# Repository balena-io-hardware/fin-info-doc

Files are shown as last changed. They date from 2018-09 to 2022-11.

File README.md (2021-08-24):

# balenaFin repository
Official documentation repository for the [balenaFin board](https://balenafin.io).  
Get it now from the official balenaFin [store](https://store.balena.io/).

## Directory structure

    .
    ├── documentation
    │   ├── CAD                          # 2d & 3D files for balenaFin and accessories
    │   ├── PDF                          # PDF files generated from markdown source using the builder
    │   └── markdown                     # balenaFin and accessories documentation source files
    ├── software                         # Linux config files for accessing balenaFin HW
    │   ├── dt-blob
    │   ├── overlay                      # Device tree overlay for Linux kernel
    │   └── drivers                      # Device drivers for radio, etc.
    ├── examples                         # Example code for the balenaFin
    ├── config.json                      # PDF generator files
    ├── index.js                         # PDF generator files
    └── package.json                     # PDF generator files

## Generated documentation

All files inside `documentation/CAD` and `documentation/PDF` are official balenaFin documentation. 
They are automatically generated from markdown files in `documentation/markdown`. 

## Building PDF releases

All PDF documentation is generated automatically from markdown files. To install the PDF generator, clone the repository and run `npm install`

`config.json` allows to define the document sources and their destination folder, along with custom overall styling

Once `config.json` is configured, run `npm start` to generate the PDF

### Project specific syntax

#### Page breaks

Creating a page-break on the destination PDF. 
It's important to leave a blank line above and below. 

```html

```

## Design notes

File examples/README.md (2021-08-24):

# balena-fin-examples
A collection of examples for balenaFin wrapped as a multi-container balenaCloud application. 
This collection will be improved with more examples over time, make sure to check it out from time to time!

deploy button (https://dashboard.balena-cloud.com/deploy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)

Service | What it does
------------ | ------------
wifi-connect | if the balenaFin is not connected, exposes a WiFi access point with Captive Portal ( SSID: `balenaFin`, PSK: `balenaFin`) that allows the configuration of WiFi credentials. 
For more info, please refer to the [wifi-connect repository](https://github.com/balena-io/wifi-connect)
rgb-led | blinks the balenaFin RGB LED with a random color every 3 seconds
artik020 | Loads OTA bluetooth bootloader to the Artik020 module and a sample application with BLE characteristics and the possibility to use OTA updates

## How to deploy this example to balenaCloud via git

```bash
git clone git@github.com:balena-io/balena-fin-examples.git
git remote add balena <YOUR_BALENA_USERNAME>@git.balena-cloud.com:<YOUR_BALENA_USERNAME>/<YOUR_BALENA_APP_NAME>.git
git push balena master
```
## How to deploy this example to balenaCloud via the balena CLI

1. Install [balena-cli](https://github.com/balena-io/balena-cli#standalone-install)
2. Deploy this application via [balena push](https://github.com/balena-io/balena-cli/blob/master/doc/cli.markdown#push-applicationordevice)

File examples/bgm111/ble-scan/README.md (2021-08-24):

# BLE Scan Example

Sample code to scan for advertising BLE devices and output the names of the advertisements over serial UART.

Note: this code only works with the balenaFin version v1.0.

## Contents

The firmware directory contains two files that are loaded in the Coprocessor's flash memory during set up.

`bootloader.s37` is the coprocessor bootloader. If this has not been flashed to the device beforehand, this will need to be flashed.

`ble-scan.hex` is an example that scans for advertising devices and shares them over serial UART.

To get started with this application, open the serial interface with `screen /dev/ttyUSB0 115200` and you should see the coprocessor printing out scanned BLE advertisements.

## Further Development

To develop custom applications for the coprocessor module it is recommended to download Simplicity Studio from Silicon labs website.
You can then uncompress the [ble-scan](/src/ble-scan.sls) file and import this into Simplicity Studio as a template project.

Notes:

- Make Sure you use EFR32BG1B232F256GM48 as the part number for the Artik020 module
- Make sure you use version 2.8 or newer of the `Gecko SDK Suite: Bluetooth`

### Documentation

To help aid further development here are some links to Silicon Labs documentation on the BLE SDK

- [BLE API Reference Manual](https://www.silabs.com/documents/public/reference-manuals/bluetooth-api-reference.pdf)

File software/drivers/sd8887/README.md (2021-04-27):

# SD8887 Driver and Firmware

### Information

This directory contains the source and instructions for building the wireless drivers/firmware for the sd8887 radio on the balenaFin (v1.x). The latest release of this driver is version `15.68.19.p48-15.26.19.p48` which targets the 5.4 Linux kernel.

This driver comes pre-installed under balenaOS and our custom Raspbian image for the balenaFin. The instructions below explain how to install both the driver and firmware against a standard Raspbian Lite (Stretch) image.

## Installation for Raspbian

We provide a pre-prepared [Raspbian Lite (Stretch)]() image with overlay and drivers installed, however we also provide instructions for how to install these drivers on a vanilla version of Raspbian OS. 

> :warning: Currently this driver only supports up to the 5.4 kernel. This means the driver does not support the latest version of Raspberry Pi OS (previously known as Raspbian) but we are working on it!

### Setup

1. Install latest [Raspbian Lite (Stretch)](https://downloads.raspberrypi.org/raspbian/images/raspbian-2019-04-09/2019-04-08-raspbian-stretch.zip) onto your balenaFin (v1.x). We recommend using [Etcher](https://www.balena.io/etcher/).

2. Enable `ssh` (create an `ssh` file in the `/boot` partition). 

3. Ensure that the `balena-fin` DT overlay has been set in `/boot/config.txt`. This should be included by default in the vanilla Raspbian image.

```bash
dtoverlay=balena-fin
```

4. Update, upgrade and install dependencies:
```bash 
sudo apt-get update && sudo apt-get upgrade
sudo apt-get install raspberrypi-kernel-headers build-essential bc git
```

5. Clone this repo and copy source
```bash
git clone https://github.com/balena-io-hardware/balena-fin.git
sudo cp balena-fin/software/drivers/sd8887/firmware/* /lib/firmware/nxp/
```

6. Create `/etc/modprobe.d/blacklist.conf` using the following snippet:

```bash
for mod in mwifiex mwifiex_sdio btmrvl btmrvl_sdio; do
    echo "blacklist ${mod}" >> /etc/modprobe.d/blacklist.conf
done
```

7. Reboot
 
```bash
sudo reboot now
```

### Configure NetworkManager and WiFi Connect

The WiFi Connect installation script will enable NetworkManager and install wifi-connect:

```bash
bash <(curl -L https://github.com/balena-os/wifi-connect/raw/master/scripts/raspbian-install.sh)
```

### Build WLAN driver

```bash
cd ~/balena-fin/software/drivers/sd8887/src/wlan
make -j 4 KERNELDIR=/usr/src/linux-headers-$(uname -r) build
cd ../bin_sd8887/
sudo modprobe cfg80211
sudo insmod mlan.ko
sudo insmod sd8887.ko cal_data_cfg=none drv_mode=1 sta_name=wlan ps_mode=2
```

### Verify WLAN driver is working

```bash
dmesg
sudo nmcli d wifi rescan ifname wlan0
nmcli d wifi
iw phy
iw dev
ip a
sudo wifi-connect -i wlan0
```

### Unload WLAN driver

```bash
sudo ip link set wlan0 down
sudo rmmod sd8xxx mlan
```

### Build Bluetooth driver

```bash
cd ~/balena-fin/software/drivers/sd8887/src/bluetooth
make -j 4 KERNELDIR=/usr/src/linux-headers-$(uname -r) build
cd ../bin_sd8887_bt/
sudo modprobe bluetooth
sudo insmod bt8887.ko
```

### Verify Bluetooth driver is working

```bash
sudo bluetoothctl
```

### Unload Bluetooth driver

```bash
sudo hciconfig hciX down
sudo rmmod bt8xxx
```

### Complete installation

```bash
sudo cp ~/balena-fin/software/drivers/sd8887/src/bin_sd8887/mlan.ko /lib/modules/$(uname -r)/kernel/drivers/net/wireless/nxp/mlan.ko
sudo cp ~/balena-fin/software/drivers/sd8887/src/bin_sd8887/sd8887.ko /lib/modules/$(uname -r)/kernel/drivers/net/wireless/nxp/sd8887.ko
sudo cp ~/balena-fin/software/drivers/sd8887/src/bin_sd8887_bt/bt8887.ko /lib/modules/$(uname -r)/kernel/drivers/bluetooth
sudo depmod
sudo touch /etc/modules-load.d/sd8887-nxp.conf
```

Edit `/etc/modules-load.d/sd8887-nxp.conf` like this:

```bash
mlan
sd8xxx
bt8xxx
```

Create and edit `/etc/modprobe.d/sd8887-nxp.conf` like this:

```bash
options sd8xxx cal_data_cfg=none drv_mode=1 sta_name=wlan ps_mode=2
```

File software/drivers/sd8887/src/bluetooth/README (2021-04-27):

===============================================================================
			U S E R  M A N U A L

 Copyright 2014-2020 NXP

 This software file (the File) is distributed by NXP
 under the terms of the GNU General Public License Version 2, June 1991
 (the License).  You may use, redistribute and/or modify the File in
 accordance with the terms and conditions of the License, a copy of which
 is available by writing to the Free Software Foundation, Inc.,
 51 Franklin Street, Fifth Floor, Boston, MA 02110-1301 USA or on the
 worldwide web at http://www.gnu.org/licenses/old-licenses/gpl-2.0.txt.

 THE FILE IS DISTRIBUTED AS-IS, WITHOUT WARRANTY OF ANY KIND, AND THE
 IMPLIED WARRANTIES OF MERCHANTABILITY OR FITNESS FOR A PARTICULAR PURPOSE
 ARE EXPRESSLY DISCLAIMED.  The License provides additional details about
 this warranty disclaimer.

===============================================================================

1) FOR DRIVER BUILD

	Goto source code directory mbt_src/.
		make [clean] build
	The driver binary can be found in ../bin_xxxx_bt directory.
	The driver code supports Linux kernel from 2.6.32 to 5.5.2.

2) FOR DRIVER INSTALL

	a) Copy sd8787.bin | ... to /lib/firmware/nxp/ directory,
	   create the directory if it doesn't exist.
	b) Install bluetooth driver,
		insmod bt8787.ko | mbt8787.ko | ... [fw_name=nxp/sd8xxx.bin]
	c) Uninstall bluetooth driver,
		hciconfig hciX down
		rmmod bt8xxx | mbt8xxx

	There are some other parameters for debugging purpose etc. Use modinfo to check details.
	  The bit settings of drv_mode are,
		Bit 0: BT/AMP/BLE
	  mbt_drvdbg=<bit mask of driver debug message control>
	  psmode=1|0 <enable PS mode (default) | disable PS mode>
	  dts_enable=1|0 <Disable DTS | Enable DTS (default)>
	  bt_name=<BT interface name>
	  mbt_pm_keep_power=1|0 <PM keep power in suspend (default) | PM no power in suspend>
	  fw=0|other <Skip firmware download | Download firmware (default)>
	  bt_req_fw_nowait=0|1 <use request_firmware API (default) | use request_firmware_nowait API>
	  init_cfg=<init config (MAC addresses, registers etc.) file name>
		e.g. copy bt_init_cfg.conf to firmware directory, init_cfg=nxp/bt_init_cfg.conf
      bt_mac=xx:xx:xx:xx:xx:xx <override the MAC address (in hex)>
      cal_cfg=<BT CAL data config file name>
		e.g. copy bt_cal_data.conf to firmware directory, cal_cfg=nxp/bt_cal_data.conf
      cal_cfg_ext=<CAL data config file name>
		e.g. copy cal_data.conf to firmware directory, cal_cfg_ext=nxp/cal_data.conf
      init_cmds=<init commands config file name>
		e.g. copy bt_init_cmds.conf to firmware directory, init_cmds=nxp/bt_init_cmds.conf

	  bt_fw_serial=0|1 <Support parallel download FW | Support serial download FW (default)>

	Note: On some platforms (e.g. PXA910/920) double quotation marks ("") need to used
	for module parameters.
		insmod bt8xxx.ko "<para1> <para2> ..."

3) cat /proc/mbt/hcix/status
	This command is used to get driver status.

4) cat /proc/mbt/hcix/config
	This command is used to get the current driver settings.

5) proc commands to config bluetooth parameters

mbt_drvdbg=[n]
	This command is used to set the bit mask of driver debug message control.

	bit 0:  MSG  		PRINTM(MSG,...)
	bit 1:  FATAL		PRINTM(FATAL,...)
	bit 2:  ERROR		PRINTM(ERROR,...)
	bit 3:  DATA 		PRINTM(DATA,...)
	bit 4:  CMD  		PRINTM(CMD,...)
	bit 5:  EVENT		PRINTM(EVENT,...)
	bit 6:  INTR		PRINTM(INTR,...)
	...
	bit 16: DAT_D		PRINTM(DAT_D,...), DBG_HEXDUMP(DAT_D,...)
	bit 17: CMD_D		PRINTM(CMD_D,...), DBG_HEXDUMP(CMD_D,...)
	...
	bit 28: ENTRY		PRINTM(ENTRY,...), ENTER(), LEAVE()
	bit 29: WARN 		PRINTM(WARN,...)
	bit 30: INFO 		PRINTM(INFO,...)

	Usage:
		echo "drvdbg=0x7" > /proc/mbt/hcix/config		#enable MSG,FATAL,ERROR messages

gpio_gap=[n]
	This command is used to configure the host sleep parameters.

	bit 8:0  -- Gap
	bit 16:8 -- GPIO
	where GPIO is the pin number of GPIO used to wakeup the host. It could be any valid
		GPIO pin# (e.g. 0-7) or 0xff (Interface, e.g. SDIO will be used instead).
	where Gap is the gap in milliseconds between wakeup signal and wakeup event
		or 0xff for special setting when GPIO is used to wakeup host.

	Usage:
		echo "gpio_gap=0xff80" > /proc/mbt/hcix/config   	# use Interface (e.g. SDIO)
		echo "hscfgcmd=1" > /proc/mbt/hcix/config		# gap = 0x80

		echo "gpio_gap=0x03ff" > /proc/mbt/hcix/config   	# use gpio 3
		echo "hscfgcmd=1" > /proc/mbt/hcix/config		# and special host sleep mode

psmode=[n]
	This command is used to enable/disable auto sleep mode

	where the option is:
			1 	-- Enable auto sleep mode
			0 	-- Disable auto sleep mode

	Usage:
		echo "psmode=1" > /proc/mbt/hcix/config			#enable power save mode
		echo "idle_timeout=0x0100" > /proc/mbt/hcix/config		#configure idle, timeout value in ms
		echo "pscmd=1" > /proc/mbt/hcix/config

		echo "psmode=0" > /proc/mbt/hcix/config			#disable power save mode
		echo "pscmd=1" > /proc/mbt/hcix/config

sdio_pull_cfg=[n]
	This command is used to configure the delay values for pull up and pull down the SDIO lines.

   	where value is:
	        bit 15:0  -- Pull up delay in microsecond
	        bit 31:16 -- Pull down delay in microsecond
	        0xffff disables PullUp and PullDown in BT controller

	Usage:
		echo "sdio_pull_cfg=0x00020002" > /proc/mbt/hcix/config   	# Enable sdio pull control
		echo "sdio_pull_ctrl=1" > /proc/mbt/hcix/config             # configure sdio pull up delay to 2 microseconds
                                                                    # configure sdio pull down delay to 2 microseconds

		echo "sdio_pull_cfg=0xffffffff" > /proc/mbt/hcix/config   	# Disable sdio pull control
		echo "sdio_pull_ctrl=1" > /proc/mbt/hcix/config

6) Use hcitool to issue raw hci command, refer to hcitool manual

	Usage: Hcitool cmd <ogf> <ocf> [Parameters]

	1.Interface Control Command
	  hcitool cmd 0x3f 0x5b 0xf5 0x01 0x00    --Enable All interface
	  hcitool cmd 0x3f 0x5b 0xf5 0x01 0x01    --Enable Wlan interface
	  hcitool cmd 0x3f 0x5b 0xf5 0x01 0x02    --Enable BT interface
	  hcitool cmd 0x3f 0x5b 0xf5 0x00 0x00    --Disable All interface
	  hcitool cmd 0x3f 0x5b 0xf5 0x00 0x01    --Disable Wlan interface
	  hcitool cmd 0x3f 0x5b 0xf5 0x00 0x02    --Disable BT interface

7) cat /proc/mbt/hcix/debug
	This command is used to get driver debug parameters.

8) proc command to config debug parameters

sdcmd52rw=<func> <reg> [data]
	This command is used to read/write a controller register in
	Secure Digital I/O Interfaces.

	func: The function number to use (0-7)
	reg:  The address of the register
	data: The value to write, read if the value is absent

	For SDIO MMC driver, only function 0 and BT function (2/3) access is allowed.
	And there is a limitation for function 0 write, only vendor specific CCCR
	registers (0xf0 -0xff) are permiited.

	Usage:
		echo "sdcmd52rw= 2 3 0xf" > /proc/mbt/hcix/debug	# write 0xf to func 2 address 3
		echo "sdcmd52rw= 0 4" > /proc/mbt/hcix/debug    	# read func 0 address 4

Issue debug_dump command through proc.
	Usage:
		echo "debug_dump" > /proc/mbt/hcix/debug		# dump driver internal debug status.
	Use dmesg or cat /var/log/debug to check driver debug messages.

proc command to enable BT test mode
    Usage:
        echo "test_mode=1" > /proc/mbt/hcix/config       #enable BT test mode

==============================================================================
			U S E R  M A N U A L  F O R  F M A P P

1) FOR TOOL BUILD

	a) Enter directory
	b) make
	c) After building, the executable binary "fmapp" is in the directory

2) FOR TOOL RUN

	a) chmod 777 fmapp (optional)
	b) Run fmapp utility based on usage below
		Usage: fmapp <Options> devicename ogf ocf [command content]
		devicename example: mfmchar0 /mnfccahr0
		FM ogf/ocf example: 0x3f 0x280
		NFC ogf/ocf example: 0x3f 0x281
	Options:
		-h: Display help
		-v: Verbose

3) TEST EXAMPLES
    ./fmapp mfmchar0 0x3f 0x280 0x01 0x01
    ./fmapp mnfcchar0 0x3f 0x281 0x20 0x00 0x01 0x01

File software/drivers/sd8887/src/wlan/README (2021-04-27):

===============================================================================
			U S E R  M A N U A L

 Copyright 2014-2020 NXP

1) FOR DRIVER BUILD

	Goto source code directory wlan_src/.
	make [clean] build
	The driver and utility binaries can be found in ../bin_xxxx directory.
	The driver code supports Linux kernel from 2.6.32 to 5.5.2.

2) FOR DRIVER INSTALL

	a) Copy firmware image sd8786_uapsta.bin | sd8787_uapsta.bin | ... to
	   /lib/firmware/nxp/ directory, create the directory if it doesn't exist.
	b) Install WLAN driver,
	   There are drv_mode, max_sta_bss, max_uap_bss etc. module parameters.
		The bit settings of drv_mode are,
			Bit 0 :  STA
			Bit 1 :  uAP
			Bit 2 :  WIFIDIRECT
		The default drv_mode is 7.
			Bit 4 :  NAN

		max_sta_bss: Maximum number of STA BSS (default 1, max 1)
		sta_name: Name of the STA interface (default: "mlan")
		max_uap_bss: Maximum number of uAP BSS (default 1, max 2)
		uap_name: Name of the uAP interface (default: "uap")
		uap_max_sta: Maximum number of STA for UAP/GO (default 0, max 10)
		max_wfd_bss: Maximum number of WIFIDIRECT BSS (default 1, max 1)
		wfd_name: Name of the WIFIDIRECT interface (default: "wfd")
		max_vir_bss: Number of Virtual interfaces (default 0)
		nan_name: Name of the NAN interface (default: "nan")
		max_nan_bss: Number of NAN interfaces (default 1)
	   For example, to install SD8787 driver,
		insmod mlan.ko
		insmod sd8787.ko [drv_mode=3] [fw_name=nxp/sd8787_uapsta.bin]
	   To load driver in STA only mode,
		insmod mlan.ko
		insmod sd8787.ko drv_mode=1 [fw_name=nxp/sd8787_uapsta.bin]
	   To load driver in uAP only mode,
		insmod mlan.ko
		insmod sd8787.ko drv_mode=2 [fw_name=nxp/sd8787_uapsta.bin]

	   To switch mode between STA only, uAP only and uAPSTA etc. in run time,
		echo drv_mode=1 > /proc/mwlan/config		// STA mode
		echo drv_mode=2 > /proc/mwlan/config		// uAP mode
		echo drv_mode=3 > /proc/mwlan/config		// STA+uAP mode
		echo drv_mode=7 > /proc/mwlan/config		// STA+uAP+WIFIDIRECT mode
	c) Uninstall WLAN driver,
		ifconfig mlanX down
		ifconfig uapX down
		rmmod sd8xxx
		rmmod mlan

	Use mfg_mode = 1:
	To load driver with MFG firmware file, when insmod WLAN driver and specify MFG firmware name if needed.
	This option loads default normal FW on HW reset (reset button is pressed on the board).

	Use mfg_mode = 2:
	To load driver with MFG firmware file, when insmod WLAN driver and specify MFG firmware name if needed.
	This option reloads previously specifed MFG firmware only on HW reset.

	There are some other parameters for debugging purpose etc. Use modinfo to check details.
	  drvdbg=<bit mask of driver debug message control>
	  dev_cap_mask=<Bit mask of the device capability>
	  mac_addr=xx:xx:xx:xx:xx:xx <override the MAC address (in hex)>
	  auto_ds=0|1|2 <use MLAN default | enable auto deepsleep | disable auto deepsleep>
	  ps_mode=0|1|2 <use MLAN default | enable IEEE PS mode | disable IEEE PS mode>
	  p2p_enh=0|1 <Disable enhanced P2P (default) | Enable enhanced P2P>
	  max_tx_buf=2048|4096|8192 <maximum AMSDU Tx buffer size>
	  pm_keep_power=1|0 <PM keep power in suspend (default) | PM no power in suspend>
	  shutdown_hs=1|0 <Enable HS when shutdown | No HS when shutdown (default)>
	  cfg_11d=0|1|2 <use MLAN default | enable 11d | disable 11d>
	  dts_enable=0|1 <Disable DTS | Enable DTS (default)>
	  hw_test=0|1 <Disable hardware test (default) | Enable hardware test>
	  fw_serial=0|1 <support parallel download FW | support serial download FW (default)>
	  req_fw_nowait=0|1 <use request_firmware API (default) | use request_firmware_nowait API>
	  slew_rate=0|1|2|3 <0 is the slowest slew rate and 03 has the highest slew rate (default)>
	  antcfg=0|1|2|0xffff <default | Tx/Rx antenna 1 | Tx/Rx antenna 2 | enable antenna diversity>
	  init_cfg=<init config (MAC addresses, registers etc.) file name>
		e.g. copy init_cfg.conf to firmware directory, init_cfg=nxp/init_cfg.conf
	  cal_data_cfg=<CAL data config file name>
		e.g. copy cal_data.conf to firmware directory, cal_data_cfg=nxp/cal_data.conf
	  txpwrlimit_cfg=<Tx power limit config file name>
		e.g. copy txpwrlimit_cfg_set.conf to firmware directory, txpwrlimit_cfg=nxp/txpwrlimit_cfg_set.conf
	  init_hostcmd_cfg=<init hostcmd config file name>
		e.g. copy init_hostcmd_cfg.conf to firmware directory, init_hostcmd_cfg=nxp/init_hostcmd_cfg.conf
	  sdio_rx_aggr=1|2 <Enable SDIO rx aggr (default) | Disable SDIO rx aggr>
	  cfg80211_wext=<bit mask of CFG80211 and WEXT control>
		Bit 0: STA WEXT
		Bit 1: uAP WEXT
		Bit 2: STA CFG80211
		Bit 3: uAP CFG80211
	cfg80211_drcs=1|0 <Enable DRCS support | Disable DRCS support (default)>
	  reg_alpha2=<Regulatory alpha2 (default NULL)>
	  wq_sched_prio: Priority for work queue
	  wq_sched_policy: Scheduling policy for work queue
		(0: SCHED_NORMAL, 1: SCHED_FIFO, 2: SCHED_RR, 3: SCHED_BATCH, 5: SCHED_IDLE)
		Please note that, both wq_sched_prio and wq_sched_policy should be provided
		as module parameters. If wq_sched_policy is (0, 3 or 5), then wq_sched_prio
		must be 0. wq_sched_prio should be 1 to 99 otherwise.
	  rx_work=0|1|2 <default | Enable rx_work_queue | Disable rx_work_queue>
	  low_power_mode_enable=0|1 <disable low power mode (default)| enable low power mode>
	  When low power mode is enabled, the output power will be clipped at ~+10dBm and the
	  expected PA current is expected to be in the 80-90 mA range for b/g/n modes

	Note: On some platforms (e.g. PXA910/920) double quotation marks ("") need to used
	for module parameters.
		insmod sd8xxx.ko "<para1> <para2> ..."

3) FOR DRIVER PROC & DEBUG

	The following info are provided in /proc/net/mwlan/mlanX/info,
	on kernel 2.6.24 or later, the entry is /proc/mwlan/mlanX/info.

	driver_name = "wlan"
	driver_version = <chip id, firmware version and driver version>
	interface_name = "mlanX"
	bss_mode = "Ad-hoc" | "Managed" | "Auto" | "Unknown"
	media_state = "Disconnected" | "Connected"
	mac_address = <6-byte adapter MAC address>
	multicase_count = <multicast address count>
	essid = <current SSID>
	bssid = <current BSSID>
	channel = <current channel>
	region_code = <current region code>
	multicast_address[n] = <multicast address>
	num_tx_bytes = <number of bytes sent to device>
	num_rx_bytes = <number of bytes received from device and sent to kernel>
	num_tx_pkts = <number of packets sent to device>
	num_rx_pkts = <number of packets received from device and sent to kernel>
	num_tx_pkts_dropped = <number of Tx packets dropped by driver>
	num_rx_pkts_dropped = <number of Rx packets dropped by driver>
	num_tx_pkts_err = <number of Tx packets failed to send to device>
	num_rx_pkts_err = <number of Rx packets failed to receive from device>
	carrier "on" | "off"
	tx queue "stopped" | "started"

	The following debug info are provided in /proc/net/mwlan/mlanX/debug,
	on kernel 2.6.24 or later, the entry is /proc/mwlan/mlanX/debug.

	drvdbg = <bit mask of driver debug message control>
	wmm_ac_vo = <number of packets sent to device from WMM AcVo queue>
	wmm_ac_vi = <number of packets sent to device from WMM AcVi queue>
	wmm_ac_be = <number of packets sent to device from WMM AcBE queue>
	wmm_ac_bk = <number of packets sent to device from WMM AcBK queue>
	max_tx_buf_size = <maximum Tx buffer size>
	tx_buf_size = <current Tx buffer size>
	curr_tx_buf_size = <current Tx buffer size in FW>
	ps_mode = <0/1, CAM mode/PS mode>
	ps_state = <0/1/2/3, awake state/pre-sleep state/sleep-confirm state/sleep state>
	is_deep_sleep = <0/1, not deep sleep state/deep sleep state>
	wakeup_dev_req = <0/1, wakeup device not required/required>
	wakeup_tries = <wakeup device count, cleared when device awake>
	hs_configured = <0/1, host sleep not configured/configured>
	hs_activated = <0/1, extended host sleep not activated/activated>
	tx_pkts_queued = <number of Tx packets queued>
	pps_uapsd_mode = <0/1, PPS/UAPSD mode disabled/enabled>
	sleep_pd = <sleep period in milliseconds>
	qos_cfg = <WMM QoS info>
	tx_lock_flag = <0/1, Tx lock flag>
	port_open = <0/1, port open flag>
	scan_processing = <0/1, scan processing flag>
	num_tx_timeout = <number of Tx timeout>
	num_cmd_timeout = <number of timeout commands>
	timeout_cmd_id = <command id of the last timeout command>
	timeout_cmd_act = <command action of the last timeout command>
	last_cmd_id = <command id of the last several commands sent to device>
	last_cmd_act = <command action of the last several commands sent to device>
	last_cmd_index = <0 based last command index>
	last_cmd_resp_id = <command id of the last several command responses received from device>
	last_cmd_resp_index = <0 based last command response index>
	last_event = <event id of the last several events received from device>
	last_event_index = <0 based last event index>
	num_cmd_h2c_fail = <number of commands failed to send to device>
	num_cmd_sleep_cfm_fail = <number of sleep confirm failed to send to device>
	num_tx_h2c_fail = <number of data packets failed to send to device>
	num_cmdevt_c2h_fail = <number of commands/events failed to receive from device>
	num_rx_c2h_fail = <number of data packets failed to receive from device>
	num_int_read_fail = <number of interrupt read failures>
	last_int_status = <last interrupt status>
	num_evt_deauth = <number of deauthenticated events received from device>
	num_evt_disassoc = <number of disassociated events received from device>
	num_evt_link_lost = <number of link lost events received from device>
	num_cmd_deauth = <number of deauthenticate commands sent to device>
	num_cmd_assoc_ok = <number of associate commands with success return>
	num_cmd_assoc_fail = <number of associate commands with failure return>
	cmd_sent = <0/1, send command resources available/sending command to device>
	data_sent = <0/1, send data resources available/sending data to device>
	mp_rd_bitmap = <SDIO multi-port read bitmap>
	curr_rd_port = <SDIO multi-port current read port>
	mp_wr_bitmap = <SDIO multi-port write bitmap>
	curr_wr_port = <SDIO multi-port current write port>
	cmd_resp_received = <0/1, no cmd response to process/response received and yet to process>
	event_received = <0/1, no event to process/event received and yet to process>
	ioctl_pending = <number of ioctl pending>
	tx_pending = <number of Tx packet pending>
	rx_pending = <number of Rx packet pending>
	lock_count = <number of lock used>
	malloc_count = <number of malloc done>
	mbufalloc_count = <number of mlan_buffer allocated>
	main_state = <current state of the main process>
	sdiocmd53w = <SDIO Cmd53 write status>
	sdiocmd53r = <SDIO Cmd52 read status>
	hs_skip_count = <number of skipped suspends>
	hs_force_count = <number of forced suspends>

	Issue SDIO cmd52 read/write through proc.
	Usage:
		echo "sdcmd52rw=<func> <reg> [data]" > /proc/mwlan/config
	where the parameters:
		func: The function number to use (0-7)
		reg:  The address of the register
		data: The value to write, read if the value is absent
		For SDIO MMC driver, only function 0 and WLAN function access is allowed.
		And there is a limitation for function 0 write, only vendor specific CCCR
		registers (0xf0 -0xff) are permiited.
	Examples:
		echo "sdcmd52rw= 0 4" > /proc/mwlan/config      # read func 0 address 4
		cat /proc/mwlan/config                          # display the register value
		echo "sdcmd52rw= 1 3 0xf" > /proc/mwlan/config  # write 0xf to func 1 address 3

	Use dmesg or cat /var/log/debug to check driver debug messages.
	To log driver debug messages to file,
	a) Edit /etc/syslog.conf, add one line "*.debug		/var/log/debug"
	   on kernel 2.6.24 or later, edit /etc/rsyslog.conf instead
	b) touch /var/log/debug (if the file doesn't exist)
	c) service syslog restart
	   on kernel 2.6.24 or later, service rsyslog restart

	Update /proc/sys/kernel/printk to change message log levels.
	For example,
	echo 6 > /proc/sys/kernel/printk    (messages with a higher priority than 6
	                                     will be printed to the console)
	echo 15 > /proc/sys/kernel/printk   (all messages will be printed to console)

4) FOR IWPRIV COMMAND

NAME
	This manual describes the usage of private commands used in NXP MLAN
	Linux Driver.

	To use parameters as hex format, a '0x' must precede it for the parameters to
	be parsed properly.

SYNOPSIS
	iwpriv <mlanX> <command> [sub-command] ...

	iwpriv mlanX version
	iwpriv mlanX verext
	iwpriv mlanX getsignal [m] [n]
	iwpriv mlanX antcfg [m]
	iwpriv mlanX regioncode [n]
	iwpriv mlanX cfpcode [m] [n]
	iwpriv mlanX wwscfg [m]
	iwpriv mlanX esuppmode
	iwpriv mlanX passphrase <ssid/psk/passphrase>
	iwpriv mlanX httxcfg [<m>] [<n>]
	iwpriv mlanX htcapinfo [<m>] [<n>]
	iwpriv mlanX addbapara <m> <n> <o> <p> <q>
	iwpriv mlanX aggrpriotbl <n>
	iwpriv mlanX addbareject <n>
	iwpriv mlanX txbufcfg
	iwpriv mlanX amsduaggrctrl <n>
	iwpriv mlanX httxbfcap [cap]
	iwpriv mlanX httxbfcfg "<action>[;GlobalData/tsData/interval/txPeerData/snrData]"
	iwpriv mlanX mpactrl [tx_ena] [rx_ena] [tx_size] [rx_size] [tx_ports] [rx_ports]
	iwpriv mlanX deepsleep [n] [m]
	iwpriv mlanX hscfg [condition [[GPIO# [gap]]]]
	iwpriv mlanX hssetpara condition [GPIO# [gap]]
	iwpriv mlanX deauth [n]
	iwpriv mlanX radioctrl
	iwpriv mlanX reassoctrl [n]
	iwpriv mlanX bandcfg [l] [m] [n]
	iwpriv mlanX getlog
	iwpriv mlanX 11dcfg
	iwpriv mlanX 11dclrtbl
	iwpriv mlanX wmmcfg [n]
	iwpriv mlanX txpowercfg [<RateIndex> [<MinPwr> [<MaxPwr> <step>]]]
	iwpriv mlanX qoscfg
	iwpriv mlanX getdatarate
	iwpriv mlanX txratecfg [n]
	iwpriv mlanX bcninterval [n]
	iwpriv mlanX sysclock [clk1] [clk2] [clk3] [clk4]
	iwpriv mlanX drvdbg [n]
	iwpriv mlanX mgmtframectrl
	iwpriv mlanX warmreset
	iwpriv mlanX regrdwr <type> <offset> [value]
	iwpriv mlanX rdeeprom <offset> <length>
	iwpriv mlanX memrdwr <address> [value]
	iwpriv mlanX inactivityto <n> <m> <l> [k]
	iwpriv mlanX sdioclock <n>
	iwpriv mlanX sdcmd52rw <FN no.> <address> [data]
	iwpriv mlanX scancfg [t] [m] [p] [s] [a] [b] [ext]
	iwpriv mlanX sleeppd [n]
	iwpriv mlanX pscfg [k] [d] [l] ...
        iwpriv mlanX fwwakeupmethod [n] [g]
	iwpriv mlanX associate "<bssid> <ssid>"
	iwpriv mlanX sleepparams [<p1> <p2> <p3> <p4> <p5> <p6>]
	iwpriv mlanX authtype [n]
	iwpriv mlanX powercons [n]
	iwpriv mlanX ipaddr ["<op>;<ipaddr>"]
	iwpriv mlanX macctrl [n]
	iwpriv mlanX dfstesting [<user_cac_pd> <user_nop_pd> <no_chan_change> <fixed_chan_num>]

DESCRIPTION
	Those commands are used to send additional commands to the NXP MLAN
	card via the Linux device driver.

	The mlanX parameter specifies the network device that is to be used to
	perform this command on. It could be mlan0, mlan1 etc.

version
	This is used to get the current version of the driver and the firmware.

verext
	Retrieve and display an extended version string from the firmware

	Usage:
		iwpriv mlanX verext [#]

	where [#] is an optional argument to retrieve a specific version string,
	omission of the argument retrieves the 0 indexed string.

getsignal
	This command gets the last and average value of RSSI, SNR and NF of
	Beacon and Data.
	Note: This command is available only when STA is connected.

	where value of m is:
		1   -- RSSI (Receive Signal Strength Indication)
		2   -- SNR (Signal to Noise Ratio)
		3   -- NF (Noise Floor)
	where value of n is:
		1   -- Beacon last
		2   -- Beacon average
		3   -- Data last
		4   -- Data average

	Examples:
		iwpriv mlan0 getsignal 1        : Get the RSSI info (beacon last, beacon
		                                  average, data last and data average)
		iwpriv mlan0 getsignal 3 4      : Get the NF of data average
		iwpriv mlan0 getsignal 2 1      : Get the SNR of beacon last
		iwpriv mlan0 getsignal          : Get all of the signal info
		mlan0     getsignal:-32  -33  -35  -36  67  59  63  56  -99  -92  -98  -92
		RSSI info: beacon last -32, beacon average -33, data last -35, data average -36
		SNR info: beacon last 67, beacon average 59, data last 63, data average 56
		NF info: beacon last -99, beacon average -92, data last -98, data average -92

antcfg
	This command is used to set/get the mode of Tx/Rx antenna.

	where value of m is:
		Bit 0   -- Tx/Rx antenna 1
		Bit 1   -- Tx/Rx antenna 2
		...
		0xFFFF  -- Tx/Rx antenna diversity

	Examples:
		iwpriv mlan0 antcfg             : Get Tx/Rx antenna mode
		iwpriv mlan0 antcfg 1           : Set Tx/Rx antenna 1
		iwpriv mlan0 antcfg 0xFFFF      : Set Tx/Rx antenna diversity

regioncode
	This command is used to set/get the region code in the station.
	Note: This command should be issued at beginning before band/channel selection
	and association.

	where value is 'region code' for various regions like
	USA FCC, Canada IC, Europe ETSI, Japan ...
	The special code (0xff) is used for Japan to support channel 1-14 in B/G/N mode.

	Examples:
		iwpriv mlan0 regioncode         : Get region code
		iwpriv mlan0 regioncode 0x10    : Set region code to USA (0x10)

	Note : in some case regioncode will be 0 after updated countycode or 80211d
		i.e. mlanutl mlanX countrycode  (CA, JP, CN, DE, ES AT, BR, RU)
		or uaputl.exe sys_cfg_80211d state 1 country (CA, JP, CN, DE, ES AT, BR, RU)
		Please use cfp instead of it.

cfpcode
	This command is used to set/get the Channel-Frequency-Power table codes.
	The region table can be selected through region code.
	The current configuration is returned if no parameter provided.

	where the parameters are,
		[m]: code of the CFP table for 2.4GHz (0: unchanged)
		[n]: code of the CFP table for 5GHz (0 or not provided: unchanged)

	Examples:
		iwpriv mlan0 cfpcode            : Get current configuration
		iwpriv mlan0 cfpcode 0x30       : Set 2.4GHz CFP table code 0x30 (EU),
		                                  keep 5GHz table unchanged
		iwpriv mlan0 cfpcode 0x10 5     : Set 2.4GHz CFP table code 0x10 (USA)
		                                  and 5GHz table code 5

wwscfg
	This command is used to set/get the WWS (World Wide Safe) mode.

	where value of m is:
		0       -- Disable WWS mode (default)
		1       -- Enable WWS mode

	Examples:
		iwpriv mlan0 wwscfg             : Get WWS mode
		iwpriv mlan0 wwscfg 1           : Enable WWS mode
		iwpriv mlan0 wwscfg 0           : Disable WWS mode

esuppmode
	This command is used to get the current RSN mode and active pairwise/group
    cipher for WPA/WPA2 mode.
	Note: This command is available only when STA is connected.

	These are bits settings used to indicate each RSN mode.
		Bit 0    : No RSN
		Bit 1-2  : RFU
		Bit 3    : WPA
		Bit 4    : WPA-NONE
		Bit 5    : WPA2
		Bit 6    : AES
		Bit 7-15 : RFU

	These are bits settings used to indicate each pairwise and group cipher.
		Bit 0    : RFU
		Bit 1    : RFU
		Bit 2    : TKIP
		Bit 3    : AES
		Bit 2-7  : RFU

	Example:
		iwpriv mlan0 esuppmode          : Get RSN mode and pairwise/group cipher
		8 4 4
		(The current RSN mode is WPA, active pairwise cipher is TKIP and
		 active group cipher is TKIP.)

passphrase
	This command is used to set/get passphrase for WPA-PSK/WPA2-PSK mode.

	Where <n>
		ASCII string for ssid/passphrase/psk.

	1) "0;<ssid=valid ssid>" - This will get the passphrase, AKMP
	   for specified ssid, if none specified then it will get all.

	Example:
		iwpriv mlan0 passphrase "0;ssid=nxp"

	2) "1;<psk=64 byte hexpsk>;<passphrase=1-63 byte passphare>
	   <ssid=valid ssid>" - Passphrase and psk cannot be provided for the same SSID.
	   This command takes only one SSID at a time, If ssid= is present it should contain
	   a passphrase or psk. If no arguments are provided then AKMP=802.1x, and passphrase
	   should be provided after association.
	   End of each parameter should be followed by a ';'(except for the last parameter)
	   as the delimiter. If ';' or '/' has to be used in an SSID then a '/' should be preceded
	   to ';' or '/' as a escape.

	Examples:
		iwpriv mlan0 passphrase "1;ssid=nxpAP;passphrase=abcdefgd"
		iwpriv mlan0 passphrase "1;ssid=nxp AP;psk=<64 bytes hexpsk>"

		If user wants to input the ssid as "nxp; AP" then command has to be
		iwpriv mlan0 passphrase "1;ssid=nxp/; AP;passphrase=abcdefgh"

		If user wants to input the ssid as "//;" then command has to be
		iwpriv mlan0 passphrase "1;ssid=/////;;passphrase=abcdefgh"

	3) "2;<ssid=valid ssid>" - This will clear the passphrase
	   for specified ssid, if none specified then it will clear all.

	Examples:
		iwpriv mlan0 passphrase "2;ssid=nxp"
		iwpriv mlan0 passphrase "2"     : Clear all profiles and disable embedded supplicant

httxcfg
	This command is used to configure various 11n specific configuration
	for transmit (such as Short GI, Channel BW and Green field support)

	where <m> is <txcfg>
	This is a bitmap and should be used as following
		Bit 15-8: Reserved set to 0
		Bit 7: STBC enable/disable
		Bit 6: Short GI in 40 Mhz enable/disable
		Bit 5: Short GI in 20 Mhz enable/disable
		Bit 4: Green field enable/disable
		Bit 3-2: Reserved set to 1
		Bit 1: 20/40 Mhz enable disable.
		Bit 0: LDPC enable/disable

	When Bit 1 is set then firmware could transmit in 20Mhz or 40Mhz based
	on rate adaptation. When this bit is reset then firmware will only
	transmit in 20Mhz.

	where <n> is <band>
	<band> - This is the band info for <txcfg> settings.
		0: Settings for both 2.4G and 5G bands
		1: Settings for 2.4G band
		2: Settings for 5G band

	Examples:
		iwpriv mlanX httxcfg
		This will display HT Tx configuration.
		If the configurations for 2.4G and 5G are different,
		the first value is for 2.4G and the second value is for 5G.
		Otherwise, it will display a single value for both bands.

		iwpriv mlanX httxcfg 0x62
		This will enable 20/40 and Short GI but will disable Green field for 2.4G and 5G band.

		iwpriv mlanX httxcfg 0x30 1
		This will enable Short GI 20 Mhz and Green field for 2.4G band.

	The default value is 0x20 for 2.4G and 0x62 for 5G.

	Note:- If 20/40 MHz support is disabled in htcapinfo, device will not transmit
	in 40 MHz even 20/40 MHz is enabled in httxcfg.

htcapinfo
	This command is used to configure some of parameters in HTCapInfo IE
	(such as Short GI, Channel BW, and Green field support)

	where <m> is <capinfo>
	<capinfo> - This is a bitmap and should be used as following
		Bit 29: Green field enable/disable
		Bit 26: Rx STBC Support enable/disable. (As we support
			single spatial stream only 1 bit is used for Rx STBC)
		Bit 24: Short GI in 40 Mhz enable/disable
		Bit 23: Short GI in 20 Mhz enable/disable
		Bit 17: 20/40 Mhz enable disable.
		Bit  8: Enable/disable 40Mhz Intolarent bit in ht capinfo.
		        0 will reset this bit and 1 will set this bit in
		        htcapinfo attached in assoc request.
		All others are reserved and should be set to 0.

	Setting of any other bits will return error.

	where <n> is <band>
	<band> - This is the band info for <capinfo> settings.
		0: Settings for both 2.4G and 5G bands
		1: Settings for 2.4G band
		2: Settings for 5G band

	Examples:
		iwpriv mlanX htcapinfo
		This will display HT capabilties information.
		If the information for 2.4G and 5G is different,
		the first value is for 2.4G and the second value is for 5G.
		Otherwise, it will display a single value for both bands.

		iwpriv mlanX htcapinfo 0x1820000
		This will enable Short GI, Channel BW to 20/40 and disable Green field support for 2.4G and 5G band.

		iwpriv mlanX htcapinfo 0x800000 2
		This will enable Short GI, Channel BW to 20 only, No Rx STBC support and disable Green field support for 5G band.

	The default value is 0x4800000 for 2.4G and 0x5820000 for 5G.

	Note:- This command can be issued any time but it will only come to effect from
	next association. (as HTCapInfo is sent only during Association).

addbapara
	This command can be used to update the default ADDBA parameters.

	where <m> is <timeout>
	<timeout> - This is the block ack timeout for ADDBA request.
		0 : Disable (recommended for throughput test)
		1 - 65535 : Block Ack Timeout in TU

	where <n> is <txwinsize>
	<txwinsize> - Window size for ADDBA request. (16 is recommended and default value)

	where <o> is <rxwinsize>
	<rxwinsize> - Window size for ADDBA response. (48 is recommended and 32 is default value)
	              (16 is recommended for IWNCOMM AP in WAPI throughput test)

	Current window size limit for Tx as well as Rx is 1023.

	where <p> is <txamsdu>
	<txamsdu> - amsdu support for ADDBA request. (1 is default value)
            0: disable amsdu in ADDBA request
            1: enable amsdu in ADDBA request

	where <q> is <rxamsdu>
	<rxamsdu> - amsdu support for ADDBA response. (1 is default value)
            0: disable amsdu in ADDBA response
            1: enable amsdu in ADDBA response

	eg:
	iwpriv mlanX addbapara - This command will get the current addba params
	iwpriv mlanX addbapara 1000 64 8 0 0 - This will change the ADDBA timeout to (1000 * 1024) us,
			txwinsize to 64 and rxwinsize to 8 and disable amdsu in ADDBA request/response.

	The default setting is 65535 16 32 1 1.

	In case the ADDBA timeout value is updated then a ADDBA is sent for all streams
	to update the timeout value.

	In case txwinsize and/or rxwinsize is updated, the effect could only be seen on
	next ADDBA request/response. The current streams will not be affected with this
	change.

	In case of txamsdu/rxamsdu is updated, the effect could only be seen on
	next ADDBA request/response. The current streams will not be affected with this
	change. AMSDU in AMPDU stream will be enabled when AP support this feature
	and AMSDU is enabled in aggrpriotbl.

aggrpriotbl
	This command is used set/get the priority table for AMPDU/AMSDU traffic per tid.
	This command can also be used to disable AMPDU/AMSDU for a given tid.
	In case of AMPDU this priority table will be used to setup block ack (to make
	sure the highest priority tid always uses AMPDU as we have limited AMPDU streams)

	where <m0> <n0> <m1> <n1> ... <m7> <n7>

	<mx> - This is priority for Tid0 for AMPDU packet. A priority could be any
		   values between 0 - 7, 0xff to disable aggregation.
	<nx> - This is priority for Tid0 for AMSDU packet. A priority could be any
		   values between 0 - 7, 0xff to disable aggregation.

	eg:
	iwpriv mlanX aggrpriotbl - This command will get the current Priority table for AMPDU and AMSDU.
						  <2 2 0 0 1 1 3 3 4 4 5 5 255 255 255 255>. This is read as
						  <"Prio for AMPDU for Tid0" "Prio for AMSDU for Tid0"
						   "Prio for AMPDU for Tid1" "Prio for AMSDU for Tid1" and so on
	iwpriv mlanX aggrpriotbl 2 2 0 0 1 1 3 3 4 4 5 5 255 255 255 255 -
						This will set the priority table for AMPDU and AMSDU
						Priority for Tid0/AMPDU = 2, Tid0/AMSDU = 2, Tid1/AMPDU = 0, Tid1/AMSDU = 0
						and so on. Aggregation for Tid6 and Tid7 are disabled.
						Here higher the priority number, higher the priority (i.e. 7
						has higher priority than 6). Similarly for AMSDU.
	iwpriv mlanX aggrpriotbl 0xff 2 0xff 0 0xff 1 0xff 3 0xff 4 0xff 5 0xff 0xff 0xff 0xff - This will disable
						AMPDU for all the TIDs but will still keep AMSDU enabled to Tid0 to Tid5

	The default setting is 2 255 0 255 1 255 3 255 4 255 5 255 255 255 255 255.

	A delBA should be seen in case a disable happens on a TID for which AMPDU stream
	is currently setup.

	Note:- This command should only be issue in disconnected state.

addbareject
	This command is used set/get the addbareject table for all the TIDs.
	This command can also be used to enable rejection of ADDBA requests for a given tid.

	where <m0> <m1> ... <m7>

	<mX> - This can be 0/1 for TidX. 1 enables rejection of ADDBA request for TidX and
		   0 would accept any ADDBAs for TidX.

	eg:
	iwpriv mlanX addbareject - This command will get the current table.
	    [0 0 0 0 0 0 0 0]. ADDBA would be accepted for all TIDs. This is the default state.

	iwpriv mlanX addbareject 0 0 1 1 0 0 0 0 - This command will accept ADDBA requests for
		Tid [0,1,4,5,6,7] and reject ADDBA requests for Tid [2,3]

	iwpriv mlanX addbareject 1 1 1 1 1 1 1 1 - This will enable rejection of ADDBA requests for
		all Tids.

	Note:- This command should only be issue in disconnected state.

txbufcfg
	This command can be used to get current buffer size.

	eg:
	iwpriv mlanX txbufcfg 	  - This will display the current buffer size.

	Note:- The actual tx buf size will depends on AP's capability and max transmit buffer size.

amsduaggrctrl
	This command could be used to enable/disable a feature where firmware gives feedback to driver
	regarding the optimal AMSDU buffer size to use with the current rate. Firmware will use the
	current rate to decide the buffer size we could transmit. The max buffer size will still be
	limited by buffer size provided in txbufcfg. (i.e. if the txbufcfg is 4K, then we could only transmit
	4K/2K AMSDU packets, if the txbufcfg is 8K then we could transmit 8k/4k/2k based on current rate)

	If enabled AMSDU buffer size at various rates will be as follows

	1.	Legacy B/G rate.
		No AMSDU aggregation.

	2.	BW20 HT Rate:
		When TX rate goes down,
		MCS 7, 6, 5, 4:
			a	8K aggregation size (if TX buffer size is 8K)
			b	4K aggregation size (if TX buffer size is 4K)
			c	2K aggregation size (if TX buffer size is 2K)

		MCS 3, 2:
			a	4K aggregation size (if TX buffer size is 8K/4K)
			b	2K aggregation size (if TX buffer size is 2K)

		MCS 1, 0:
			a	No aggregation

		When TX rate goes up,
		MCS 7, 6, 5:
			a	8K aggregation size (if TX buffer size is 8K)
			b	4K aggregation size (if TX buffer size is 4K)
			c	2K aggregation size (if TX buffer size is 2K)

		MCS 4, 3:
			a	4K aggregation size (if TX buffer size is 8K/4K)
			b	2K aggregation size (if TX buffer size is 2K)

		MCS 2, 1, 0:
			a	No aggregation

	3.	BW40 HT Rate:
		When TX rate goes down,
		MCS 7, 6, 5, 4, 3, 2, 1:
			a	8K aggregation size (if TX buffer size is 8K)
			b	4K aggregation size (if TX buffer size is 4K)
			c	2K aggregation size (if TX buffer size is 2K)

		MCS 0:
			a	No aggregation

		When TX rate goes up,
		MCS 7, 6, 5, 4, 3:
			a	8K aggregation size (if TX buffer size is 8K)
			b	4K aggregation size (if TX buffer size is 4K)
			c	2K aggregation size (if TX buffer size is 2K)

		MCS 2, 1, 0:
			a	No aggregation

	where <n> is 0/1 (for disable/enable)

	eg:
	iwpriv mlanx amsduaggrctrl 1 - Enable this feature
	iwpriv mlanx amsduaggrctrl 0 - Disable this feature
	iwpriv mlanx amsduaggrctrl - This will get the enable/disable flag
	and the current AMSDU buffer size). The AMSDU buffer size returned is only
	valid after association as before association there is no rate info.

	Note:- This command to enable/disable could be given anytime (before/after
			association). This feature is enabled by default by the driver during
			initialization.

httxbfcap
	This command is used to set/get the TX beamforming capabilities.

	Usage:
		iwpriv mlanX httxbfcap [cap]

	where the parameters are,
		cap: TX beamforming capabilities
			 Bit 0    : Implicit TX BF receiving capable
			 Bit 1    : RX staggered sounding capable
			 Bit 2    : TX staggered sounding capable
			 Bit 3    : RX NDP capable
			 Bit 4    : TX NDP capable
			 Bit 5    : Implicit TX BF capable
			 Bit 6-7  : Calibration
			         0: - not supported
			         1: - STA can respond to a calibration request using
			              the CSI Report, but cannot initiate calibration
			         2: - reserved
			         3: - STA can both initiate and respond to a calibration request
			 Bit 8    : Explicit CSI TX BF capable
			 Bit 9    : Explicit non-compressed steering capable
			 Bit 10   : Explicit compressed steering capable
			 Bit 11-12: Explicit TX BF CSI feedback
			         0: - not supported
			         1: - delayed feedback
			         2: - immediate feedback
			         3: - delayed and immediate feedback
			 Bit 13-14: Explicit non-compressed BF feedback capable
			         0: - not supported
			         1: - delayed feedback
			         2: - immediate feedback
			         3: - delayed and immediate feedback
			 Bit 15-16: Explicit compressed BF feedback capable
			         0: - not supported
			         1: - delayed feedback
			         2: - immediate feedback
			         3: - delayed and immediate feedback
			 Bit 17-18: Minimal grouping
			         0: - no grouping (STA supports groups of 1)
			         1: - groups of 1, 2
			         2: - groups of 1, 4
			         3: - groups of 1, 2, 4
			 Bit 19-20: CSI number of beamformer antennas supported
			         0: - single TX antenna sounding
			         1: - 2 TX antenna sounding
			         2: - 3 TX antenna sounding
			         3: - 4 TX antenna sounding
			 Bit 21-22: Non-compressed steering number of beamformer antennas supported
			         0: - single TX antenna sounding
			         1: - 2 TX antenna sounding
			         2: - 3 TX antenna sounding
			         3: - 4 TX antenna sounding
			 Bit 23-24: Compressed steering number of beamformer antennas supported
			         0: - single TX antenna sounding
			         1: - 2 TX antenna sounding
			         2: - 3 TX antenna sounding
			         3: - 4 TX antenna sounding
			 Bit 25-26: CSI max number of rows beamformer supported
			         0: - single row of CSI
			         1: - 2 rows of CSI
			         2: - 3 rows of CSI
			         3: - 4 rows of CSI
			 Bit 27-28: Channel estimation capability
			         0: - 1 space time stream
			         1: - 2 space time streams
			         2: - 3 space time streams
			         3: - 4 space time streams
			 Bit 29-31: Reserved

	Examples:
		iwpriv mlan0 httxbfcap             : Get the current TX BF capabilities
		iwpriv mlan0 httxbfcap 0x0000001F  : Set the TX BF capabilities of the
		                                     Implicit TX BF receiving capable,
		                                     RX staggered sounding capable,
		                                     TX staggered sounding capable,
		                                     RX NDP capable and TX NDP capable

httxbfcfg
	This command is used to configure the TX beamforming options.
	Note: Any new subcommand should be inserted in the second
		argument and each argument of the sub command should be
		separated by semicolon. For global configuration, the
		arguments should be separated by space.

	Usage:
		iwpriv mlanX httxbfcfg "<action>[;GlobalData/tsData/interval/txPeerData/snrData]"

	where the parameters are,
		action: TX beamforming action
			0: Control global parameters for beamforming
		        1: Performs NDP Sounding for PEER
		        2: TX BF interval in milliseconds
		        3: Enable/Disable beamforming/sounding for a particular peer
		        4: TX BF SNR Threshold for peer
		        .. <for new subcommand>
		GlobalData: Global parameter arguments.
		    It contains beamforming enable, sounding enable, FB type, snr_threshold
		    sounding interval, Beamformig mode values seperated by space.
		    Syntax:
			iwpriv mlanX httxbfcfg <action>;<beamforming enable> <sounding enable> <FB type>
			                       <snr_threshold>  <sounding interval> <Beamforming mode>
		tsData: Trigger sounding for PEER specific arguments,
		        it contains PEER MAC and status
		interval: TX BF interval in milliseconds
		txPeerData: Enable/Disable beamforming/sounding for the indicated peer,
		          it contains PEER MAC, sounding, beamfoming options and FB type;
		snrData: TX BF SNR Threshold for peer, it contains PEER MAC and SNR

	Examples:
		iwpriv mlan0 httxbfcfg "0"                          : Get current global configuration parameter
		iwpriv mlan0 httxbfcfg "2;00:50:43:20:BF:64"        : Get the TX BF periodicity for a given peer
		iwpriv mlan0 httxbfcfg "3"                          : Get the list of MAC addresses that have
		                                                      beamforming and/or sounding enabled
		iwpriv mlan0 httxbfcfg "4"                          : Get the list of PEER MAC, SNR tuples
		                                                      programmed into the firmware.
		iwpriv mlan0 httxbfcfg "0;0 0 3 10 500 5"           : Disable beamforming, sounding, set FB type
		                                                      to 3, snr threshold to 10, sounding interval
		                                                      to 500 ms and beamforming mode to 5
		iwpriv mlan0 httxbfcfg "1;00:50:43:20:BF:64"        : Perform NDP Trigger sounding to peer
		                                                      00:50:43:20:BF:64
		iwpriv mlan0 httxbfcfg "2;00:50:43:20:BF:64;500"    : Set TX BF periodicity for peer 00:50:43:20:BF:64
		                                                      to 500 milliseconds
		iwpriv mlan0 httxbfcfg "3;00:50:43:20:BF:43;1;0;3"  : Enable beamforming, disable sounding and set
		                                                      FB type to 3 for peer 00:50:43:20:BF:43
		iwpriv mlan0 httxbfcfg "4;00:50:43:20:BF:24;43"     : Set TX BF SNR threshold to peer
		                                                      00:50:43:20:BF:24 with SNR 43

mgmtframectrl
	This command is used to get/set mask for the management frames which needs to be forwarded to application layer.

	Usage:
		iwpriv mlanX mgmtframectrl [m]

	where the parameter [m] is the bit mask of management frame reception.
		Following are the bit definitions.
		Bit 0 : Association Request
		Bit 1 : Association Response
		Bit 2 : Re-Association Request
		Bit 3 : Re-Association Response
		Bit 4 : Probe Request
		Bit 5 : Probe Response
		Bit 8 : Beacon Frames

	Examples:
		iwpriv mlan0 mgmtframectrl         : Get the current Mgmt Frame forwarding mask
		iwpriv mlan0 mgmtframectrl 0x0020  : Bit 5 is set, Forward probe response
											 frames to application layer

mpactrl
	This command is used to set/get the Tx, Rx SDIO aggregation parameters.
	Note: The parameters can be set only in disconnected state.

	Usage:
		iwpriv mlanX mpactrl [tx_ena] [rx_ena] [tx_size] [rx_size] [tx_ports] [rx_ports]

	where the parameter are:
		[tx_ena]: Enable/disable (1/0) Tx MP-A
		[rx_ena]: Enable/disable (1/0) Rx MP-A
		[tx_size]: Size of Tx MP-A buffer
		[rx_size]: Size of Rx MP-A buffer
		[tx_ports]: Max ports (1-16) for Tx MP-A
		[rx_ports]: Max ports (1-16) for Rx MP-A
	default values are 1 1 16384 32768 16 16
	The MP-A may be disabled by default at build time if the MMC driver byte mode patch
	is not available in kernel.

	Examples:
		iwpriv mlan0 mpactrl       : Get MP aggregation parameters
		iwpriv mlan0 mpactrl 0 0
		                           : Disable MP aggregation for Tx, Rx respectively
		iwpriv mlan0 mpactrl 1 1 8192 8192 8 8
		                           : Enable MP aggregation for Tx, Rx
		                           : Set Tx, Rx buffer size to 8192 bytes
		                           : Set maximum Tx, Rx ports to 8

deepsleep
	This command is used to set/get auto deep sleep mode.

	Usage:
		iwpriv mlanX deepsleep [n] [m]

	where the parameters are:
		[n]: Enable/disable auto deep sleep mode (1/0)
		[m]: Idle time in milliseconds after which firmware will put the device
		     in deep sleep mode. Default value is 100 ms.

	Examples:
		iwpriv mlan0 deepsleep          : Display auto deep sleep mode
		iwpriv mlan0 deepsleep 1        : Enable auto deep sleep mode, idle time unchanged
		iwpriv mlan0 deepsleep 0        : Disable auto deep sleep mode
		iwpriv mlan0 deepsleep 1 500    : Enable auto deep sleep mode with idle time 500 ms
        Note:
            Deepsleep must be disabled before changing idle time.

hscfg
	This command is used to configure the host sleep parameters.

	Usage:
		iwpriv mlanX hscfg [condition [[GPIO# [gap]]]]

	This command takes one (condition), two (condition and GPIO#) or three
	(condition, GPIO# and gap) parameters for set. If no parameter provided,
	get is performed.

	where Condition is:
		bit 0 = 1   -- broadcast data
		bit 1 = 1   -- unicast data
		bit 2 = 1   -- mac event
		bit 3 = 1   -- multicast data
		bit 6 = 1  --  Wakeup when mgmt frame received.
		bit 7 = 1  --  Reserved
		bit 8 = 1  --  Disable non maskable data wakeup.

	The host sleep mode will be canceled if condition is set to -1. The default is 0x7.

	where GPIO is the pin number of GPIO used to wakeup the host. It could be any valid
	GPIO pin# (e.g. 0-7) or 0xff (interface, e.g. SDIO will be used instead).
	The default is 0xff.

	where Gap is the gap in milliseconds between wakeup signal and wakeup event or 0xff
	for special setting (host acknowledge required) when GPIO is used to wakeup host.
	The default is 200.

	The host sleep set except for cancellation will be blocked if host sleep is
	already activated.

	Examples:
		iwpriv mlan0 hscfg              : Get current host sleep mode
		iwpriv mlan0 hscfg -1           : Cancel host sleep mode
		iwpriv mlan0 hscfg 3            : Broadcast and unicast data
		                                  Use GPIO and gap set previously
		iwpriv mlan0 hscfg 2 3          : Unicast data
		                                  Use GPIO 3 and gap set previously
		iwpriv mlan0 hscfg 2 1 0xa0     : Unicast data
		                                  Use GPIO 1 and gap 160 ms
		iwpriv mlan0 hscfg 2 0xff       : Unicast data
		                                  Use interface (e.g. SDIO)
		                                  Use gap set previously
		iwpriv mlan0 hscfg 4 3 0xff     : MAC event
		                                  Use GPIO 3
		                                  Special host sleep mode
		iwpriv mlan0 hscfg 1 0xff 0xff  : Broadcast data
		                                  Use interface (e.g. SDIO)
		                                  Use gap 255ms

hssetpara
	This command is used to set host sleep parameters.

	Usage:
		iwpriv mlanX hssetpara Condition [GPIO# [gap]]

	Note:
	1) The usages of parameters are the same as "hscfg" command.
	2) The parameters will be saved in the driver and be used when host suspends.

deauth
	This command is used to send a de-authentication to an arbitrary AP.
	If [n] is omitted, the driver will deauth the associated AP.
	If in ad-hoc mode this command is used to stop beacon transmission
	from the station and go into idle state.

	When <n> is supplied as a MAC address, the driver will deauth the
	  specified AP.  If the AP address matches the driver's associated AP,
	  the driver will disconnect. Otherwise, the driver remains connected.

radioctrl
	This command is used to turn on/off the radio.
	Note: The radio can be disabled only in disconnected state.

	where value of n is:
		0   -- Disable
		1   -- Enable

	Examples:
		iwpriv mlan0 radioctrl 1        : Turn the radio on
		iwpriv mlan0 radioctrl          : Get radio status

reassoctrl
	This command is used to turn on/off re-association in driver.

	Usage:
		iwpriv mlanX reassoctrl [n]

	Where value of n is:
		0   -- Disable
		1   -- Enable

	Examples:
		iwpriv mlan0 reassoctrl         : Get re-association status
		iwpriv mlan0 reassoctrl 1       : Turn re-association on

bandcfg
	This command is used to set/get infra/ad-hoc band.
	Note: This command is only available in disconnected state.

	Usage:
		iwpriv mlanX bandcfg [l] [m] [n]

	where the parameters:
		[l]: Infrastructure band
		     bit 0: B
		     bit 1: G
		     bit 2: A
		     bit 3: GN
		     bit 4: AN

			 bit 5: AC 2.4G
			 bit 6: AC 5G
		[m]: Ad-hoc start band
		     bit 0: B
		     bit 1: G
		     bit 2: A
		[n]: Ad-hoc start channel
	Examples:
		iwpriv mlan0 bandcfg            : Get infra/ad-hoc band and ad-hoc
		                                  start channel configurations
		iwpriv mlan0 bandcfg 1          : Set infra band to B only
		iwpriv mlan0 bandcfg 3 2 6      : Set infra band to B/G, ad-hoc start band
		                                  to G and ad-hoc start channel to 6

getlog
	This command is used to get the statistics available in the station.

11dcfg
	This command is used to control 11D. No argument is used to get.

	where value of n is:
		0   -- Disable
		1   -- Enable

	Examples:
		iwpriv mlan0 11dcfg 1           : Enable 11D
		iwpriv mlan0 11dcfg             : Get 11D status

11dclrtbl
	This command is used to clear the 11D channel table.

	Usage:
		iwpriv mlanX 11dclrtbl

wmmcfg
	This command is used to control WMM. No argument is used to get.

	where value of n is:
		0   -- Disable
		1   -- Enable

	Examples:
		iwpriv mlan0 wmmcfg 1           : Enable WMM
		iwpriv mlan0 wmmcfg             : Get WMM status

txpowercfg
	This command is used to get/set the Tx power configuration.

	Where
		<RateIndex> - Data rate index
			0	1 Mbps
			1	2 Mbps
			2	5.5 Mbps
			3	11 Mbps
			4	6 Mbps
			5	9 Mbps
			6	12 Mbps
			7	18 Mbps
			8	24 Mbps
			9	36 Mbps
			10	48 Mbps
			11	54 Mbps
			12	MCS0 (BW20)
			13	MCS1 (BW20)
			14	MCS2 (BW20)
			15	MCS3 (BW20)
			16	MCS4 (BW20)
			17	MCS5 (BW20)
			18	MCS6 (BW20)
			19	MCS7 (BW20)
			140	MCS0 (BW40)
			141	MCS1 (BW40)
			142	MCS2 (BW40)
			143	MCS3 (BW40)
			144	MCS4 (BW40)
			145	MCS5 (BW40)
			146	MCS6 (BW40)
			147	MCS7 (BW40)
			0xff	Default
		<MinPwr> - Minimum power level in dBm
		<MaxPwr> - Maximum power level in dBm
		<step>   - Power step

	Note: Firmware may adjust the setting if over limit, final value can be
	      verified using get command.

	Examples:
		iwpriv mlan0 txpowercfg 0xff        : Default power configuration
		iwpriv mlan0 txpowercfg 11 12       : Set power level 12 dBm to data rate 54 Mbps
		iwpriv mlan0 txpowercfg 7 11 16 1   : Set power level 11 dBm to 16 dBm with
		                                      step 1 to data rate 18 Mbps
		iwpriv mlan0 txpowercfg             : Get current configuration
		mlan0     txpowercfg:2  3  13  18  2  1  1  13  18  2  0  0  13  18  2
		10  11  13  15  2  8  9  13  16  2  6  7  13  17  2  4  5  13  17  2
		17  19  13  15  2  15  16  13  16  2  13  14  13  17  2  12  12  13  17  2
		145  147  13  14  1  143  144  13  14  1  141  142  13  14  1  140  140  13  14  1

		 2 -> First rate index is 5.5 Mbps.
		 3 -> Last rate index is 11 Mbps.
		13 -> Min Tx power value is 13 dBm.
		18 -> Max Tx power value is 18 dBm.
		 2 -> Power adjustment step value is 2.

		Similarly
		17 -> First rate index is MCS5 (BW20).
		19 -> Last rate index is MCS7 (BW20).
		13 -> Min Tx power value is 13 dBm.
		15 -> Max Tx power value is 15 dBm.
		 2 -> Power adjustment step value is 2.

		so on...

qoscfg
	This command sets WMM IE QOS info when an argument is given, and gets current WMM
	IE QOS info when no argument is given.

	Examples:
		iwpriv mlan0 qoscfg 0x0f        : Set WMM IE QOS info to 0x0f
		iwpriv mlan0 qoscfg             : Get WMM IE QOS info

getdatarate
	This command is used to get the data rate (index) being used in last Tx
	packet and last Rx packet.

bcninterval
	This command is used to set/get the beacon interval in ad-hoc mode.
	The valid beacon interval is between 20 - 1000, default beacon
	interval is 100.

	Where <n>
		Beacon interval in TU (Time Unit: 1024 us).

	Examples:
		iwpriv mlan0 bcninterval 200    : Set ad-hoc beacon interval to 200
		iwpriv mlan0 bcninterval        : Get ad-hoc beacon interval

sysclock
	This command is used to set/get system clocks in MHz.
	The current system clock, configurable system clocks and all of the
	supported system clocks will be returned if no parameter provided.

	Examples:
		iwpriv mlan0 sysclock           : Get system clocks
		80 80 128 128 128 5 11 16 20 22 32 40 44 64 80 106 128 160 ...
		(The current system clock is 80 MHz.
		 The configurable system clocks of non-security, security, non-security
		 A-MPDU and security A-MPDU are 80 MHz, 128 MHz, 128 MHz and 128 MHz.
		 The supported system clocks are 5 MHz, 11 MHz, ..., 160 MHz, 182 MHz,
		 213 MHz, 256 MHz, 320 Mhz, 366 MHz , ... . the Max system clocks is different
		 for different chips, you could use this command to get the supported system clock)

		iwpriv mlanX sysclock 80        : Set system clock in non-security mode
		                                  to 80 MHz, no change for others
		iwpriv mlanX sysclock 0 0 128   : Set system clock in non-security A-MPDU
		                                  mode to 128 MHz, no changes for others

drvdbg
	This command is used to set/get the bit masks of driver debug message control.

	Usage:
		iwpriv mlanX drvdbg [n]

	Where the parameter <n> is the generic debug message control bit mask.
	The following types of driver debug messages can be dynamically enabled or
	disabled by setting or clearing the corresponding bits,
		bit 0:  MMSG  		PRINTM(MMSG,...)
		bit 1:  MFATAL		PRINTM(MFATAL,...)
		bit 2:  MERROR		PRINTM(MERROR,...)
		bit 3:  MDATA 		PRINTM(MDATA,...)
		bit 4:  MCMND 		PRINTM(MCMND,...)
		bit 5:  MEVENT		PRINTM(MEVENT,...)
		bit 6:  MINTR 		PRINTM(MINTR,...)
		bit 7:  MIOCTL 		PRINTM(MIOCTL,...)
		...
		bit 16: MDAT_D		PRINTM(MDAT_D,...), DBG_HEXDUMP(MDAT_D,...)
		bit 17: MCMD_D		PRINTM(MCMD_D,...), DBG_HEXDUMP(MCMD_D,...)
		bit 18: MEVT_D		PRINTM(MEVT_D,...), DBG_HEXDUMP(MEVT_D,...)
		bit 19: MFW_D		PRINTM(MFW_D,...),  DBG_HEXDUMP(MFW_D,...)
		bit 20: MIF_D 		PRINTM(MIF_D,...),  DBG_HEXDUMP(MIF_D,...)
		...
		bit 28: MENTRY		PRINTM(MENTRY,...), ENTER(), LEAVE()
		bit 29: MWARN 		PRINTM(MWARN,...)
		bit 30: MINFO 		PRINTM(MINFO,...)

	If CONFIG_DEBUG=2, all kinds of debug messages can be configured.

	If CONFIG_DEBUG=1, all kinds of debug messages can be configured except
	for MENTRY, MWARN and MINFO. By default MMSG, MFATAL and MERROR are enabled.

	Some special debug messages,
		'*'		// MLAN driver ISR is called (bit 6 MINTR enabled)
		'|'		// PS awake event is received (bit 5 MEVENT enabled)
		'_'		// PS sleep event is received (bit 5 MEVENT enabled)
		'+'		// PS sleep confirm is sent (bit 5 MEVENT enabled)

	Examples:
		iwpriv mlan0 drvdbg             : Get the current driver debug masks
		iwpriv mlan0 drvdbg 0           : Disable all the debug messages
		iwpriv mlan0 drvdbg 7           : Enable MMSG, MFATAL and MERROR messages
		iwpriv mlan0 drvdbg 0x20037     : Enable MMSG, MFATAL, MEEROR,
		                                  MCMND, MEVENT and MCMD_D messages
		iwpriv mlan0 drvdbg -1          : Enable all the debug messages

warmreset
	This command is used for warm reset of the interface.

	Usage:
		iwpriv mlanX warmreset

regrdwr
	This command is used to read/write the adapter register.

	Usage:
		iwpriv mlanX regrdwr <type> <offset> [value]

	where the parameters are,
		<type>:     1:MAC/SOC, 2:BBP, 3:RF, 5:CAU
		<offset>:   offset of register
		[value]:    value to be written
	Note: If highest bit of a 32-bit value needs to be set, use negative input.
	The calculation is -(0xffffffff - value + 1). Range from -0x80000000 to -1.

	Examples:
		iwpriv mlan0 regrdwr 1 0xa060       : Read the MAC register
		iwpriv mlan0 regrdwr 1 0xa060 0x12  : Write the MAC register
		iwpriv mlan0 regrdwr 1 0xa794 -0x80000000
		                                    : Write 0x80000000 to MAC register
		iwpriv mlan0 regrdwr 1 0xa794 -0x00000001
		                                    : Write 0xffffffff to MAC register

rdeeprom
	This command is used to read the EEPROM contents of the card.

	Usage:
		iwpriv mlanX rdeeprom <offset> <length>

	where the parameters are,
		<offset>:   multiples of 4
		<length>:   4-20, multiples of 4

	Example:
		iwpriv mlan0 rdeeprom 0 20      : Read 20 bytes of EEPROM data from offset 0

memrdwr
	This command is used to read/write the adapter memory.

	Usage:
		iwpriv mlanX memrdwr <address> [value]

	where the parameters are,
		<address>:  memory address
		[value]:    value to be written
	Note: If highest bit of a 32-bit address/value needs to be set, use negitive input.
	The calculation is -(0xffffffff - address/value + 1). Range from -0x80000000 to -1.

	Examples:
		iwpriv mlan0 memrdwr 0x4cf70    : Read memory address 0x4cf70
		iwpriv mlan0 memrdwr -0x80000000
		                                : Read memory address 0x80000000
		iwpriv mlan0 memrdwr -0x7fff6000 -0x40000000
		                                : Write 0xc0000000 to memory address 0x8000a000

inactivityto
	This command is used to set/get the inactivity timeout value, which specifies
	when WLAN device is put to sleep.

	Usage:
		iwpriv mlanX inactivityto <n> <m> <l> [k]

	where the parameter are:
		<n>: timeout unit in microseconds.
		<m>: Inactivity timeout for unicast data.
		<l>: Inactivity timeout for multicast data.
		[k]: Inactivity timeout for new Rx traffic after PS notification to AP.

	Examples:
		iwpriv mlan0 inactivityto           : Get the timeout value
		iwpriv mlan0 inactivityto 1000 2 3  : Set timeout unit to 1000 us (1 ms),
		                                      inactivity timeout for unicast data is 2 ms,
		                                      inactivity timeout for multicast data is 3 ms

sdioclock
	Turn On(1) or Off(0) the SDIO clock.

	Usage:
		iwpriv mlanX sdioclock 1 (on)
		iwpriv mlanX sdioclock 0 (off)
		iwpriv mlanX sdioclock (get the current clock state)

sdcmd52rw
	This command is used to read/write a controller register in
	Secure Digital I/O Interfaces.

	Usage:
		iwpriv mlanX sdcmd52rw <function number> <register address> [value]

	For SDIO MMC driver, only function 0 and 1 access is allowed. And there
	is a limitation for function 0 write, only vendor specific CCCR registers
	(0xf0 -0xff) are permiited.

	Examples:
		iwpriv mlan0 sdcmd52rw 1 3
		iwpriv mlan0 sdcmd52rw 1 1 0x3f

scancfg
	This command is used to set/get scan configuration parameters.

	Usage:
		iwpriv mlanX scancfg [t] [m] [p] [s] [a] [b] [ext]

	where the parameters:
		[t]: Scan Type (0: Unchanged, 1: Active, 2: Passive, default Active)
		[m]: Scan Mode (0: Unchanged, 1: BSS, 2: IBSS, 3: Any, default Any)
		[p]: Scan Probes (0: Unchanged, 1-4: Number of probes per channel, default 4)
		[s]: Specific Scan Time (0: Unchanged, n: Value in ms, default 110 ms, max 500 ms)
		[a]: Active Scan Time (0: Unchanged, n: Value in ms, default 200 ms, max 500 ms)
		[b]: Passive Scan Time (0: Unchanged, n: Value in ms, default 200 ms, max 2000 ms)
		[ext]: Extended scan (0: Legacy scan, 1: Extended scan)

	No change if the parameter is 0 or the parameter is not provided.

	Examples:
		iwpriv mlan0 scancfg            : Get all the current scan configuration settings
		iwpriv mlan0 scancfg 1 3        : Set scan type to active and scan mode to any,
		                                  all the other scan configurations are unchanged
		iwpriv mlan0 scancfg 0 1 2 200  : Set scan mode to BSS, number of probes to 2 and
		                                  specific scan time to 200 ms, all the other scan
		                                  configurations are unchanged

sleeppd
	This command is used to configure the sleep period of the WLAN device.

	Usage:
		iwpriv mlanX sleeppd [<period>]

	Where the parameter is:
		period: sleep period in milliseconds. Range 10~60. 0 for disable.

	Examples:
		iwpriv mlan0 sleeppd            : Get sleep period configuration
		iwpriv mlan0 sleeppd 10         : Set sleep period to 10 ms

pscfg
	This command is used to set/get PS configuration parameters.

	Usage:
		iwpriv mlanX pscfg [k] [d] [l] ...

	Where the parameters:
		[k]: Keep alive null packet interval (0: Unchanged, -1: Disable, n: Interval in seconds)
		[d]: DTIM interval (    0: Unchanged,
		                      1-5: Value,
		                    65534: DTIM will be ignored, listen interval will be used,
		                    65533: Closest DTIM to the listen interval period will be used )
		[l]: Local listen interval (     0: Unchanged,
		                                -1: Disable,
		                              1-49: Value in beacon intervals,
		                             >= 50: Value in TUs )
		[b]: Beacon miss timeout (0: Unchanged, 1-50: Value in milliseconds, 65535: Disable)
		[p]: Delay to PS (0-65535: Value in milliseconds, default 1000ms)
		[m]: PS mode (0: Unchanged, 1: Auto mode, 2: PS-Poll mode, 3: PS Null mode)
	No change if parameters are not provided.

	Examples:
		iwpriv mlan0 pscfg              : Get all the current PS configuration settings
		iwpriv mlan0 pscfg 3 4          : Set PS keep alive null packet interval to 3 seconds
		                                  and DTIM interval to 4, all the other configurations
		                                  are unchanged
		iwpriv mlan0 pscfg 0 0 0 0 50 2 : Set delay to PS to 50 ms and PS mode to PS-Poll mode,
		                                  keep the others unchanged

fwwakeupmethod
	This command is used to set/get the firmware wakeup method.

	where value is:
	        [n]:
		1	-- Firmware wakeup through the interface command interrupt
			    -- (default setting for SDIO/PCIe/USB)
		2	-- Firmware wakeup through the GPIO pin
		[g]:If firware wakeup throug GPIO pin, [g] is GPIO pin number

	Examples:
		iwpriv mlan0 fwwakeupmethod     : Get current firmware wakeup method
		iwpriv mlan0 fwwakeupmethod 1    : Set firmware wakeup method to Interface mode
		iwpriv mlan0 fwwakeupmethod 2 5  : Set firmware wakeup method to GPIO mode, GPIO_pin=5

getkey
	This command is used to get PTK/GTK

	iwpriv mlanX getkey
associate
	Request an association to a given SSID/BSSID pair. This the only accurate
	way to pick a specific AP and ESS for an association. The entry must
	already exist in the scan table for the association to be attempted.

	iwpriv mlanX associate "xx:xx:xx:xx:xx:xx SSID"

sleepparams
	This command is used to set the sleepclock configurations

	Usage:
		iwpriv mlanX sleepparams [<p1> <p2> <p3> <p4> <p5> <p6>]

	where:
		p1 is Sleep clock error in ppm (0-65535)
		p2 is Wakeup offset in usec (0-65535)
		p3 is Clock stabilization time in usec (0-65535)
		p4 is Control periodic calibration (0-2)
		p5 is Control the use of external sleep clock (0-2)
		p6 is reserved for debug (0-65535)

	Examples:
		iwpriv mlan0 sleepparams                      : Get current sleepclock configuration
		iwpriv mlan0 sleepparams 10 1000 2000 1 0 128 : Set sleepclock configuration

authtype
	This command is used to set/get authentication type.

	Usage:
		iwpriv mlanX authtype [n]

	where <n>
		0: 802.11 open system authentication
		1: 802.11 shared key authentication
		255: allow open system or shared key authentication (default)

	Examples:
		iwpriv mlan0 authtype 0         : use open system authentication
		iwpriv mlan0 authtype 1         : use shared key authentication
		iwpriv mlan0 authtype 255       : allow open system or shared key authentication
		iwpriv mlan0 authtype           : get current setting

powercons
	This command is used to set the local transmit power constraint.
	Value is in dbm unit. This command is only used for ad-hoc start.

	Usage:
		iwpriv mlanX powercons [n]

	Examples:
		iwpriv mlanX powercons          : get the current setting
		iwpriv mlanX powercons 12       : set local power constraint to 12 dbm

ipaddr
	This command is used to set/get IP address.

	Usage:
		iwpriv mlanX ipaddr ["<op>;<ipaddr>"]

	where <op>
		0: Remove the IP address
		bit 0: Set IP address for broadcast ARP filter, which will be auto enabled
		       in next host sleep configuration
		bit 1: Set IP address for auto broadcast ARP response

	Examples:
		iwpriv mlan0 ipaddr                 : Get current settings
		iwpriv mlan0 ipaddr "0"             : Remove IP address
		iwpriv mlan0 ipaddr "1;192.168.0.5" : Set IP address for ARP filter
		iwpriv mlan0 ipaddr "3;192.168.0.6" : Set IP address for ARP filter
		                                    : and auto ARP response

macctrl
	This command is used to set/get MAC control.
	It's recommended to read the current setting first to avoid override issue.

	Usage:
		iwpriv mlanX macctrl [n]

	where <n>
		bit 0:  Rx enabled
		bit 1:  Tx enabled
		bit 3:  WEP enabled
		bit 4:  EthernetII enabled
		bit 7:  Promiscuous enabled
		bit 8:  All multicast enabled
		bit 9:  RTS/CTS enabled (0: CTS to self)
		bit 11: Force 11n protection disabled
		bit 12: Ad-hoc g protection disabled
		...

	Examples:
		iwpriv mlan0 macctrl            : Get current MAC control
		iwpriv mlan0 macctrl 0x13       : Set Tx/Rx on and EthernetII on
		iwpriv mlan0 macctrl 0x813      : Set Tx/Rx on and EthernetII on
		                                : Disable force 11n protection

dfstesting
	This command is used to set/get settings for DFS testing.

	Usage:
	    iwpriv mlanX dfstesting [<user_cac_pd> <user_nop_pd> <no_chan_change> <fixed_chan_num>]

	where <user_cac_pd> is user-configured Channel Availability Check in msec
                        0 = disable, use default period (60000)
                        1-65535 = enable with that period
	where <user_nop_pd> is user-configured Non-Occupancy Period in sec
                        0 = disable, use default period (1800)
                        1-65535 = enable with that period
	where <no_chan_change> is enable/disable no channel change on radar
                           0 = disable, 1 = enable (overrides below)
	where <fixed_chan_num> is user-configured channel to change to on radar
                           0 = disable, 1-255 = enable with that channel
                           (channel validity for region, etc. is not checked)
                           (only takes effect if no_chan_change = 0)

	Examples:
		iwpriv mlan0 dfstesting             : Get current dfstesting settings
		iwpriv mlan0 dfstesting 2000 0 0 0  : user_cac=2sec, others disabled/default
		iwpriv mlan0 dfstesting 0 0 1 0     : only no_chan_change enabled
		iwpriv mlan0 dfstesting 0 120 0 64  : user_nop=2min, force chan 64 on radar

===============================================================================
		U S E R  M A N U A L  F O R  M L A N C O N F I G

NAME
mlanconfig - configure the additional parameters available for the NXP mdriver.

SYNOPSIS
mlanconfig -v
mlanconfig <mlanX> <command> [parameters] ...

mlanconfig mlanX hostcmd <bg_scan.conf> bgscfg
mlanconfig mlanX hostcmd <requesttpc.conf> requesttpc
mlanconfig mlanX hostcmd <crypto_test.conf> crypto_test
mlanconfig mlanX hostcmd <subevent.conf> subevent_get
mlanconfig mlanX hostcmd <subevent.conf> subevent_set
mlanconfig mlanX hostcmd <auto_tx.conf> auto_tx_get
mlanconfig mlanX hostcmd <auto_tx.conf> nat_keep_alive
mlanconfig mlanX hostcmd <auto_tx.conf> auto_tx_unreg
mlanconfig mlanX hostcmd <txrate_cfg.conf> txrate_cfg_get
mlanconfig mlanX hostcmd <txrate_cfg.conf> txrate_cfg_set_bg
mlanconfig mlanX hostcmd <txrate_cfg.conf> txrate_cfg_set_bgn
mlanconfig mlanX hostcmd <txpwrlimit_cfg.conf> txpwrlimit_cfg_get
mlanconfig mlanX hostcmd <txpwrlimit_cfg.conf> txpwrlimit_2g_cfg_set
mlanconfig mlanX hostcmd <txpwrlimit_cfg.conf> txpwrlimit_5g_cfg_set
mlanconfig mlanX hostcmd <pad_cfg.conf> pad_cfg_get
mlanconfig mlanX hostcmd <pad_cfg.conf> pad_cfg_set
mlanconfig mlanX hostcmd <11n_2040coex.conf> 2040coex
mlanconfig mlanX hostcmd <robust_btc.conf> mode_get
mlanconfig mlanX hostcmd <robust_btc.conf> mode_timeshare
mlanconfig mlanX hostcmd <robust_btc.conf> mode_spatial
mlanconfig mlanX hostcmd <robust_btc.conf> generictime
mlanconfig mlanX hostcmd <robust_btc.conf> a2dptime
mlanconfig mlanX hostcmd <robust_btc.conf> inquirytim
mlanconfig mlanX hostcmd <robust_btc.conf> ap_generictime
mlanconfig mlanX hostcmd <robust_btc.conf> ap_a2dptime
mlanconfig mlanX hostcmd <robust_btc.conf> ap_inquirytime
mlanconfig mlanX hostcmd <sdio_pulldown.conf> sdio_pulldown_get
mlanconfig mlanX hostcmd <sdio_pulldown.conf> sdio_pulldown_set
mlanconfig mlanX hostcmd <sdio_pulldown.conf> sdio_pulldown_disable
mlanconfig mlanX arpfilter <arpfilter.conf>
mlanconfig mlanX mefcfg <mef.conf>
mlanconfig mlanX cfgdata <register type> <conf file>
mlanconfig mlanX sdcmd52rw <FN no.> <address> [data]
mlanconfig mlanX sdcmd53rw <FN no.> <address> <mode> <blksize> <blknum> [data1] ... [dataN]
mlanconfig mlanX setuserscan [ARGS]
mlanconfig mlanX getscantable [ARGS]
mlanconfig mlanX addts <filename.conf> <section# of tspec> <timeout in ms>
mlanconfig mlanX delts <filename.conf> <section# of tspec>
mlanconfig mlanX qconfig set msdu <lifetime in TUs> [Queue Id: 0-3]
mlanconfig mlanX qconfig get [Queue Id: 0-3]
mlanconfig mlanX qconfig def [Queue Id: 0-3]
mlanconfig mlanX qstats on  [Queue Id: 0-3]
mlanconfig mlanX qstats off [Queue Id: 0-3]
mlanconfig mlanX qstats get [Queue Id: 0-3]
mlanconfig mlanX qstatus
mlanconfig mlanX ts_status
mlanconfig mlanX regrdwr <type> <offset> [value]
mlanconfig mlanX memrdwr <address> [value]
mlanconfig mlanX customie <index> <mask> <IE buffer>
mlanconfig mlanX tdls_config <0/1>
mlanconfig mlanX tdls_setinfo <tdls.conf>
mlanconfig mlanX tdls_setup <tdls.conf>
mlanconfig mlanX tdls_discovery <tdls.conf>
mlanconfig mlanX tdls_teardown <tdls.conf>
mlanconfig mlanX tdls_powermode <tdls.conf>
mlanconfig mlanX tdls_channel_switch <tdls.conf>
mlanconfig mlanX tdls_stop_channel_switch <tdls.conf>
mlanconfig mlanX tdls_cs_params <tdls.conf>
mlanconfig mlanX tdls_disable_cs <0/1>
mlanconfig mlanX tdls_link_status
mlanconfig mlanX tdls_debug "wrong_bss" <0/1>
mlanconfig mlanX tdls_debug "setup_existing_link" <0/1>
mlanconfig mlanX tdls_debug "fail_setup_confirm" <0/1>
mlanconfig mlanX tdls_debug "setup_with_prohibited" <0/1>
mlanconfig mlanX tdls_debug "higher_lower_mac" <0/1>
mlanconfig mlanX tdls_debug "ignore_key_expiry" <0/1>
mlanconfig mlanX tdls_debug "allow_weak_security" <0/1>
mlanconfig mlanX tdls_debug "stop_rx" <0/1>
mlanconfig mlanX tdls_debug "cs_im_return" <0/1>
mlanconfig mlanX mgmtframetx <mgmt_frame.conf>

DESCRIPTION

Those commands are used in NXP specific application called mlanconfig.

===========
-v
	This command is used to display the version of mlanconfig utility.
	Usage:
		mlanconfig -v

hostcmd bgscfg
	This command is used to configure the various parameters for PPS/UAPSD
	or normal background scan.

	Usage:
		mlanconfig mlanX hostcmd config/bg_scan.conf bgscfg

hostcmd requesttpc
	This command is used to request 802.11H TPC info.

	Usage:
		mlanconfig mlanX hostcmd config/requesttpc.conf requesttpc

hostcmd crypto_test
	This command is used to test the encryption/decryption API of the firmware.

	Usage:
		mlanconfig mlanX hostcmd config/crypto_test.conf crypto_test

hostcmd subevent_get
hostcmd subevent_set
	This command is used to get/set the configurations for event descriptor
	interface command.
	subsvent_get: get subscribed event parameters
	subsvent_set: set subscribed event parameters

	Usage:
		mlanconfig mlanX hostcmd config/subevent.conf subevent_get
		mlanconfig mlanX hostcmd config/subevent.conf subevent_set

hostcmd auto_tx_get
hostcmd nat_keep_alive
hostcmd auto_tx_unreg
	This command is used to configures the Frame Auto Transmission parameters.
	auto_tx_get: get auto_tx parameters
	nat_keep_alive: register to firmware for sending NAT Keep Alive packet
	auto_tx_unreg: unregister to firmware auto_tx

	Usage:
		mlanconfig mlanX hostcmd config/auto_tx.conf auto_tx_get
		mlanconfig mlanX hostcmd config/auto_tx.conf nat_keep_alive
		mlanconfig mlanX hostcmd config/auto_tx.conf auto_tx_unreg

hostcmd txrate_cfg_get
hostcmd txrate_cfg_set_bg
hostcmd txrate_cfg_set_bgn
	This command is used to set/get the transmit data rate.

	Usage:
		mlanconfig mlanX hostcmd config/txrate_cfg.conf txrate_cfg_get
		mlanconfig mlanX hostcmd config/txrate_cfg.conf txrate_cfg_set_bg
		mlanconfig mlanX hostcmd config/txrate_cfg.conf txrate_cfg_set_bgn

hostcmd txpwrlimit_cfg_get
hostcmd txpwrlimit_2g_cfg_set
hostcmd txpwrlimit_5g_cfg_set
	This command is used to set/get the configuration data of Tx power limitation.
	Note: The configuration set should be issued when STA is disconnected.

	Usage:
		mlanconfig mlanX hostcmd config/txpwrlimit_cfg.conf txpwrlimit_cfg_get
		mlanconfig mlanX hostcmd config/txpwrlimit_cfg.conf txpwrlimit_2g_cfg_set
		mlanconfig mlanX hostcmd config/txpwrlimit_cfg.conf txpwrlimit_5g_cfg_set

hostcmd pad_cfg_get
hostcmd pad_cfg_set
	This command is used to set/get the configuration data for PAD OR.

	Usage:
		mlanconfig mlanX hostcmd config/pad_cfg.conf pad_cfg_get
		mlanconfig mlanX hostcmd config/pad_cfg.conf pad_cfg_set

hostcmd 2040coex
	This command is used to send the 11n 20/40 Coex command to firmware.
	Firmware will send 11n 20/40 Coex management action frame to AP.

	Usage:
		mlanconfig mlanX hostcmd config/11n_2040coex.conf 2040coex

hostcmd mode_get
hostcmd mode_timeshare
hostcmd mode_spatial
	This command is used to get/set Robust BT Coex.
	mode_get:       get the current mode
	mode_timeshare: set Robust BT Coex to timeshare mode  (default on 1x1 chips)
	mode_spatial:   set Robust BT Coex to spatial mode    (only for, and default on 2x2 chips)

	Usage:
		mlanconfig mlanX hostcmd config/robust_btc.conf mode_get
		mlanconfig mlanX hostcmd config/robust_btc.conf mode_timeshare
		mlanconfig mlanX hostcmd config/robust_btc.conf mode_spatial

hostcmd generictime
hostcmd a2dptime
hostcmd inquirytime
hostcmd ap_generictime
hostcmd ap_a2dptime
hostcmd ap_inquirytime
        This command is used to configure the time slice of COEX (only works in timeshare mode)
        generictime:       configure the Bttime and Wlantime in Station Generic case
        a2dptime:          configure the Bttime and Wlantime in Station A2DP case
        inquirytime:       configure the Bttime and Wlantime in Station Inquiry case
        ap_generictime:    configure the Bttime and Wlantime in Ap Generic case
        ap_a2dptime:       configure the Bttime and Wlantime in Ap A2DP case
        ap_inquirytime:    configure the Bttime and Wlantime in Ap Inquiry case

    Usage:
                mlanutl mlanX hostcmd config/robust_btc.conf generictime
                mlanutl mlanX hostcmd config/robust_btc.conf a2dptime
                mlanutl mlanX hostcmd config/robust_btc.conf inquirytim
                mlanutl mlanX hostcmd config/robust_btc.conf ap_generictime
                mlanutl mlanX hostcmd config/robust_btc.conf ap_a2dptime
                mlanutl mlanX hostcmd config/robust_btc.conf ap_inquirytime

hostcmd sdio_pulldown_get
hostcmd sdio_pulldown_set
hostcmd sdio_pulldown_disable
	This command is used to set/get the settings of pulling up and
	pulling down of SDIO lines.

	Usage:
		mlanconfig mlanX hostcmd config/sdio_pulldown.conf sdio_pulldown_get
		mlanconfig mlanX hostcmd config/sdio_pulldown.conf sdio_pulldown_set
		mlanconfig mlanX hostcmd config/sdio_pulldown.conf sdio_pulldown_disable

arpfilter
	This command is used to configure the ARP filtering parameters.

	Usage:
		mlanconfig mlanX arpfilter config/arpfilter.conf

mefcfg
	This command is used to set MEF settings.

	Usage:
		mlanconfig mlanX mefcfg config/mef.conf

cfgdata
	This command is used to set/get the configuration data to/from firmware.

	Usage:
		mlanconfig mlanX cfgdata <type> <.conf file name>
		This command is used to set the cfg data in the .conf file to firmware.

		mlanconfig mlanX cfgdata <type>
		This command is used to get the cfg data from firmware and display
		on to the console.

	Where the value of <type> field is:
		2   -- Cal data download and <.conf file name> is cal_data.conf

sdcmd52rw
	This command is used to read/write a controller register in
	Secure Digital I/O Interfaces.

	Usage:
		mlanconfig mlanX sdcmd52rw <function number> <register address> [value]

	For SDIO MMC driver, only function 0 and 1 access is allowed. And there
	is a limitation for function 0 write, only vendor specific CCCR registers
	(0xf0 -0xff) are permiited.

    Examples:
		mlanconfig mlan0 sdcmd52rw 1 3
		mlanconfig mlan0 sdcmd52rw 1 1 0x3f

sdcmd53rw
	This command is used to issue a CMD53 read/write data in
	Secure Digital I/O Interfaces.

	Usage:
		mlanconfig mlanX sdcmd53rw <func> <address> <mode> <blksize> <blknum> [data1] ... [dataN]

	where the parameters are,
		<func>:     function number (0/1/2/..)
		<address>:  data address
		<mode>:     byte mode/block mode (0/1)
		<blksize>:  block size (32/64/../512, NA for byte mode)
		<blknum>:   block number or byte number
		<data1> ... <dataN>:  data for write

	Note: The total data length is block size * block number for block mode
	or byte number for byte mode. The max data length is 2000-byte.
	For write the data pattern will be duplicated to data buffer.

	Examples:
		mlanconfig mlan0 sdcmd53rw 0 0x8000 1 0x40 2
		mlanconfig mlan0 sdcmd53rw 1 0x10000 0 1 5 0x0a 0x0b 0x0c 0x0d 0x0e

setuserscan
	Initiate a customized scan and retrieve the results

	Usage:
		mlanconfig mlanX setuserscan [ARGS]

	Where [ARGS]:
	  ssid="[SSID]"            specify a SSID filter for the scan
	  chan=[chan#][band][mode] where band is [a,b,g,n] and mode is
	                           blank for active or 'p' for passive
	  bssid=xx:xx:xx:xx:xx:xx  specify a BSSID filter for the scan
	  wc="[WILDCARD SSID]"     specify a UNIX pattern matching filter (using *
	                           and ?) for SSIDs found in a broadcast probe
	  keep=[0 or 1]            keep the previous scan results (1), discard (0)
	  dur=[scan time]          time to scan for each channel in milliseconds
	  gap=[time gap]           Time gap between two scans in milliseconds
	  probes=[#]               number of probe requests to send on each chan
	                           for each broadcast probe required and each SSID
	                           specific probe required (1-4)
	  type=[1,2,3]             BSS type: 1 (Infra), 2(Adhoc), 3(Any)

	Any combination of the above arguments can be supplied on the command line.
	If the chan token is absent, a full channel scan will be completed by driver.
	If the dur or probes tokens are absent, the driver default setting will be
	used. The bssid and ssid fields, if blank, will produce an unfiltered scan.
	It's allowed to input multiple ssid/wc entries, the max entry number is 10.
	The type field will default to 3 (Any) and the keep field will default to 0
	(Discard).

	Examples:
	1) Perform an active scan on channels 1, 6, and 11 in the 'g' band:
		setuserscan chan=1g,6g,11g

	2) Perform a passive scan on channel 11 for 20 ms:
		setuserscan chan=11gp dur=20

	3) Perform an active scan on channels 1, 6, and 11; and a passive scan on
	   channel 36 in the 'a' band:
		setuserscan chan=1g,6g,11g,36ap

	4) Perform an active scan on channel 6 and 36 for specific SSID:
		setuserscan chan=6g,36a ssid=TestAP1 ssid=TestAP2

	5) Scan all available channels (B/G/N, A bands) for a specific BSSID, keep
	   the current scan table intact, update existing or append new scan data:
		setuserscan bssid=00:50:43:20:12:82 keep=1

	6) Scan channel 6, for all infrastructure networks, sending two probe
	   requests.  Keep the previous scan table intact. Update any duplicate
	   BSSID/SSID matches with the new scan data:
		setuserscan chan=6g type=1 probes=2 keep=1

	7) Scan channel 1 and 6, for all networks matching the NXP*AP
	   or AP*NXP? patterns and for NXPTst SSID.  Generate 3 broadcast
	   probes for the patterns and 3 SSID specific probes for NXPTst on
	   both channel 1 and channel 6.
		setuserscan chan=1g,6g probes=3 wc="NXP*AP" wc="AP*NXP?" ssid="NXPTst"

	8) Scan all the channels for specified band.
		setuserscan chan=0g

	9) Scan channel 1 and 6, send 3 probe requests, scan each channel for 40 ms
	   with time gap of 50ms between 2 scans
		setuserscan chan=1g,6g probes=3 dur=40 gap=50

	All entries in the scan table (not just the new scan data when keep=1)
	will be displayed upon completion by use of the getscantable ioctl.

getscantable
	Display the current contents of the driver scan table

	Usage:
		mlanconfig mlanX getscantable
		mlanconfig mlanX getscantable [#]
		mlanconfig mlanX getscantable tsf
		mlanconfig mlanX getscantable help

	1) Without argument, the entire scantable is displayed.
	2) Specifying a # will display detailed information about a specific scan
	   table entry.  '0' displays driver cached information regarding the
	   current association (if any).
	3) The tsf argument will display the entire scan table with the recorded
	   TSF timestamp for the entry.
	4) The help argument will display the legend for the capability field.

addts
	Send an ADDTS command to the associated AP.

	Process a given conf file for a specific TSPEC data block.  Send the
	  TSPEC along with any other IEs to the driver/firmware for transmission
	  in an ADDTS request to the associated AP.

	Return the execution status of the command as well as the ADDTS response
	  from the AP if any.

	Usage:
		mlanconfig mlanX addts <filename.conf> <section# of tspec> <timeout(ms)>

delts
	Send a DELTS command to the associated AP.

	Process a given conf file for a specific TSPEC data block.  Send the
	  TSPEC along with any other IEs to the driver/firmware for transmission
	  in a DELTS request to the associated AP.

	Return the execution status of the command.  There is no response to a
	  DELTS from the AP.

	Usage:
		mlanconfig mlanX delts <filename.conf> <section# of tspec>

qconfig
	Send a WMM AC Queue configuration command to get/set/default params

	Configure or get the parameters of a WMM AC queue. The command takes
	  an optional Queue Id as a last parameter.  Without the queue id, all
	  queues will be acted upon.

	Usage:
		mlanconfig mlanX qconfig set msdu <lifetime in TUs> [Queue Id: 0-3]
		mlanconfig mlanX qconfig get [Queue Id: 0-3]
		mlanconfig mlanX qconfig def [Queue Id: 0-3]

qstats
	Turn on/off or retrieve and clear the queue statistics for an AC

	Turn the queue statistics collection on/off for a given AC or retrieve the
	  current accumulated stats and clear them from the firmware. The command
	  takes an optional Queue Id as a last parameter. Without the queue id,
	  all queues will be acted upon.

	Usage:
		mlanconfig mlanX qstats on  [Queue Id: 0-3]
		mlanconfig mlanX qstats off [Queue Id: 0-3]
		mlanconfig mlanX qstats get [Queue Id: 0-3]

qstatus
	This command retrieves the current status of the WMM queues. If WMM
	  is enabled then it displays the information for each AC in a table.

	Usage:
		mlanconfig mlanX qstatus

ts_status
	This command queries the FW for the status of TSIDs 0 through 7
	  configured via call admission control and displays the results in a
	  table.

	Usage:
		mlanconfig mlanX ts_status

regrdwr
	This command is used to read/write the adapter register.

	Usage:
		mlanconfig mlanX regrdwr <type> <offset> [value]

	where the parameters are,
		<type>:     1:MAC/SOC, 2:BBP, 3:RF, 5:CAU
		<offset>:   offset of register
		[value]:    value to be written

	Examples:
		mlanconfig mlan0 regrdwr 1 0xa060   : Read the MAC register
		mlanconfig mlan0 regrdwr 1 0xa794 0x80000000
		                                    : Write 0x80000000 to MAC register

memrdwr
	This command is used to read/write the adapter memory.

	Usage:
		mlanconfig mlanX memrdwr <address> [value]

	where the parameters are,
		<address>:  memory address
		[value]:    value to be written

	Examples:
		mlanconfig mlan0 memrdwr 0x80000000  : Read memory address 0x80000000
		mlanconfig mlan0 memrdwr 0x80000000 0xffffffff
		                                     : Write 0xffffffff to memory address 0x80000000

customie
	This command is used to set or get custom IEs for management frames.

	Usage : customie [INDEX] [MASK] [IEBuffer]
        empty - Get all IE settings
        INDEX:  0 - Get/Set IE index 0 setting
                1 - Get/Set IE index 1 setting
                2 - Get/Set IE index 2 setting
               MAX IE Index depends on device memory.

               -1 - Append/Delete IE automatically
                    Delete will delete the IE from the matching IE buffer
                    Append will append the IE to the buffer with the same mask
        MASK :  Management subtype mask value as per bit definitions
             :  Bit 0 - Association request
             :  Bit 1 - Association response
             :  Bit 2 - Reassociation request
             :  Bit 3 - Reassociation response
             :  Bit 4 - Probe request
             :  Bit 5 - Probe response
             :  Bit 8 - Beacon
        MASK :  MASK = 0 to clear the mask and the IE buffer
        IEBuffer :  IE Buffer in hex (max 256 bytes)
                    The Buffer should not be space separated.

	Example:
	 ./mlanconfig mlan0 customie
		Get IE buffer, subtype mask settings for all indices.

	./mlanconfig mlan0 customie 1
		Get IE buffer and subtype mask for the Index = 1.

	./mlanconfig mlan0 customie 2 0
		Clear IE buffer and mask value for Index = 2.

	./mlanconfig mlan0 customie 3 0x101 0xdd051234567890
		Set IE buffer and mask value for Index = 3.

	./mlanconfig mlan0 customie -1 0x101 0xdd051234567890
		Append the specified IEBuffer at index with mask value of 0x101.

	./mlanconfig mlan0 customie -1 0 0xdd051234567890
		Delete the specified IEBuffer from all the IEs.

	./mlanconfig mlan0 customie 2 0 0xdd051234567890
		Delete the specified IEBuffer from the IEs at index 2.

tdls_config
	This command is used to enable/disable TDLS on device.

	Usage : tdls_config <0/1>
		1: Enable TDLS
		0: Disable TDLS
tdls_setinfo
	This command is used for setting the capabilities of the TDLS station.

        Usage : tdls_setinfo <tdls.conf>
		Set capabilities of TDLS station.
tdls_setup
	This command is used to send TDLS setup request.

	Usage: tdls_setup <tdls.conf>
                Send TDLS setup request.
tdls_discovery
	This command is used to request TDLS discovery.

	Usage : tdls_discovery <tdls.conf>
        	Request TDLS discovery.
tdls_teardown
	This command is used to send TDLS teardown request.

	Usage : tdls_teardown <tdls.conf>
		Request teardown of TDLS link.
tdls_powermode
	This command is used to send TDLS powermode request.

	Usage : tdls_powermode <tdls.conf>
		Send TDLS powermode (either 0:Active, 1:PowerSave) command.
tdls_channel_switch
	This command is used to send TDLS channel switch request.

	Usage : tdls_channel_switch <tdls.conf>
		Send TDLS channel switch command.
tdls_stop_channel_switch
	This command is used to send stop TDLS channel switch request.

	Usage : tdls_stop_channel_switch <tdls.conf>
		Send stop TDLS channel switch command.
tdls_cs_params
	This command is used to set TDLS channel switch params

	Usage : tdls_cs_params <tdls.conf>
		Set TDLS channel switch params.
tdls_disable_cs
	This command is used to disable TDLS channel switch

	Usage : tdls_disable_cs <0/1>
		Disable TDLS channel switch.
tdls_link_status [peer_mac_address]
	This command is used to get link information about TDLS links or
    a TDLS link correponding to peer mac address.

	Usage : tdls_link_status
		Send TDLS command to get current link status.
tdls_debug
	This command is used for FW debug functionality and tests.

mgmtframetx
	This command is used to send mgmt frame

	Usage:
		mlanconfig mlanX mgmtframetx <mgmt_frame.conf>

===============================================================================
		U S E R  M A N U A L  F O R  M L A N 2 0 4 0 C O E X

NAME
mlan2040coex - This application handles the 11n 20/40 coexistence operation for
               the NXP mdriver

SYNOPSIS
mlan2040coex [-d <n>] [-i <intfname>] [hvB]
	-d = Device number (n)
	-i = Interface name (intfname)
	-h = Help
	-v = Version
	-B = Run the process in background
Note: If device number (n) is not present, then 0 assumed.
      If intfname is not present, then mlan0 assumed.

===============================================================================
        U S E R  M A N U A L  F O R  MLANEVENT

NAME
mlanevent.exe

This tool can be used to listen for and obtain events from the driver
through the netlink layer.

----------------
Supported events
----------------
STA_DEAUTH
STA_ASSOC
BSS_START
BSS_IDLE
BSS_ACTIVE

-----------------
Details of events
-----------------

STA_DEAUTH
----------
    For this event, the following information is shown:
        + Deauthenticated STA MAC address.
        + Reason for deauthentication.

STA_ASSOC
----------
    For this event, the following information is shown:
        + STA MAC address.

BSS_START
----------
    For this event, the following information is shown:
        + AP MAC address.

BSS_IDLE
----------
    For this event, there is no associated information.

BSS_ACTIVE
----------
    For this event, there is no associated information.

===============================================================================

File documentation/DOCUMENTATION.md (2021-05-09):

# Documentation for balenaFin

## Datasheet

| **Product** |  Document
| --- | --- |
| balenaFin v1.0 | [PDF datasheet](https://github.com/balena-io/balena-fin/raw/master/documentation/PDF/balenaFin/v1.0/datasheet/datasheet.pdf) |
| balenaFin v1.1 | [PDF datasheet](https://github.com/balena-io/balena-fin/raw/master/documentation/PDF/balenaFin/v1.1/datasheet/datasheet.pdf) |
| modular DIN rail case | [PDF datasheet](https://github.com/balena-io/balena-fin/raw/master/documentation/PDF/accesories/modular_DIN_rail_case/datasheet/datasheet.pdf) |

## Schematics

| **Product** |  Document
| --- | --- |
| balenaFin v1.0 | [PDF schematics](https://github.com/balena-io/balena-fin/raw/master/documentation/PDF/balenaFin/v1.0/schematics/20173009_V8_schematics.pdf) |
| balenaFin v1.1 | [PDF schematics](https://github.com/balena-io/balena-fin/raw/master/documentation/PDF/balenaFin/v1.1/schematics/20173009_balena-fin_v10.pdf) |
| balenaFin v1.1.1 | [PDF schematics](https://github.com/balena-io/balena-fin/raw/master/documentation/PDF/balenaFin/v1.1.1/schematics/20200408_balena-fin_v11.pdf)|
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

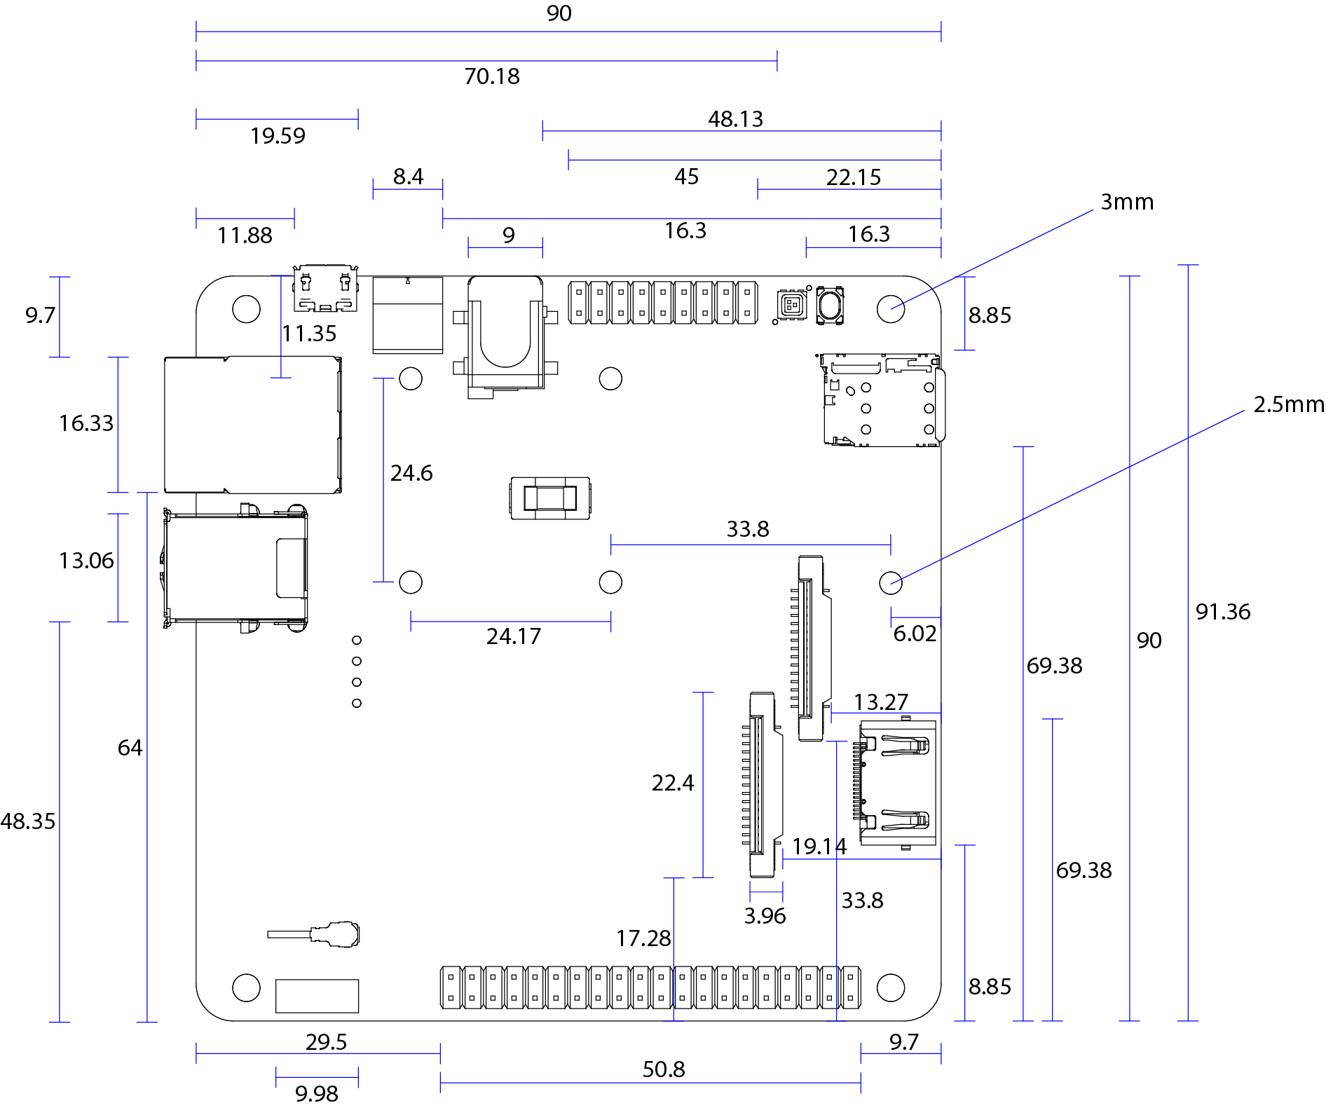
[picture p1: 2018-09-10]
documentation/markdown/balenaFin/v1.1/datasheet/pictures/fin_mechanical_top.png

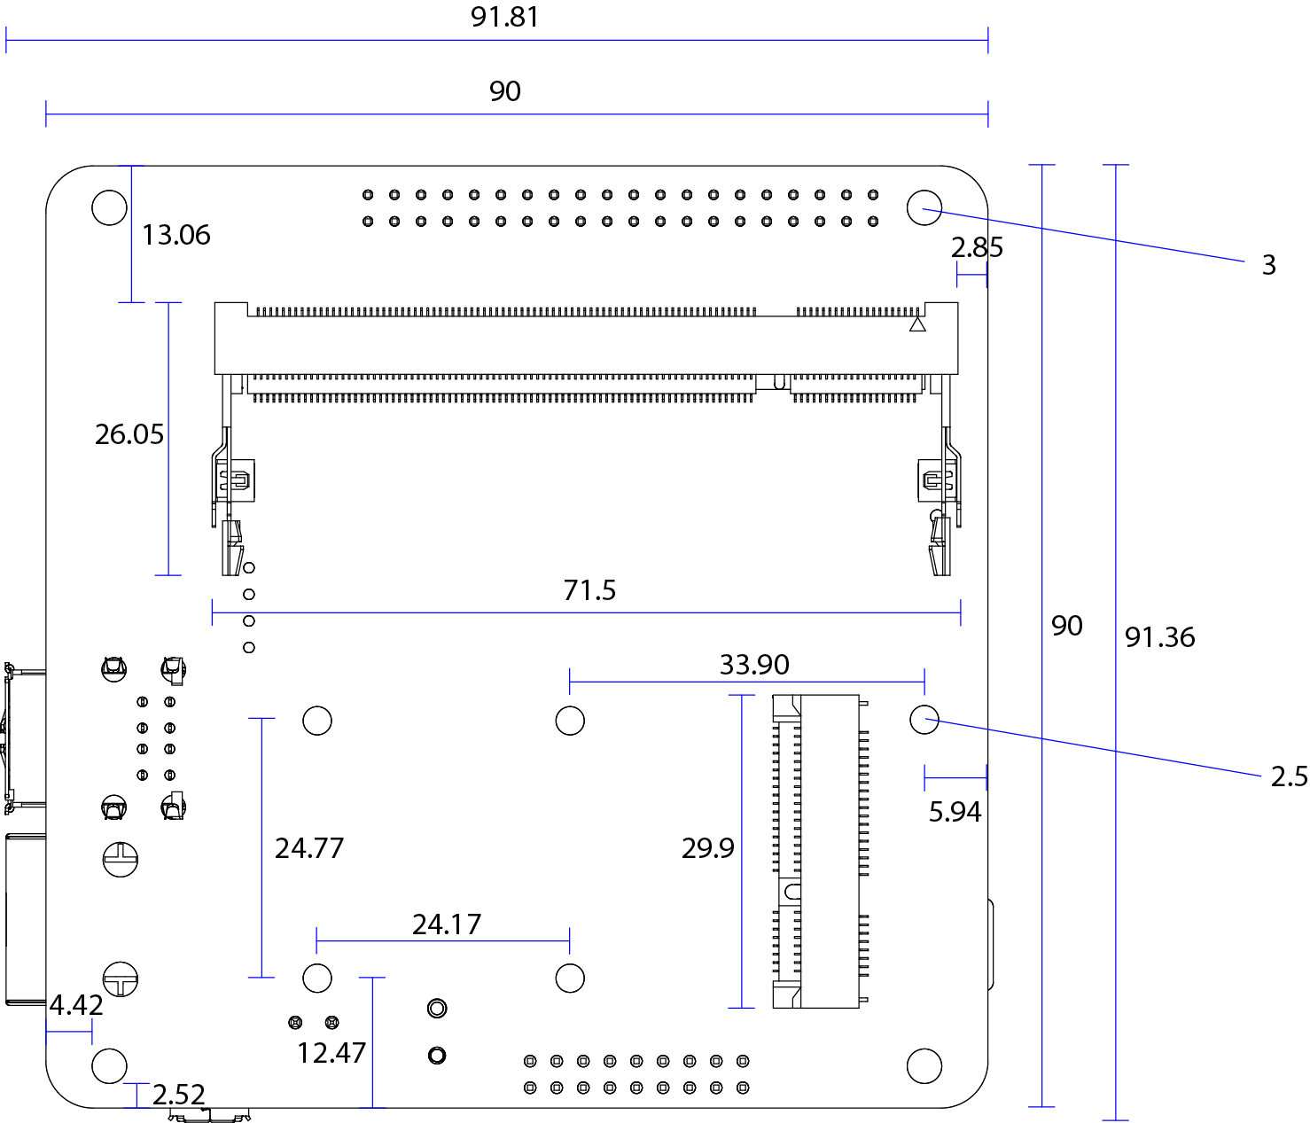
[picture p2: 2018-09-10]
documentation/markdown/balenaFin/v1.1/datasheet/pictures/fin_mechanical_bottom.png

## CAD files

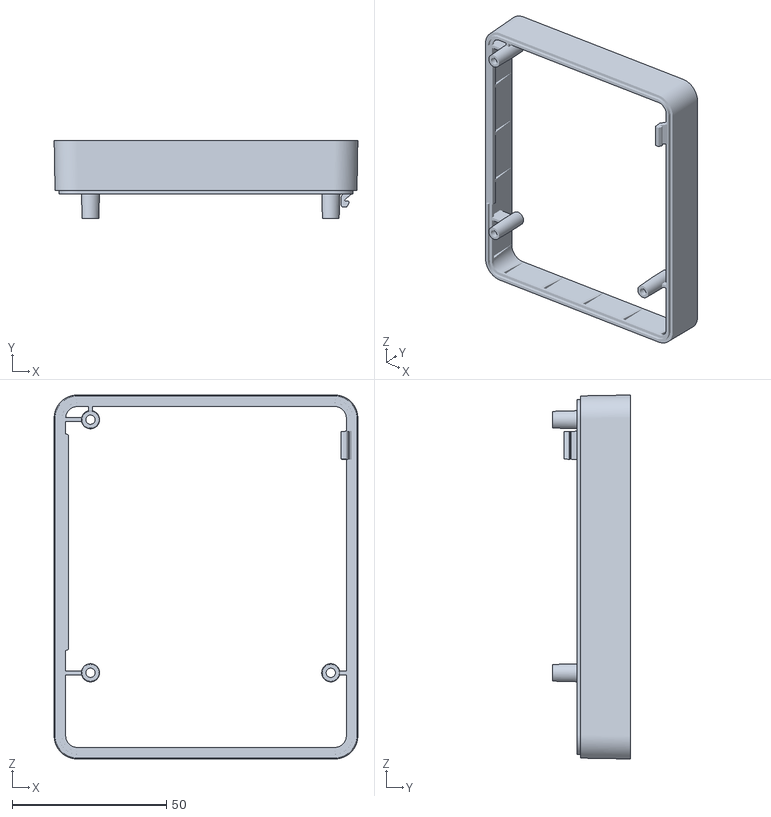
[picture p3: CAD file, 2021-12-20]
documentation/CAD/accesories/modular_DIN_rail_case/blind-ring/Bling ring.stl
98.4 x 25.2 x 117.9

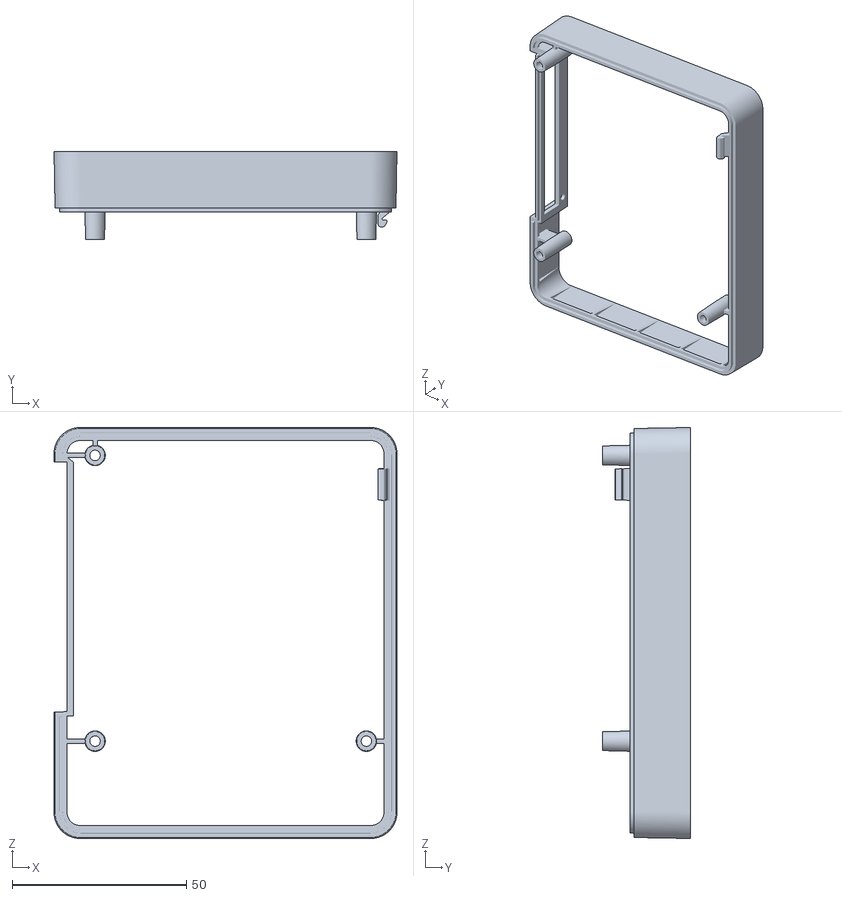
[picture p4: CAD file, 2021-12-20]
documentation/CAD/accesories/modular_DIN_rail_case/v2/Phoenix ring.stl
98.4 x 25.2 x 117.9

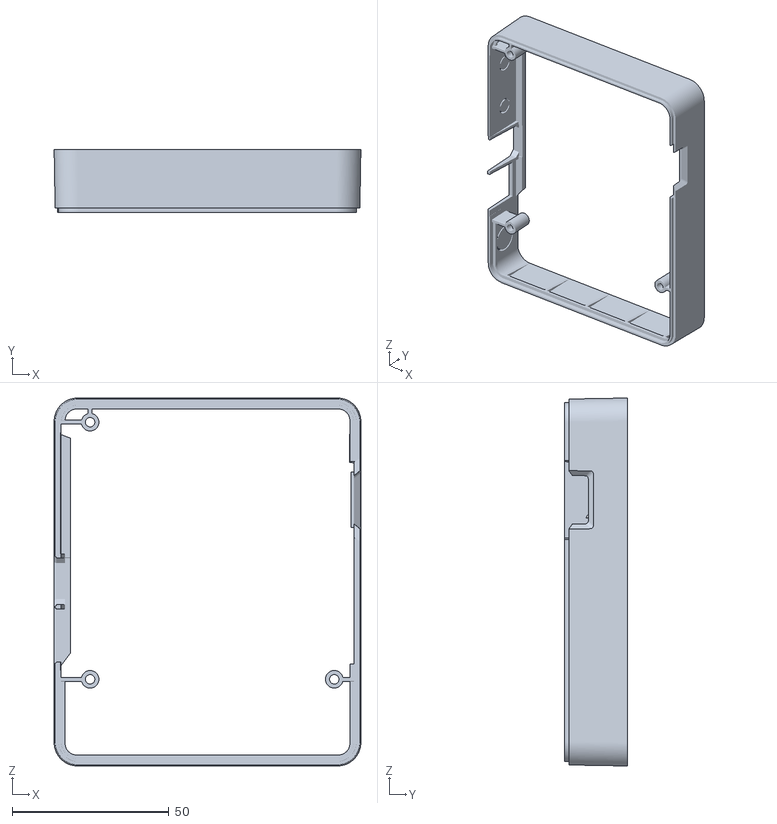
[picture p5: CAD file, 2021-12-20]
documentation/CAD/accesories/modular_DIN_rail_case/v2/Fin ring.stl
97.8 x 19.9 x 117.4

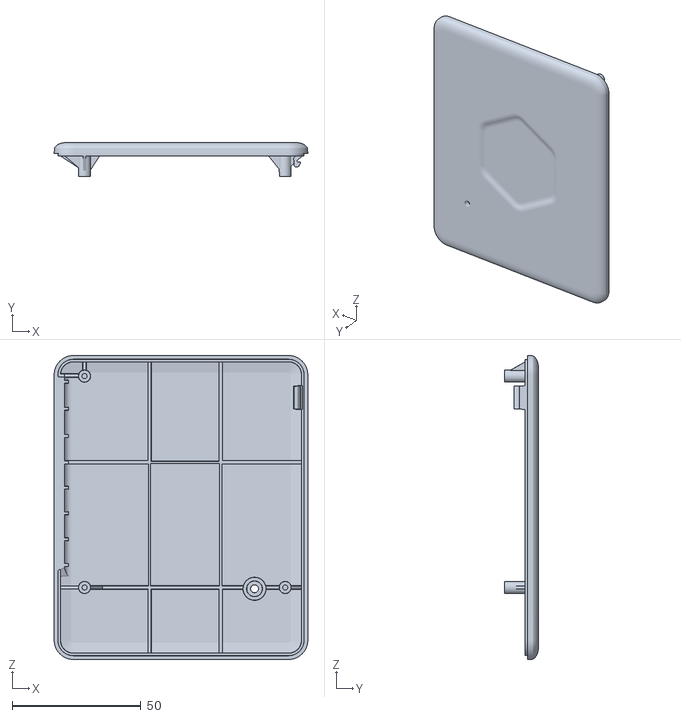
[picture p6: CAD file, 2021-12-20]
documentation/CAD/accesories/modular_DIN_rail_case/v2/top lid.stl
98.4 x 13.3 x 117.9

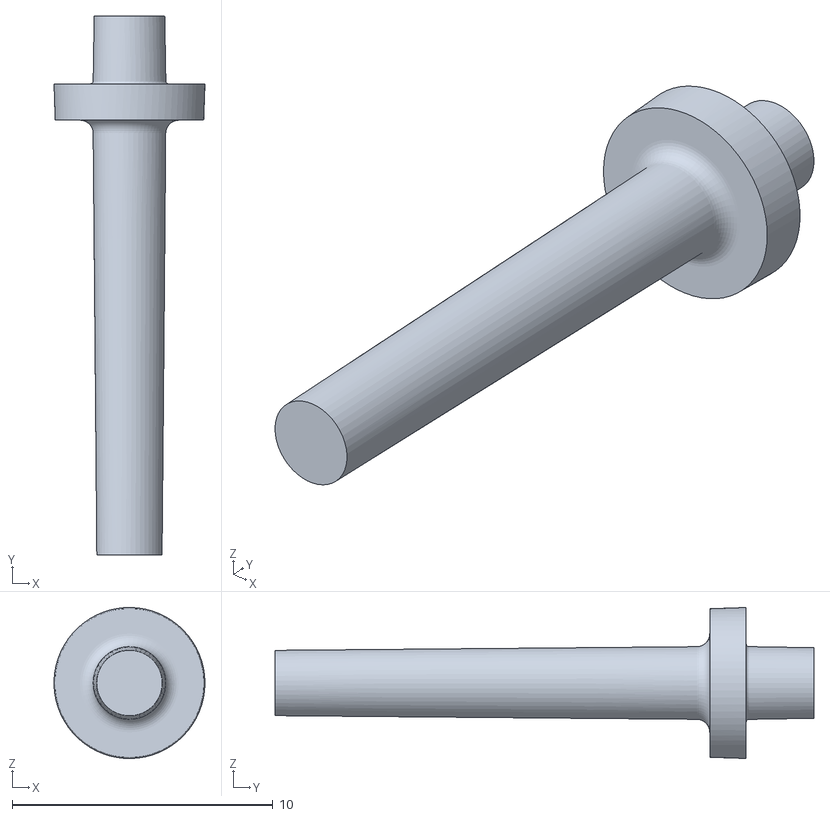
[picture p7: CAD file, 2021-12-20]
documentation/CAD/accesories/modular_DIN_rail_case/v2/light guide.stl
5.80 x 20.7 x 5.80

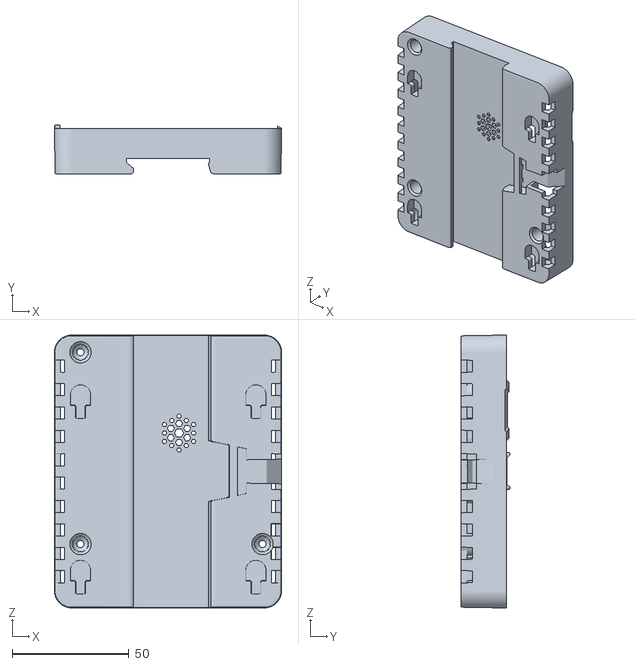
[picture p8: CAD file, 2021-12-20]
documentation/CAD/accesories/modular_DIN_rail_case/v2/bottom.stl
97.2 x 21.1 x 116.7

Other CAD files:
documentation/CAD/balenaFin/v1.1/2D/TOPOTOP.DXF
documentation/CAD/balenaFin/v1.1/2D/TOPOBOTTOM.dxf

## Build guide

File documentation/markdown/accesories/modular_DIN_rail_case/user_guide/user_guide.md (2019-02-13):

<center>

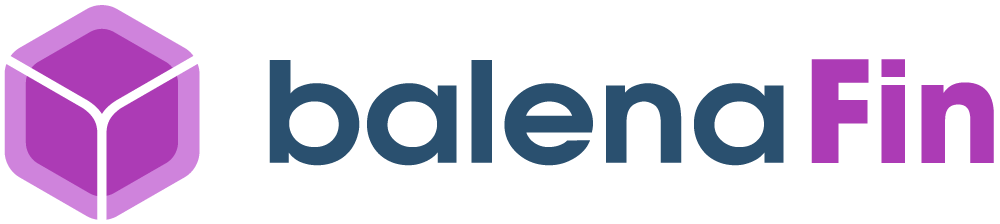
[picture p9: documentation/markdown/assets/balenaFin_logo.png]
Fin logo


| **Document Type** | User Guide |
| --- | --- |
| **Product ID:** | FIN00028 (v2) |
| **Product Name** | Modular DIN-rail Case |
| **Document Version** | 0.0.1 |
| **Author** | Nicolas Tzovanis |
| **State (Draft/Proposed/Approved)** | Draft |

</center>

## Revision history

<center>

| **Date (dd/mm/yyyy)** | **Version** | **Author** | **Description** |
| --- | --- | --- | --- |
| 08/02/2019 | 0.0.1 | Nicolas Tzovanis | First release |

</center>

# 1. Introduction

The modular DIN-rail case is the official case for the balenaFin. It exposes mosts ports to the outside through panel mount connectors. The modular ring-based design of the case allows the use of Hardware Attached on Top (HAT) modules without the need of designing a case from scratch.
In order to expose most of the balenaFin internal ports, we designed two versions of the case:

### Standard version

This version exposes the basic balenaFin ports:
- 2 x USB
- Ethernet (RJ45)
- HDMI
- Barrel jack power connector
- 2 x External antenna mounting points

### Phoenix Ring version

In addition to the standard version, the Phoenix ring version has a second ring with a 15 position phoenix connector that exposes pins from the balenaFin HAT connectos and from the balenaFin co-processor. See the datasheet for the pinout. 

Both versions provide DIN-rail and VESA mounting on the bottom of the case.

# 2. What's in the box?

## 2.1 No phoenix ring version

1. Modular DIN-rail Case for balenaFin  
    1.1 - Bottom  
    1.2 - Lid  
    1.3 - balenaFin ring  
2. Din rail clip
3. M3x8mm self-tapping screw
4. 3 x M3x20mm self-tapping screws
5. DC-099 5.5 x 2.1mm DC Power Jack panel mount

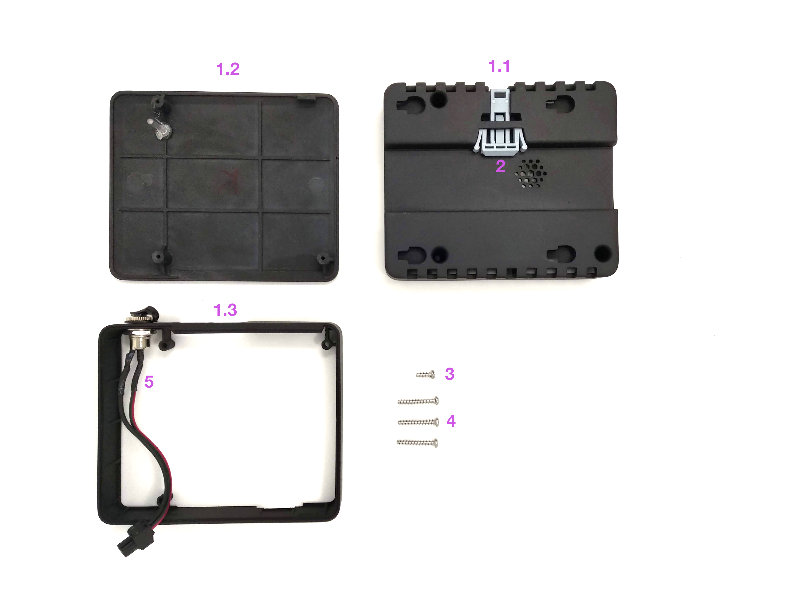
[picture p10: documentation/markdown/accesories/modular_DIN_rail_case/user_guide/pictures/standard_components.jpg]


## 2.2 Phoenix ring version

1. Modular DIN-rail Case for balenaFin  
    1.1 Bottom  
    1.2 Lid  
    1.3 balenaFin ring  
    1.4 Phoenix ring 
2. Din rail clip
3. DC-099 5.5 x 2.1mm DC Power Jack panel mount
4. 15-POS female phoenix panel mount
5. 15-POS ribbon cable
6. M3x8mm self-tapping screw
7. 3 x M3x20mm self-tapping screws
8. Phoenix ring HAT board

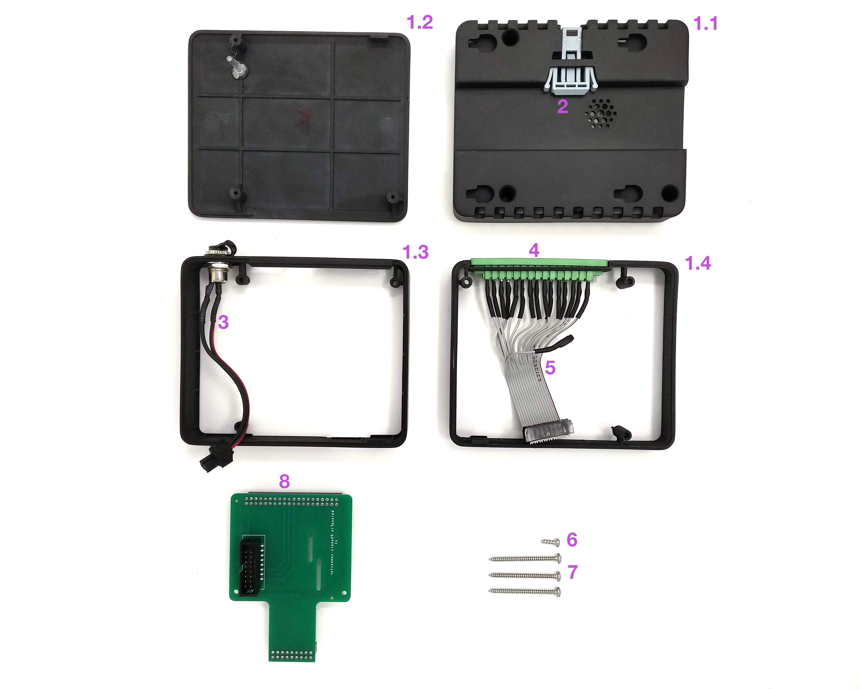
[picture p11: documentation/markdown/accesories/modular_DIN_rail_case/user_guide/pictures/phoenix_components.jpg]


# 3. Assembly instructions

## 3.1 Attaching the balenaFin 

**Items needed**
- balenaFin board
- M3 x 8mm screw
- Case bottom

**Instructions**
- Place the bottom part of the case on the table.
- Locate the blind boss. It's the hole with the thinest plastic walls.

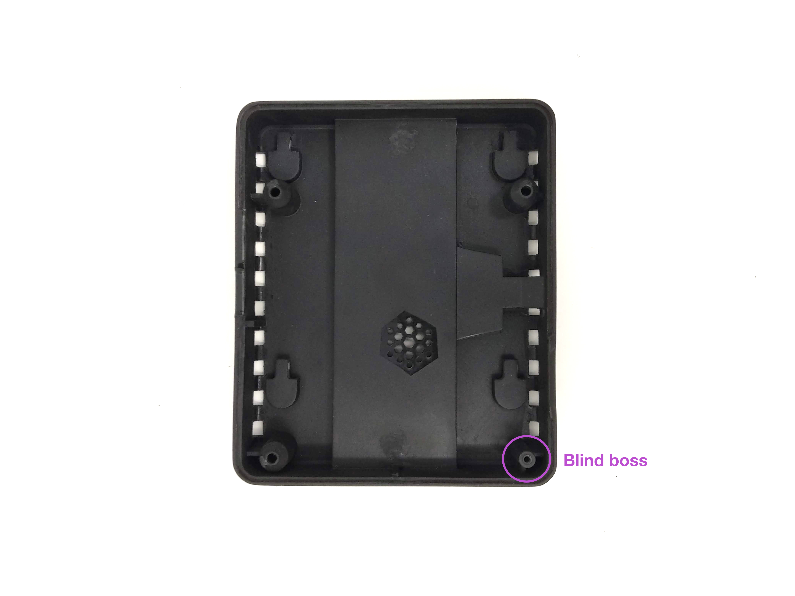
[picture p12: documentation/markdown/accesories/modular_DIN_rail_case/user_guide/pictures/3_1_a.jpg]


- Place the balenaFin (compute module facing down) so that the hole closest to the HAT header aligns with the blind boss.
- Use the M3 x 8mm screw to fix the balenaFin to the case in the blind boss.

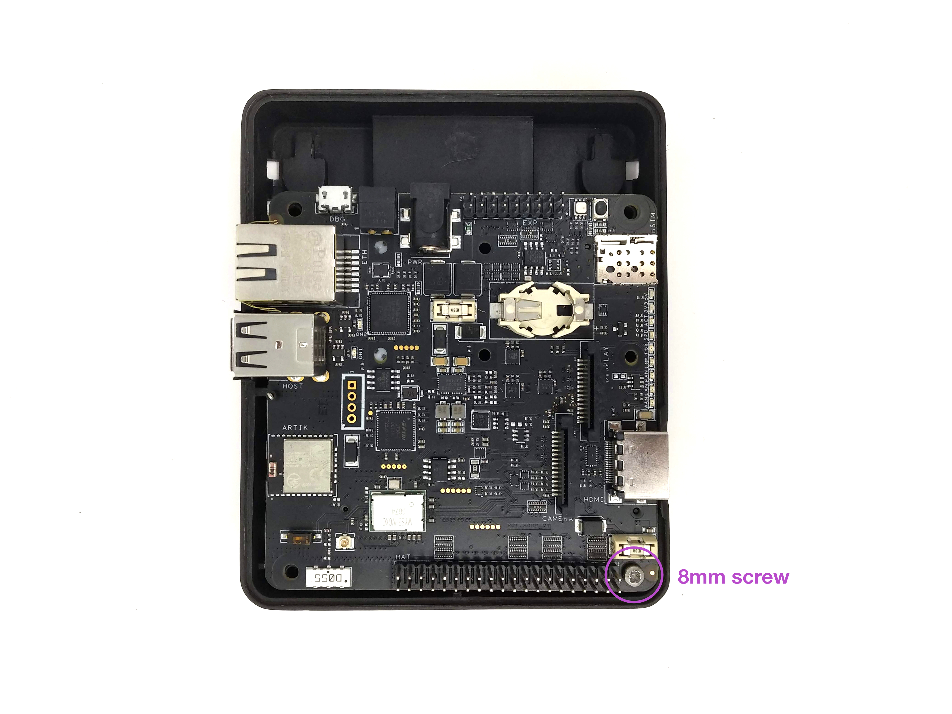
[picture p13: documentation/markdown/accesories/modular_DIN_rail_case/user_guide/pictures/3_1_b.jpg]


Note: make sure the balenaFin is properly secure without overtighetning the screw to avoid breaking the plastic boss.

## 3.2 Assembling the rings

**Items needed**
- Assembly from step 3.1
- balenaFin ring
- Phoenix ring (only if assembling the phoenix ring version)
- Phoenix ring HAT board

**Instructions**
- Place the balenaFin ring on top of the assembly from step 3.1. Make sure the openings align and the missing boss of the ring aligns with the blind boss from step 3.1
- Connect the pre-assembled DC Panel Power Jack to the balenaFin.

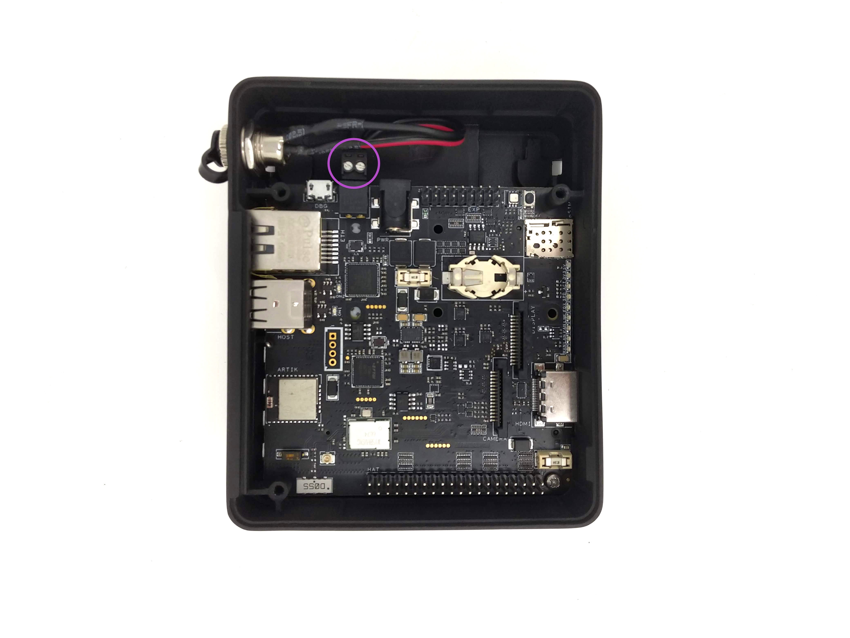
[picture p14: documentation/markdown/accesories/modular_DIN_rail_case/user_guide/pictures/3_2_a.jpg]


_If not using phoenix ring version, skip to 3.3_
- Connect the Phoenix ring HAT board to the balenaFin.
- Place the phoenix ring on top, making sure the missing boss of the ring aligns with the missing boss from the balenaFin ring.
- Connect the 15-POS ribbon cable to the phoenix ring HAT board.

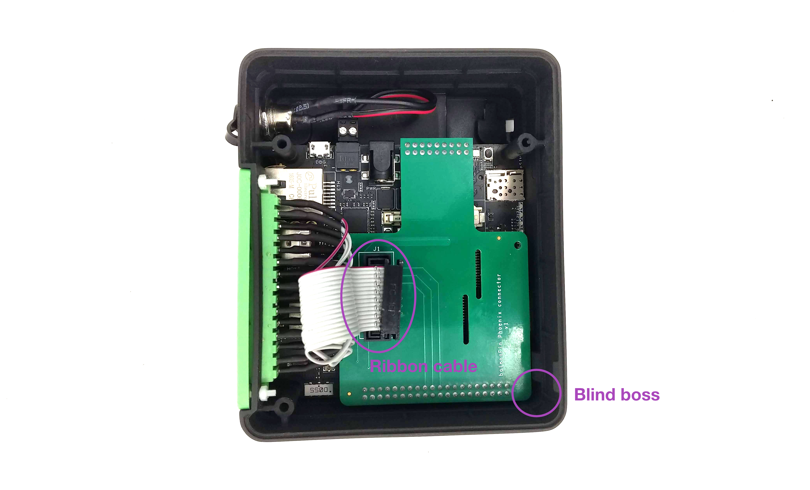
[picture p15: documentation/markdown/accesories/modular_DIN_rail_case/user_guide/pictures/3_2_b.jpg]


## 3.3  Final assembly

**Items needed**
- Assembly from step 3.2
- Case lid
- 3 x M3x20mm self-tapping screws
- 3 x M3x38mm self-tapping screws (only if assembling the phoenix ring version)

### 3.3.1 Instructions for standard version

- Place the lid on top of the assembly from step 3.2. Make sure the light pipe from the lid aligns with the RGB LED on the balenaFin.

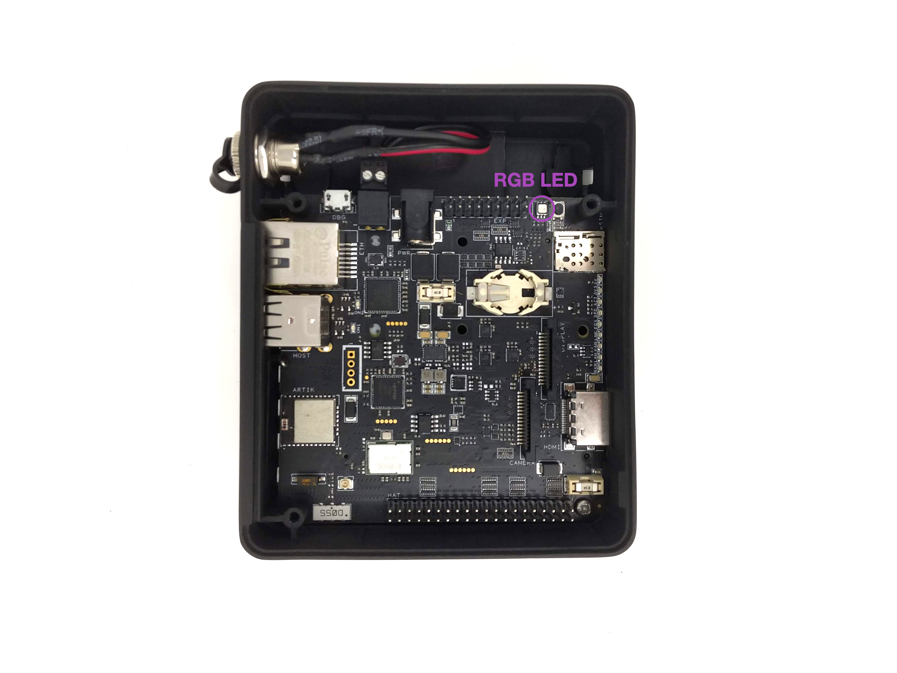
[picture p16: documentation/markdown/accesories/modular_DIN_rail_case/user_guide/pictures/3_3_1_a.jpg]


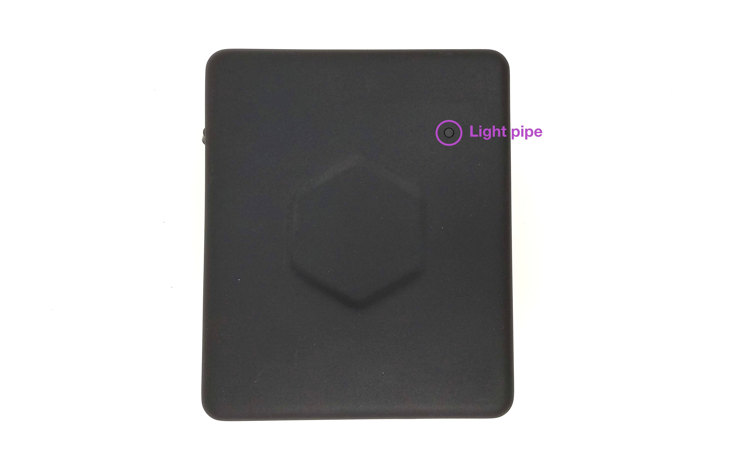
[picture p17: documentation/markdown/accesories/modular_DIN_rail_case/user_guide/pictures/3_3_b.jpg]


- Flip the whole assembly upside down to expose the bottom part of the case.
- Secure the assembly with the M3x20mm self-tapping screws.

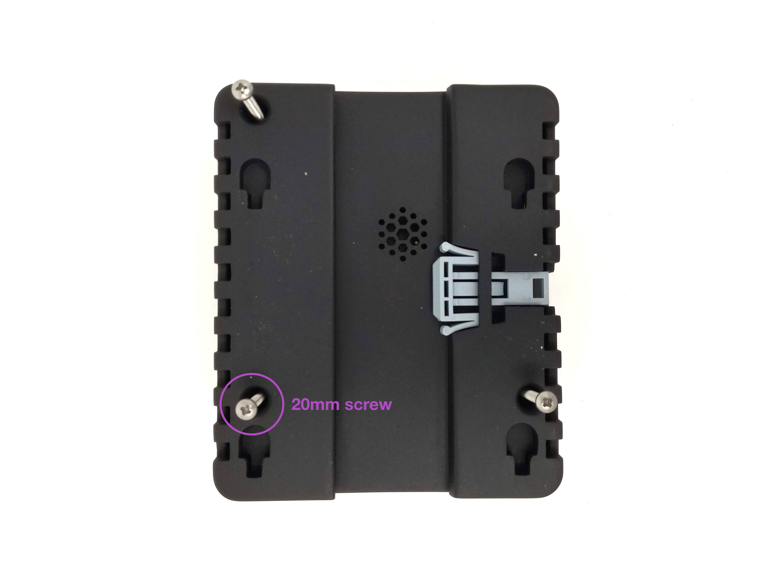
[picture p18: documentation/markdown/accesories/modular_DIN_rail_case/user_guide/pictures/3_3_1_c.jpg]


### 3.3.2 Instructions for phoenix version

- Place the lid on top of the assembly from step 3.2. Make sure the light pipe from the lid aligns with the RGB LED on the balenaFin.

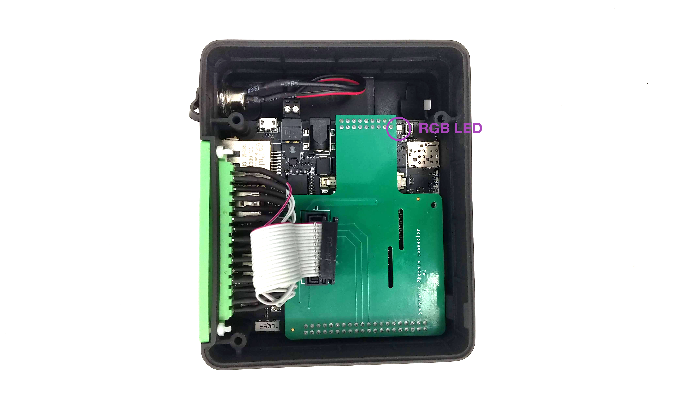
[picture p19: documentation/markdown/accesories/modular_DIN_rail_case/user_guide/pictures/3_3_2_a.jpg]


Fin block diagram

- Flip the whole assembly upside down to expose the bottom part of the case.\
- Secure the assembly with the M3x38mm self-tapping screws.

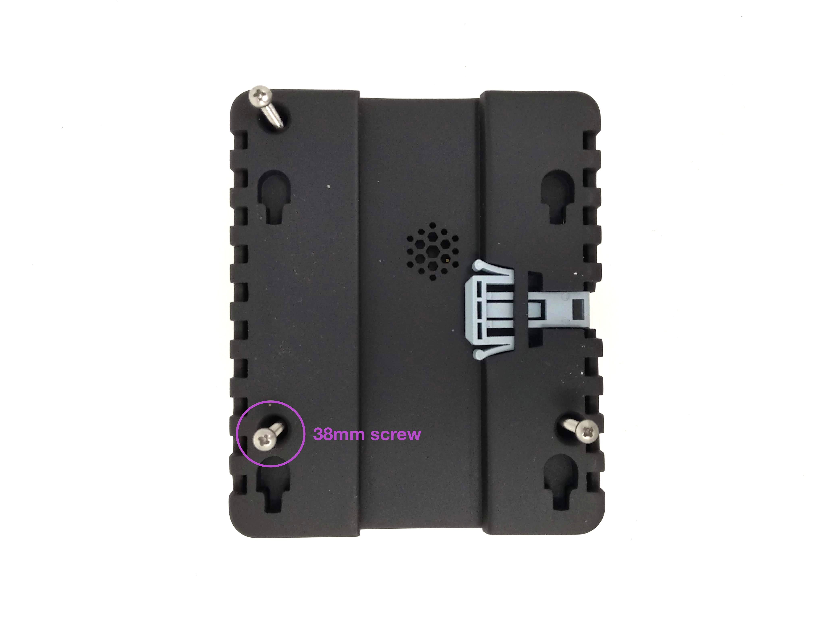
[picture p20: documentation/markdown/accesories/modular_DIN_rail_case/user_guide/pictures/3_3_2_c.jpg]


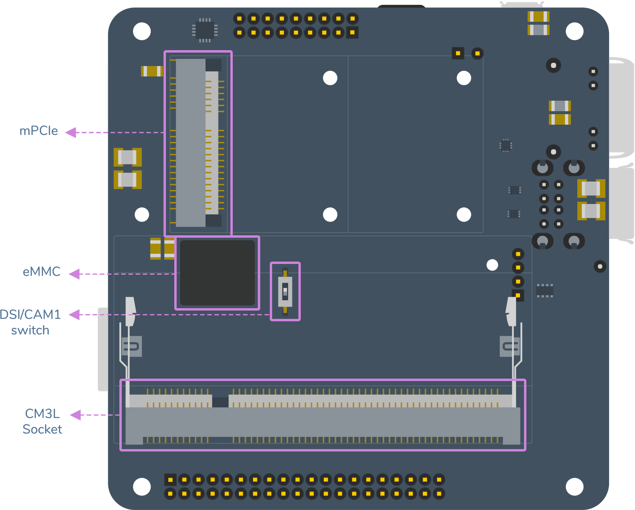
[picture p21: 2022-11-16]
documentation/markdown/balenaFin/v1.1/errata/pictures/getting_started_mapping_bottom_v1.1.png

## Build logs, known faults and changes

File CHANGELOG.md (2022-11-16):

# Change Log

All notable changes to this project will be documented in this file
automatically by Versionist. DO NOT EDIT THIS FILE MANUALLY!
This project adheres to [Semantic Versioning](http://semver.org/).

# v0.11.2
## (2022-11-16)

* Merge content from v1.1.1-fix repo [Heath Raftery]

# v0.11.1
## (2022-11-16)

* Remove protect-branch safety [Heath Raftery]
* Add simple npm test to satisfy Flowzone [Heath Raftery]
* Switch from balenaCI to flowzone [Heath Raftery]

# v0.11.0
## (2022-10-14)

* Update to W15.68.19.p59-15.26.19.p59-C4X15698_A2 [Zahari Petkov]

# v0.10.9
## (2022-04-01)

* Adds released datasheets [Alex]
* corrected battery type [Konstantinos Mouzakis]

# v0.10.8
## (2022-02-25)

* Added updated case pdf [Alex]

# v0.10.7
## (2022-02-25)

* updated version of the case datasheet md [Konstantinos Mouzakis]

# v0.10.6
## (2022-02-24)

* Updated case dimensions on the datasheet images [Konstantinos Mouzakis]

# v0.10.5
## (2022-01-11)

* Fixes balenaFin v1.1 voltage range in docs [Alex]

# v0.10.4
## (2021-12-21)

* Added test report and certificate for IEC62368 [Nicolas Tzovanis]
* Added product description for IEC approval [Nicolas Tzovanis]

# v0.10.3
## (2021-12-15)

* updated case files [Konstantinos Mouzakis]

# v0.10.2
## (2021-10-14)

* Added information on datasheet for IEC report compliance [Nicolas Tzovanis]

# v0.10.1
## (2021-08-24)

* Bump highlight.js from 9.13.1 to 9.18.5 [dependabot[bot]]

# v0.10.0
## (2021-08-23)

* Added examples from balenafin-examples repo for unification [Alex Bucknall]

# v0.9.2
## (2021-06-03)

* Y2K38 timestamp tweaks [Zahari Petkov]

# v0.9.1
## (2021-04-29)

* Fixed a typo in the PDF file name [MTolba]

# v0.9.0
## (2021-04-27)

* Added source and instruction for building sd8887 driver [Alex Bucknall]

# v0.8.6
## (2021-01-25)

* Fixed path for ISED certificates [Nicolas Tzovanis]

# v0.8.5
## (2021-01-15)

* Added latest ISED certificate [Nicolas Tzovanis]

# v0.8.4
## (2020-12-29)

* balena-fin-overlay: Update for kernel 5.4 [Alex Gonzalez]

# v0.8.3
## (2020-12-28)

* Added REACH declaration [Nicolas Tzovanis]
* Added RoHS conformity declaration [Nicolas Tzovanis]

# v0.8.2
## (2020-12-07)

* Added dxf files, created a folder for the 3D files [MTolba]

# v0.8.1
## (2020-11-23)

* Added blind-ring stl and step files [Nicolas Tzovanis]

# v0.8.0
## (2020-10-15)

* Added latest CE test documents [Nicolas Tzovanis]

# v0.7.3
## (2020-06-26)

* Updated PDFs and changelogs [Alex Bucknall]

# v0.7.2
## (2020-06-26)

* Adds BGM111 ports to datasheet [Alex Bucknall]

# v0.7.1
## (2020-06-23)

* Updated PDF files [Nicolas Tzovanis]
* Fixed conformity links [Nicolas Tzovanis]

# v0.7.0
## (2020-06-23)

* Improved supply coverage wording and certifications. [Nicolas Tzovanis]
* Added new FCC test reports [Nicolas Tzovanis]

# v0.6.9
## (2020-03-18)

* Fixed co-location [Nicolas Tzovanis]
* Fixed link for NB Certificate [Nicolas Tzovanis]
* Added missing test reports and unified FCC_ID reports [Nicolas Tzovanis]

# v0.6.8
## (2020-01-11)

* Updated COT details in WiFi CE reports [Nicolas Tzovanis]

# v0.6.7
## (2019-12-31)

* Added latest version of CE-WiFi test reports [Nicolas Tzovanis]

# v0.6.6
## (2019-08-07)

* Added light version of Fin 3D [Nicolas Tzovanis]

# v0.6.5
## (2019-07-11)

* Fix HAT pinout on phoenix case [Nicolas Tzovanis]

# v0.6.4
## (2019-07-04)

* Fix phoenix ring pinout information [Nicolas Tzovanis]

# v0.6.3
## (2019-06-24)

* Improve description of USB header. [Nicolas Tzovanis]

# v0.6.2
## (2019-06-06)

* Fixed pinout for HAT header (pin_13) [Nicolas Tzovanis]

# v0.6.1
## (2019-04-16)

* Fix conformity.md link [Nicolas Tzovanis]

# v0.6.0
## (2019-04-12)

* Added conformity docs and index [Nicolas Tzovanis]

# v0.5.1
## (2019-03-20)

* Update DOCUMENTATION.md [Carlo Maria Curinga]

# v0.5.0
## (2019-03-02)

* Generate 0.0.3 datasheet [curcuz]
* add link to v1.1 user manual website [curcuz]

# v0.4.6
## (2019-02-22)

* update index for v1.1 CAD file [curcuz]
* add v1.1 CAD file [curcuz]

# v0.4.5
## (2019-02-22)

* Add a documentation index for better UX [curcuz]

# v0.4.4
## (2019-02-22)

* add changelog to the datasheet [curcuz]
* generate PDF datasheet with temp range fix [curcuz]
* fix temperature range min value [curcuz]

# v0.4.3
## (2019-02-21)

* Add V1.1 schematics [curcuz]

# v0.4.2
## (2019-02-21)

* Correct typo [Chris Crocker-White]

# v0.4.1
## (2019-02-21)

* generate v1.1 datasheet with bgm111 references [curcuz]
* reference to BGM111 for co-processor docs [curcuz]

# v0.4.0
## (2019-02-21)

* re-generate V1.1 datasheet pdf with updated block diagram [curcuz]
* update block diagram according to v1.1 architecture [curcuz]
* update v1.1 PDF datasheet with compressed imgs [curcuz]
* compress device mapping images [curcuz]
* Add missing pointer to device mapping ID for RF switch when mentioned [curcuz]
* generate and add PDF for v1.1 datasheet [curcuz]
* fix fuses ordering [curcuz]
* Add reference to the Fuses we have on the HAT and PWR IN [curcuz]
* update PCB mapping and definitions [curcuz]
* v1.1 init [curcuz]

# v0.3.0
## (2019-02-13)

* wrap balenaFin datasheet in HW version folders [curcuz]

# v0.2.2
## (2019-02-13)

* Fix images and wording [Nicolas Tzovanis]

# v0.2.1
## (2019-02-13)

* Generated final PDF [Nicolas Tzovanis]
* Add phoenix HAT and IDC cable to datasheet [Nicolas Tzovanis]

# v0.2.0
## (2019-02-11)

* Improved README information for release [Nicolas Tzovanis]

# v0.1.6
## (2019-01-31)

* Fix merged rows on radio table [Nicolas Tzovanis]

# v0.1.5
## (2019-01-18)

* prefix: Added temperature range errata
* prefix: Fix title bold
* prefix: Update thermal range on datasheet
* Fix errata markdown
* Add case datasheet
* Add headers pinout to datasheet
* Improve block diagram
* Fix markdown table
* Add Fin CAD to docs
* Remove unnecesary power legend
* Fix errata logo
* Add errata to pdf path
* Add datasheet for modular case
* Center cover tables
* Add page break for errata
* Add revision history for case datasheet
* Clean up folders for improved readability
* Improved FAQ readability
* Rename case datasheet for maintaining consistency
* Add case CAD
* Improved balenaFin datasheet readability
* Add generated PDFs
* Add phoenix ring information on the datasheet
* Change status of documents to proposed for pr
* support both cam/disp and double camera setup for Fin 1.1.0
* Add `balena-fin`overlay
* prefix: Added node engine check
* make the destination a parameter of the document definition
* split destination folder creation from pdf files creation
* Fix pdf destination path
* Improve readability of case datasheet
* Add remaining PDFs

# v0.1.4
## (2019-01-15)

* Add `balena-fin`overlay [curcuz]

# v0.1.3
## (2019-01-15)

* make the destination a parameter of the document definition [curcuz]

# v0.1.2
## (2019-01-11)

* prefix: Added node engine check [Alex Bucknall]

# v0.1.1
## (2019-01-10)

* Update README.md [Carlo Maria Curinga]

# v0.1.0
## (2018-12-20)

* Set private: true in package.json [Giovanni Garufi]
* prefix: Remove datasheet.pdf [Nicolas Tzovanis]
* prefix: Add PDF datasheet manually [Nicolas Tzovanis]
* prefix: Rename etcher.io -> balena.io/etcher [Nicolas Tzovanis]
* prefix: Rename Balena Fin -> balenaFin [Nicolas Tzovanis]
* prefix: Removed manual [Nicolas Tzovanis]

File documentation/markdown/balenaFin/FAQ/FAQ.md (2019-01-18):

<center>

Fin logo

| **Document Type** | FAQ |
| --- | --- |
| **Product ID:** | BLNFN100001 (20173009) |
| **Product Name** | BalenaFin |
| **Product Version** | 1.0.0 |
| **Document Version** | 1.0.0 |
| **Author** | Carlo Maria Curinga |
| **State (Draft/Proposed/Approved)** | Proposed |

</center>

## Revision history

<center>

| **Date (dd/mm/yyyy)** | **Version** | **Author** | **Description** |
| --- | --- | --- | --- |
| 10/01/2019 | 0.0.1 | Carlo Maria Curinga | First release |

</center>

## FAQ

### Is Balena Fin compatible with the Raspberry Pi Compute Module with integrated eMMC (CM1, CM3) ?
No. Balena Fin is only compatible with the eMMC-less Raspberry Pi compute modules (aka `lite`)

### Is Balena Fin compatible with standard rasbian or its derivates?
It will boot, but some peripherials won't work without some minor modification:

* WiFi+BT: while the `balena-fin` device tree overlay is merged upstream, you still need to set in in your `config.txt` ( `dtoverlay=balena-fin` ). You also need to compile and install the drivers, a process we are working on simplifying. In the meantime, we can provide you guidance on how to do it yourself
* RTC (Real Time Clock): while the `balena-fin` device tree overlay is merged upstream, you still need to set in in your `config.txt` ( `dtoverlay=balena-fin` ).
* RGB LED: while the `balena-fin` device tree overlay is merged upstream, you still need to set in in your `config.txt` ( `dtoverlay=balena-fin` ).
* miniPCIe airplane mode switch GPIO: while the `balena-fin` device tree overlay is merged upstream, you still need to set in in your `config.txt` ( `dtoverlay=balena-fin` ).
* DSI and CSI connectors (camera and display) + automatic HAT identification over I2C: As per the standard Raspberry Pi Foundation design (dt-blob.bin section of https://www.raspberrypi.org/documentation/hardware/computemodule/cm-peri-sw-guide.md ) you need to add the Balena Fin [dt-blob.bin](https://github.com/resin-io/balena-fin/raw/master/software/dt-blob/dt-blob.bin) in the root of the boot partition

### Is Balena Fin HAT compliant?
Yes it is, including power over HAT (5V @2.5A)

### Can I deploy Balena Fin in my Raspberry Pi 3 resin.io application?
Yes, we support mixed fleet https://resin.io/blog/evolve-your-fleet-manage-multiple-device-types-in-one-application/

### Does the RTC always run on its battery?
No - the RTC only runs on its battery when the device is powered off. This means that the real battery lifetime is way longer than the nominal one.

### How can I power Balena Fin?
You can power the board from the DC 5.5/2.1mm barrel jack connector or the 2 position phoenix connector with any input voltage between 6 and 24V with at least 12.5W (that is 12V @1A for example). You can also power Balena Fin from its 5V HAT pins with 5V @2.5A

### I cannot see any wireless interface listed, wifi does not work
Please make sure you have the `balena-fin` device tree overlay set in in your `config.txt` ( `dtoverlay=balena-fin` ).

### My HAT does not work on the Balena Fin unless I manually set up things that are automatic on a Raspberry Pi 3
Please make sure you have the Balena Fin [dt-blob.bin](https://github.com/resin-io/balena-fin/raw/master/software/dt-blob/dt-blob.bin) in the root of the boot partition

### Raspberry Pi camera or display don't work on my Balena Fin
Please make sure you have the Balena Fin [dt-blob.bin](https://github.com/resin-io/balena-fin/raw/master/software/dt-blob/dt-blob.bin) in the root of the boot partition

### WiFi signal is very weak
Please make sure you have the antenna switch on the right position based on your setup (OFF for internal antenna, ON for external antenna)

### My Balena Fin is heating a lot while running my application
The thermal performance of the Raspberry Pi Compute Module 3 Lite ( aka CM3L ) on Balena Fin has been benchmarked against the reference IO carrier board reference design from the Raspberry Pi Foundation and the Raspberry Pi 3 model B. IF your application does GPU intensive logic we suggest adding an heatsink to the SoC of the CM3L (the ones for the Raspberry Pi 3 model B are compatible)

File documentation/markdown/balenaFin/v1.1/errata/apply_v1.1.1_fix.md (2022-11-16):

# Hardware components modifications

| Reference (symbol) | Old MPN/value | New MPN/value | Notes |
| --- |---|---|---|
| R116 | 47K | 1K | same package and characteristics except for resistance value |
| R32 | 47K | 1K | same package and characteristics except for resistance value |

*TBD: add picture with position highlight for both symbols*

for both symbols, the process requires de-soldering of the old value component and soldering of the new value one. Package is 0402 so at least the following instruments must be used to ensure the outcome:

* precision solder iron with SMD thin tip
* third-hand
* LED illuminated lens arm

# Post-processing modifications

## 1. Version silkscreen cover

__1.1__ apply a `v1.1.1` sticker over the silkscreen that says `v1.1.0`

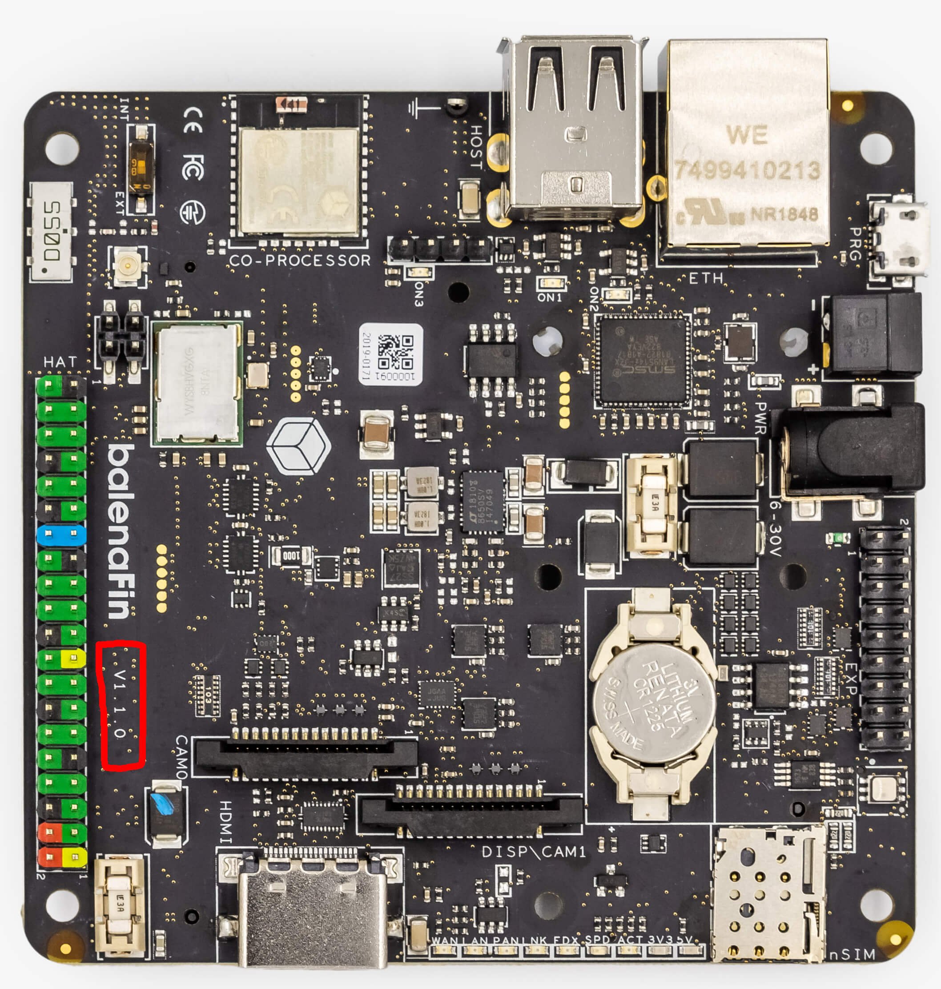
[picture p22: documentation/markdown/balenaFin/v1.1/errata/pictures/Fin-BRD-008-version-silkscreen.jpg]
Version silkscreen on device PCB highlight


## 2. Post processing programming

__2.1__ plug the Compute Module into the Device Under Test CM3L Socket (from now on, DUT).

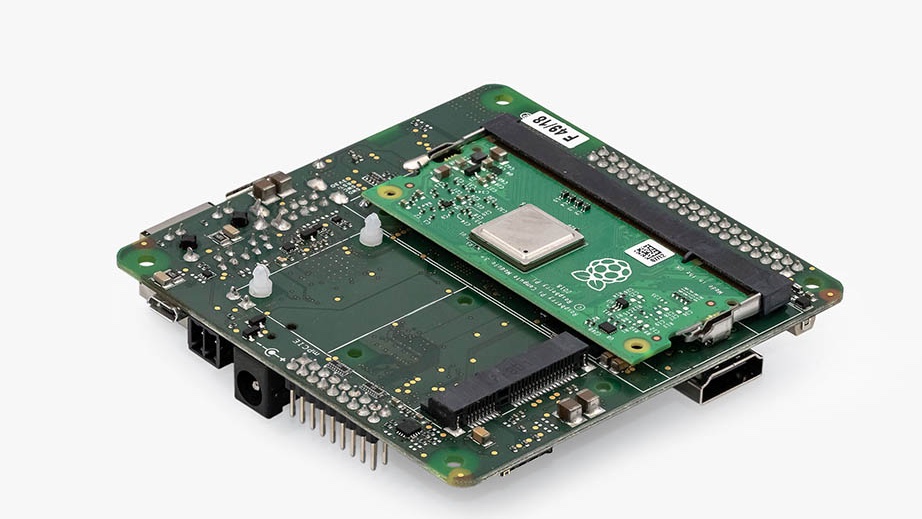
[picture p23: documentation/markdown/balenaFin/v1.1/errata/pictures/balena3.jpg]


__2.2__ connect the DUT to the provided QA instrument.

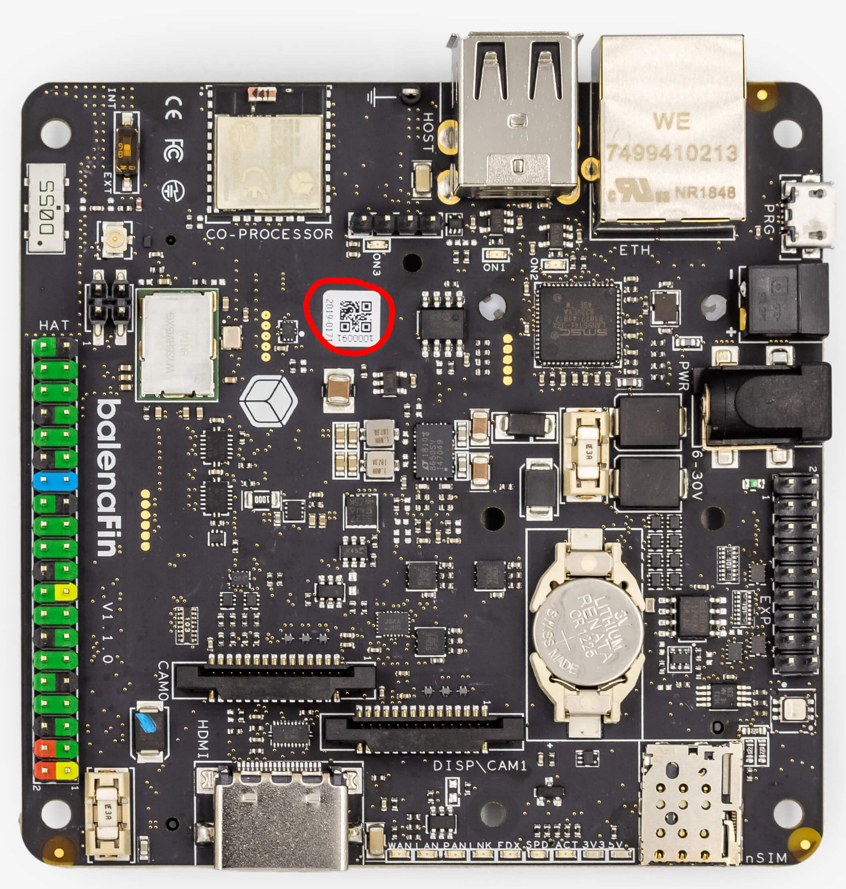
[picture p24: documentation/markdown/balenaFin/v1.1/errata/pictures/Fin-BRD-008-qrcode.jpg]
QRcode on device PCB highlight


__2.3__ scan the device QRcode with the QA instrument's scanner. wait for the instrument LED to blink purple (first testing flash), then white (testing), then purple again (retail flashing).

*TBD: add picture of the QA rig in processing mode*

__2.4__ at the QA Instrument URL a graphical user interface will provide QRcode information for the DUT. Use `v10ToV11 serial` for the full QRCODE string and `v10ToV11 uid` for the text.

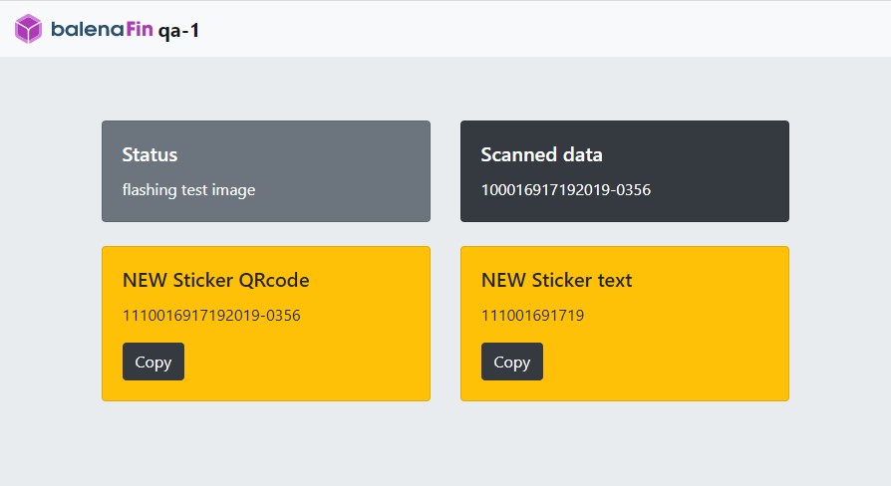
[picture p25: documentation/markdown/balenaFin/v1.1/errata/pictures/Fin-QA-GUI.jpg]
balenaFin QA GUI


__2.5__ print a new QRcode with the updated content.

__2.6__ when the instrument has completed the process, it will output on its LED and __the status card of the graphical user interface__ the result color code: 

* If GREEN, apply replacement QRcode sticker, package and stock the DUT. 

* If RED, stock the DUT in the `QA KO` container

* If YELLOW, device has been selected for a random sampling thermal test, and needs to be re-tested in heat chamber with temperature from ambient to 70 celsius (see paragraph 3 for more info)

*TBD: add picture of the QA rig in completion mode, one per cases (OK/KO/THERMAL)*

## 3. Random sampling thermal test

When the result of a test is YELLOW, it means the DUT has been picked for additional testing in heat chamber.
    
__3.1__ Simply repeat the procedure of chapter 2 but with the DUT in the heat chamber set to raise from ambient temperature to 70 celsius. 

__3.2__ The heat chamber QA instrument will keep its LED GREEN during the test and will switch to RED if the test fails. Test is considered complete when the chamber reaches 70 celsius. 

__3.3__ Refer to the test result handling as per chapter 2.

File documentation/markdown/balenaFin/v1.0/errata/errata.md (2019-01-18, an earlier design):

<center>

Fin logo

| **Document Type** | Errata |
| --- | --- |
| **Product ID:** | BLNFN100001 (20173009) |
| **Product Name** | balenaFin |
| **Document Version** | 0.0.1 |
| **Author** | Nicolas Tzovanis |
| **State (Draft/Proposed/Approved)** | Proposed |

</center>

## Errata history

<center>

| **Errata** | **Date (dd/mm/yyyy)** | **Description** | **Author** | **Impact** |  
| --- | --- | --- | --- | --- |
| 1 | 09/12/2018 | Environment operating temperature range | Nicolas Tzovanis | Information |  
</center>

Impact Definition: each erratum is marked with an impact, as defined below:

- Minor: workaround exists.
- Major: errata that do not conform to the data sheet or standard.
- Information: the device behavior is not ideal but acceptable. Typically, the data sheet will be
changed to match the device behavior.

## Errata Details

1. **Description:** balenaFin data sheet v0.0.4 states that the working temperature range is -25°C to 70°C. The real environmental working temperature range is 0°C to 70°C.  
**Impacts:** Whole board at low environment temperatures.  
**Workaround:** None.  
**Resolution:** The next revision of the data sheet, revision 0.0.5, will include a new specification for the valid temperature range.

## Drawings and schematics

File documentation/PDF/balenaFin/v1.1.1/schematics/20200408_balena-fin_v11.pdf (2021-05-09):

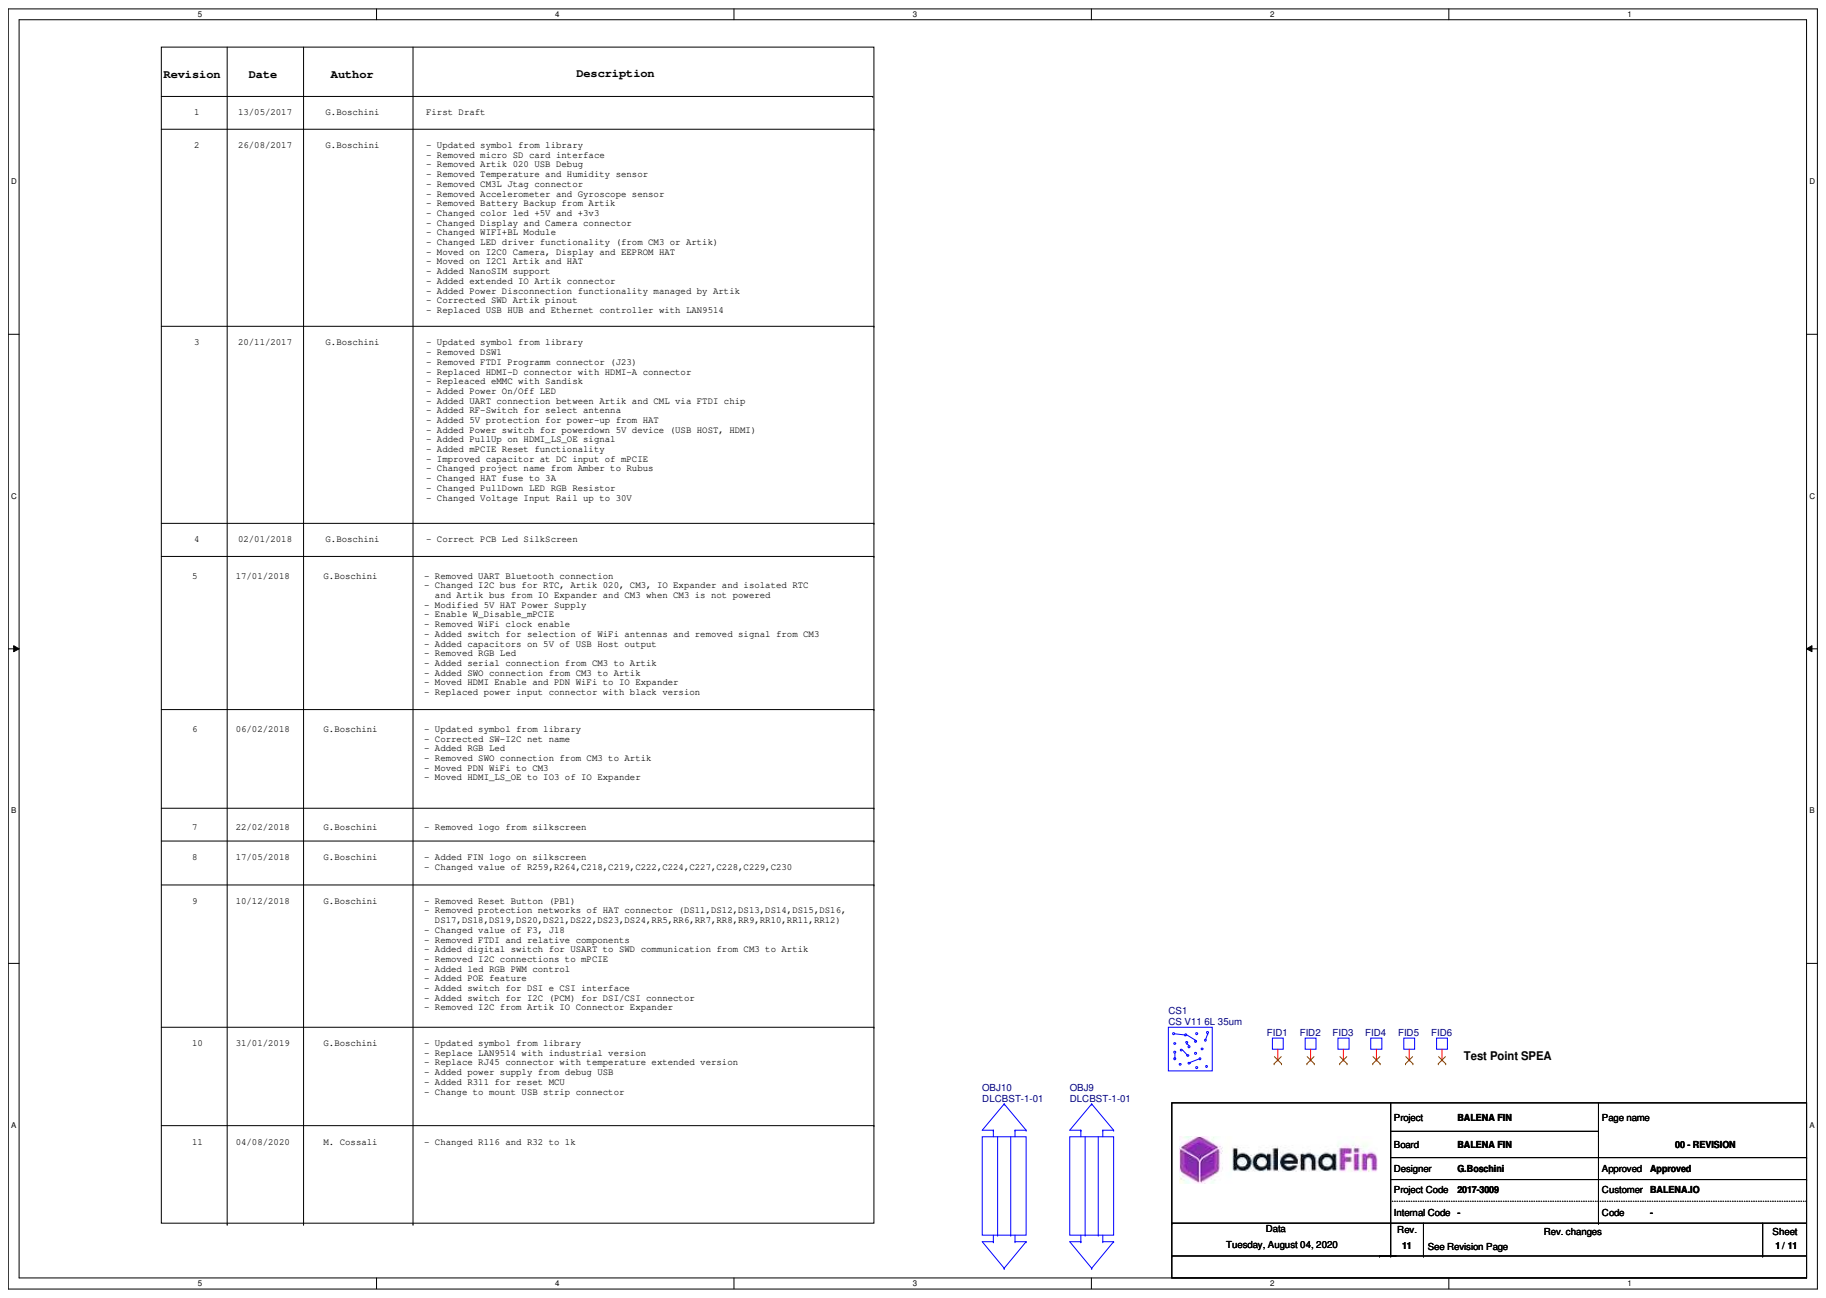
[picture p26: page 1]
Revision; Date; Author; Description; G.Boschini; First Draft; 2 G.Boschini 26/08/2017; - Updated symbol from library G.Boschini; G.Boschini 02/01/2018; - Correct PCB Led SilkScreen; - Removed UART Bluetooth connection G.Boschini; G.Boschini 06/02/2018; - Updated symbol from library; - Removed logo from silkscreen G.Boschini; - Removed Reset Button (PB1); 9 G.Boschini; - Added FIN logo on silkscreen; 8 G.Boschini; M. Cossali; - Changed R116 and R32 to 1k; Rev.; Rev. changes; Sheet; Board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

- Updated symbol from library
- Removed micro SD card interface
- Removed Artik 020 USB Debug
- Removed Temperature and Humidity sensor
- Removed CM3L Jtag connector
- Removed Accelerometer and Gyroscope sensor
- Removed Battery Backup from Artik
- Changed color led +5V and +3v3
- Changed Display and Camera connector
- Changed WIFI+BL Module
- Changed LED driver functionality (from CM3 or Artik)
- Moved on I2C0 Camera, Display and EEPROM HAT
- Moved on I2C1 Artik and HAT
- Added NanoSIM support
- Added extended IO Artik connector
- Added Power Disconnection functionality managed by Artik
- Corrected SWD Artik pinout
- Replaced USB HUB and Ethernet controller with LAN9514

- Removed DSW1
- Removed FTDI Programm connector (J23)
- Replaced HDMI-D connector with HDMI-A connector
- Repleaced eMMC with Sandisk
- Added Power On/Off LED
- Added UART connection between Artik and CML via FTDI chip
- Added RF-Switch for select antenna
- Added 5V protection for power-up from HAT
- Added Power switch for powerdown 5V device (USB HOST, HDMI)
- Added PullUp on HDMI_LS_OE signal
- Added mPCIE Reset functionality
- Improved capacitor at DC input of mPCIE
- Changed project name from Amber to Rubus
- Changed HAT fuse to 3A
- Changed PullDown LED RGB Resistor
- Changed Voltage Input Rail up to 30V

- Changed I2C bus for RTC, Artik 020, CM3, IO Expander and isolated RTC
and Artik bus from IO Expander and CM3 when CM3 is not powered
- Modified 5V HAT Power Supply
- Enable W_Disable_mPCIE
- Removed WiFi clock enable
- Added switch for selection of WiFi antennas and removed signal from CM3
- Added capacitors on 5V of USB Host output
- Removed RGB Led
- Added serial connection from CM3 to Artik
- Added SWO connection from CM3 to Artik
- Moved HDMI Enable and PDN WiFi to IO Expander
- Replaced power input connector with black version

- Corrected SW-I2C net name
- Added RGB Led
- Removed SWO connection from CM3 to Artik
- Moved PDN WiFi to CM3
- Moved HDMI_LS_OE to IO3 of IO Expander

- Changed value of R259,R264,C218,C219,C222,C224,C227,C228,C229,C230

- Removed protection networks of HAT connector (DS11,DS12,DS13,DS14,DS15,DS16,
- Changed value of F3, J18
- Removed FTDI and relative components
- Added digital switch for USART to SWD communication from CM3 to Artik
- Removed I2C connections to mPCIE
- Added led RGB PWM control
- Added POE feature
- Added switch for DSI e CSI interface
- Added switch for I2C (PCM) for DSI/CSI connector
- Removed I2C from Artik IO Connector Expander

- Replace LAN9514 with industrial version
- Replace RJ45 connector with temperature extended version
- Added power supply from debug USB
- Added R311 for reset MCU
- Change to mount USB strip connector

Test Point SPEA

Designer Designer Designer G.Boschini G.Boschini G.Boschini | Approved Approved Approved

Project Code Project Code Project Code 2017-3009 2017-3009 2017-3009 | Customer Customer Customer BALENA.IO BALENA.IO BALENA.IO

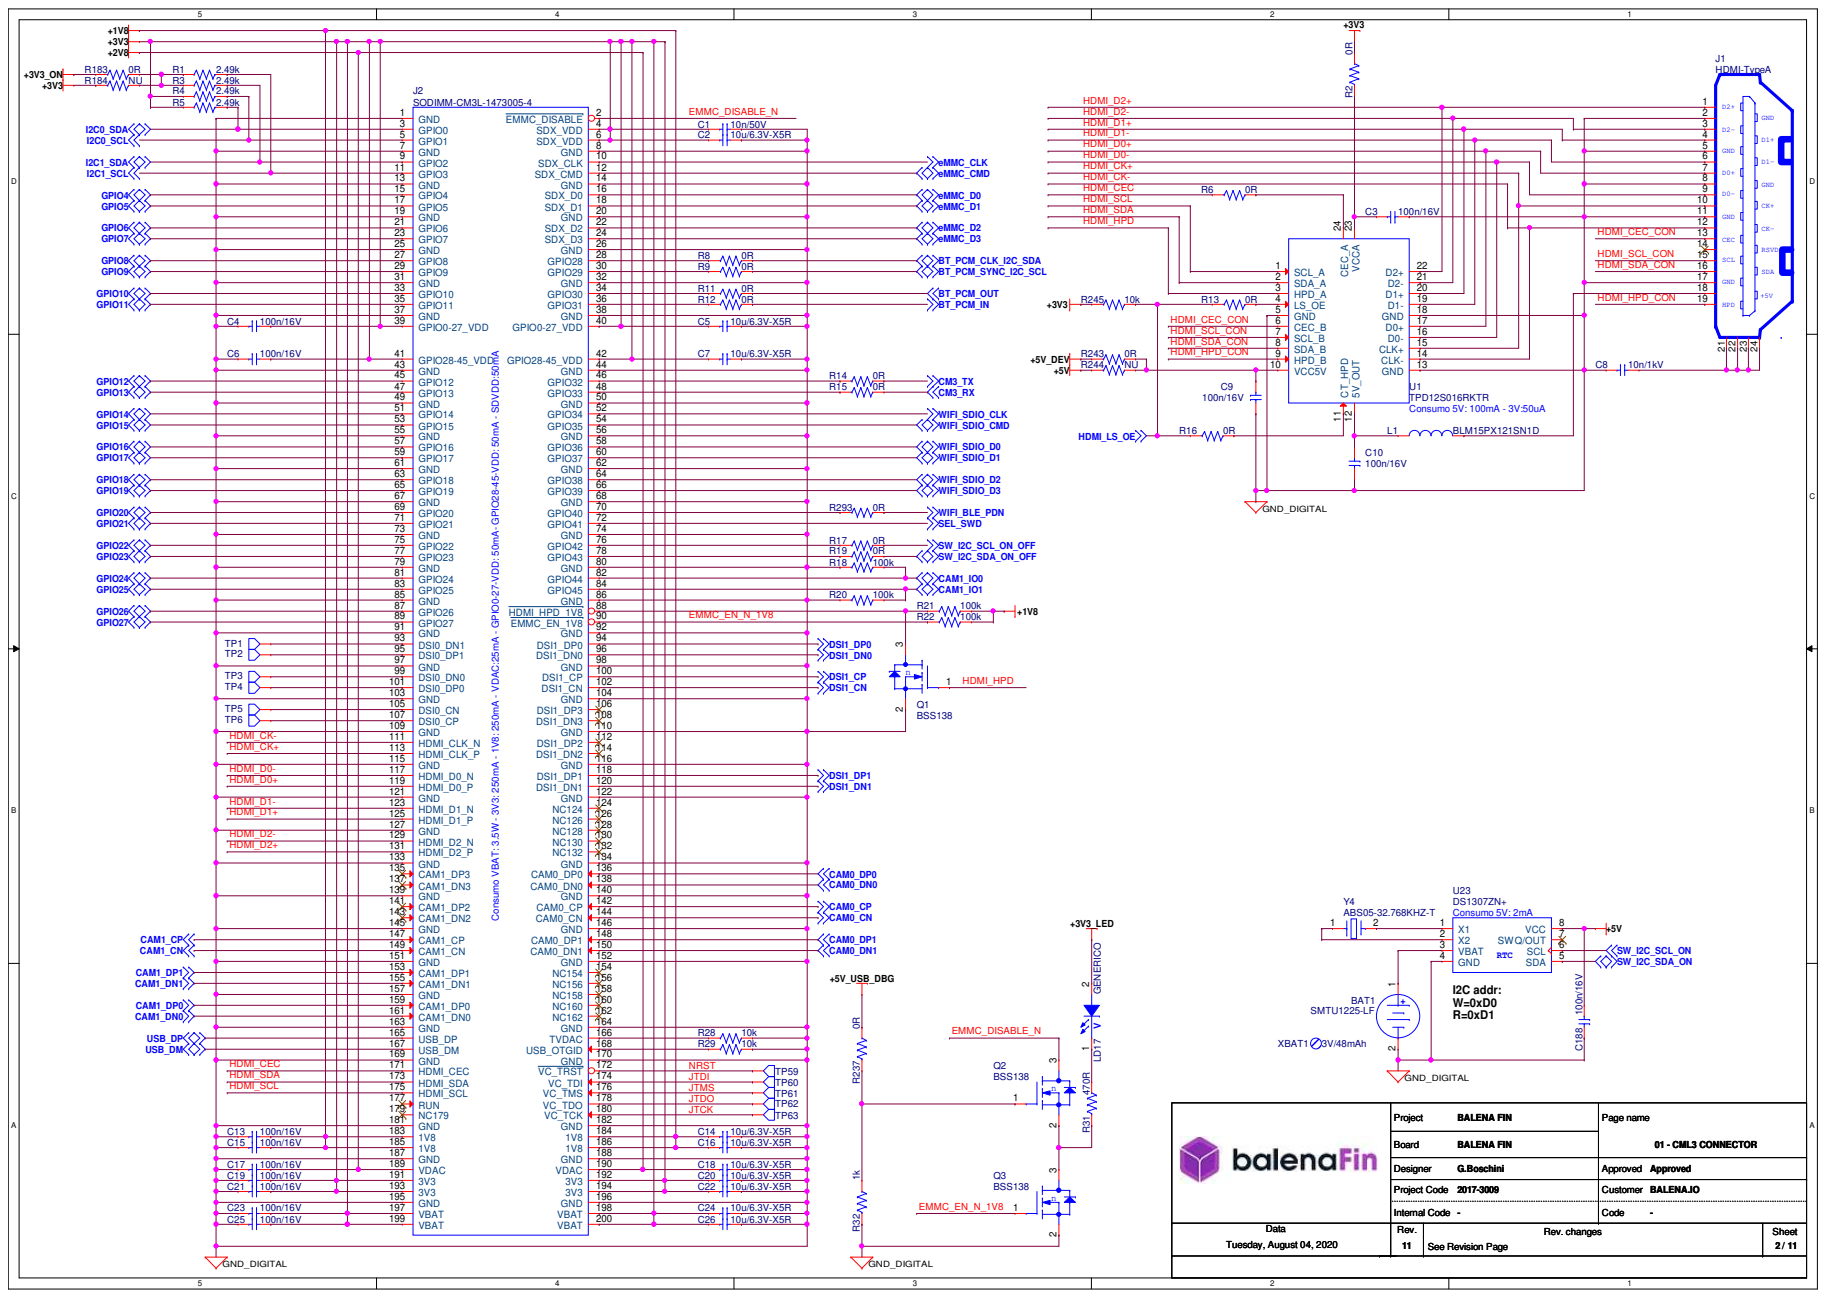
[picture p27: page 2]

11
12

HDMI_CEC_CON 13

Consumo VBAT: 3.5W - 3V3: 250mA - 1V8: 250mA - VDAC:25mA - GPIO0-27-VDD: 50mA- GPIO28-45-VDD: 50mA - SDVDD:50mA

Designer Designer Designer G.Boschini G.Boschini G.Boschini | Approved Approved Approved

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

Internal Code Internal Code Internal Code --- | Code Code Code ---
Rev. Rev. Rev. 11 11 11 | Rev. changes Rev. changes Rev. changes See Revision Page See Revision Page See Revision Page | Sheet Sheet Sheet / / / 112 112 112

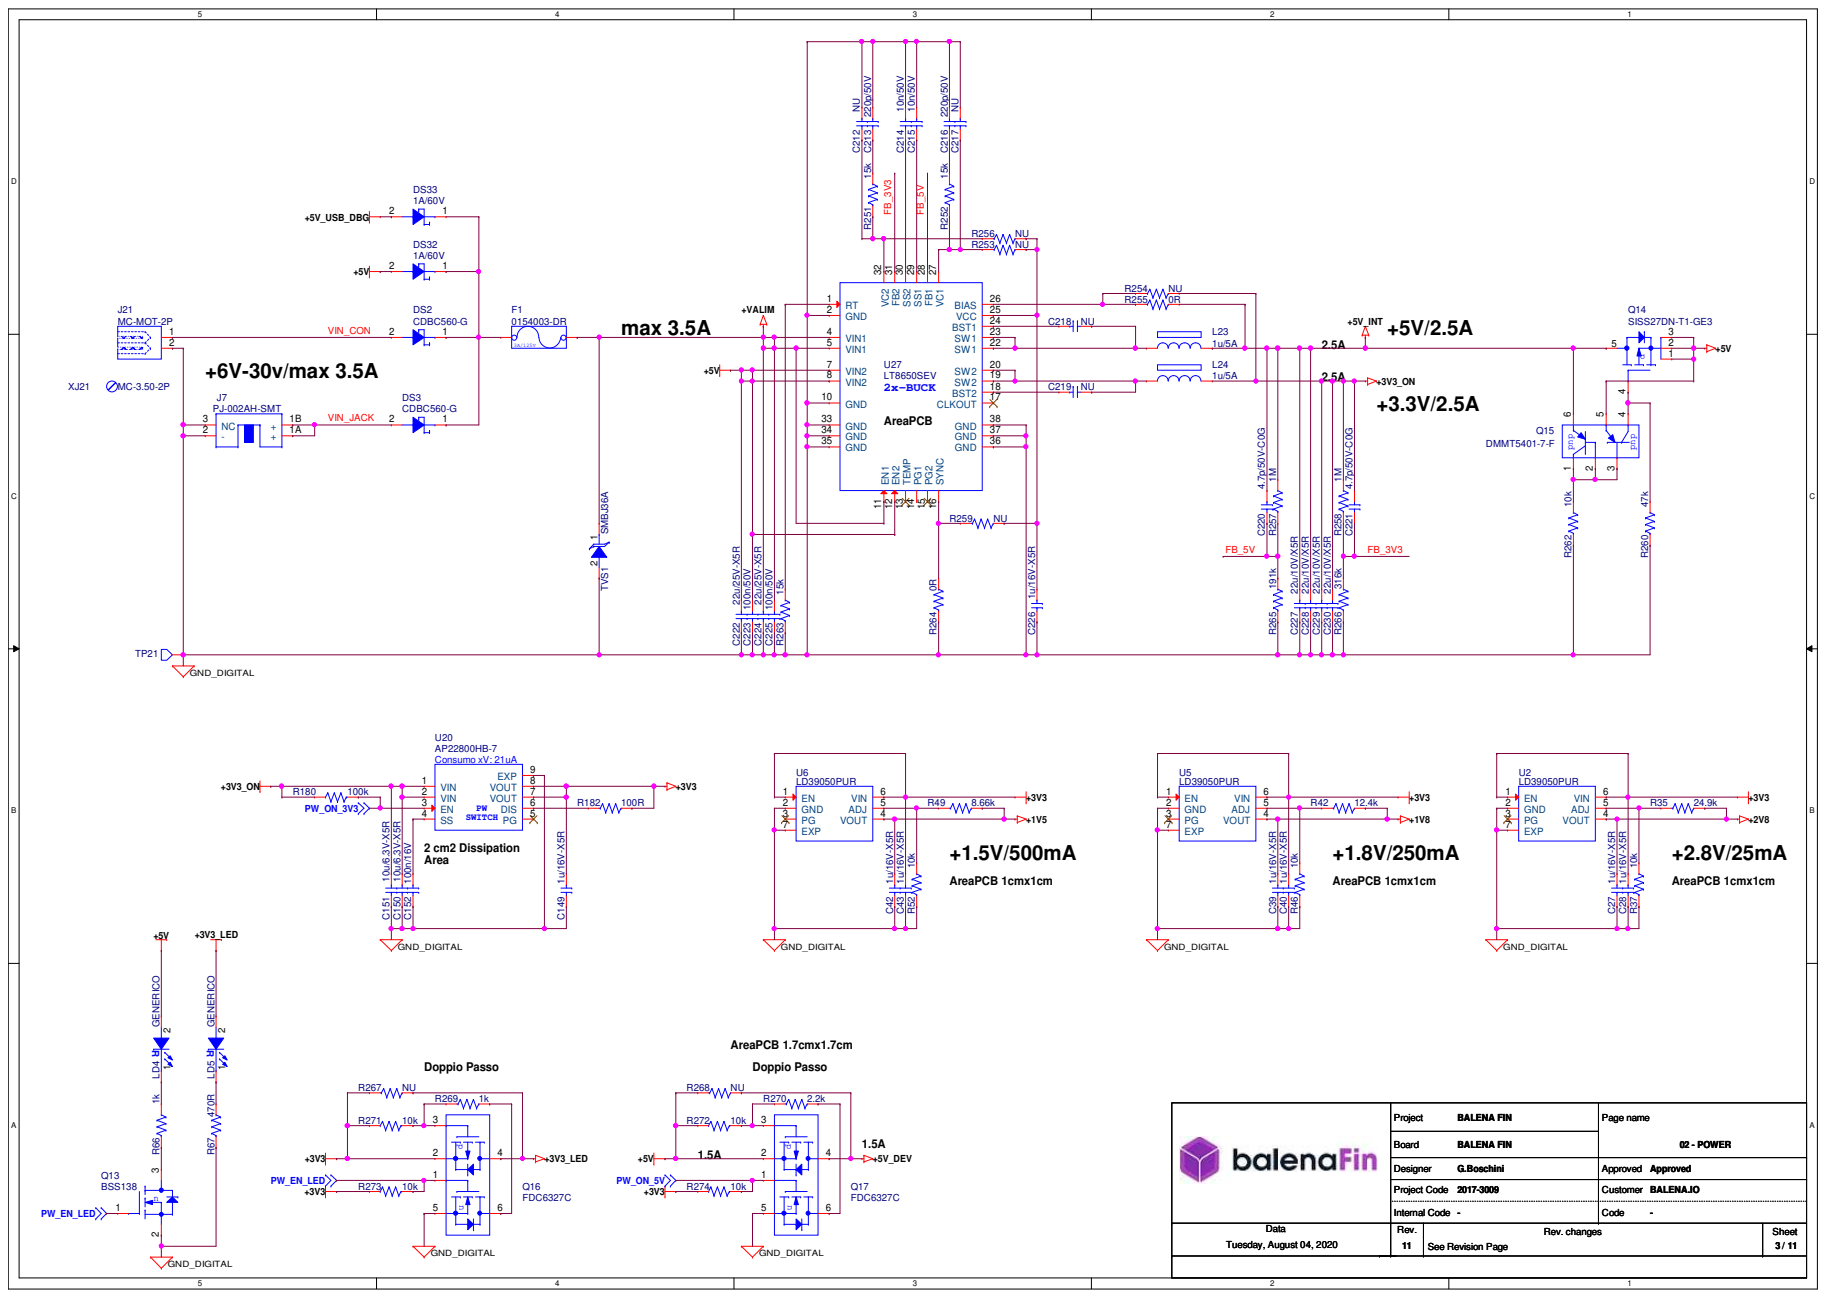
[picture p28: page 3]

GND 10

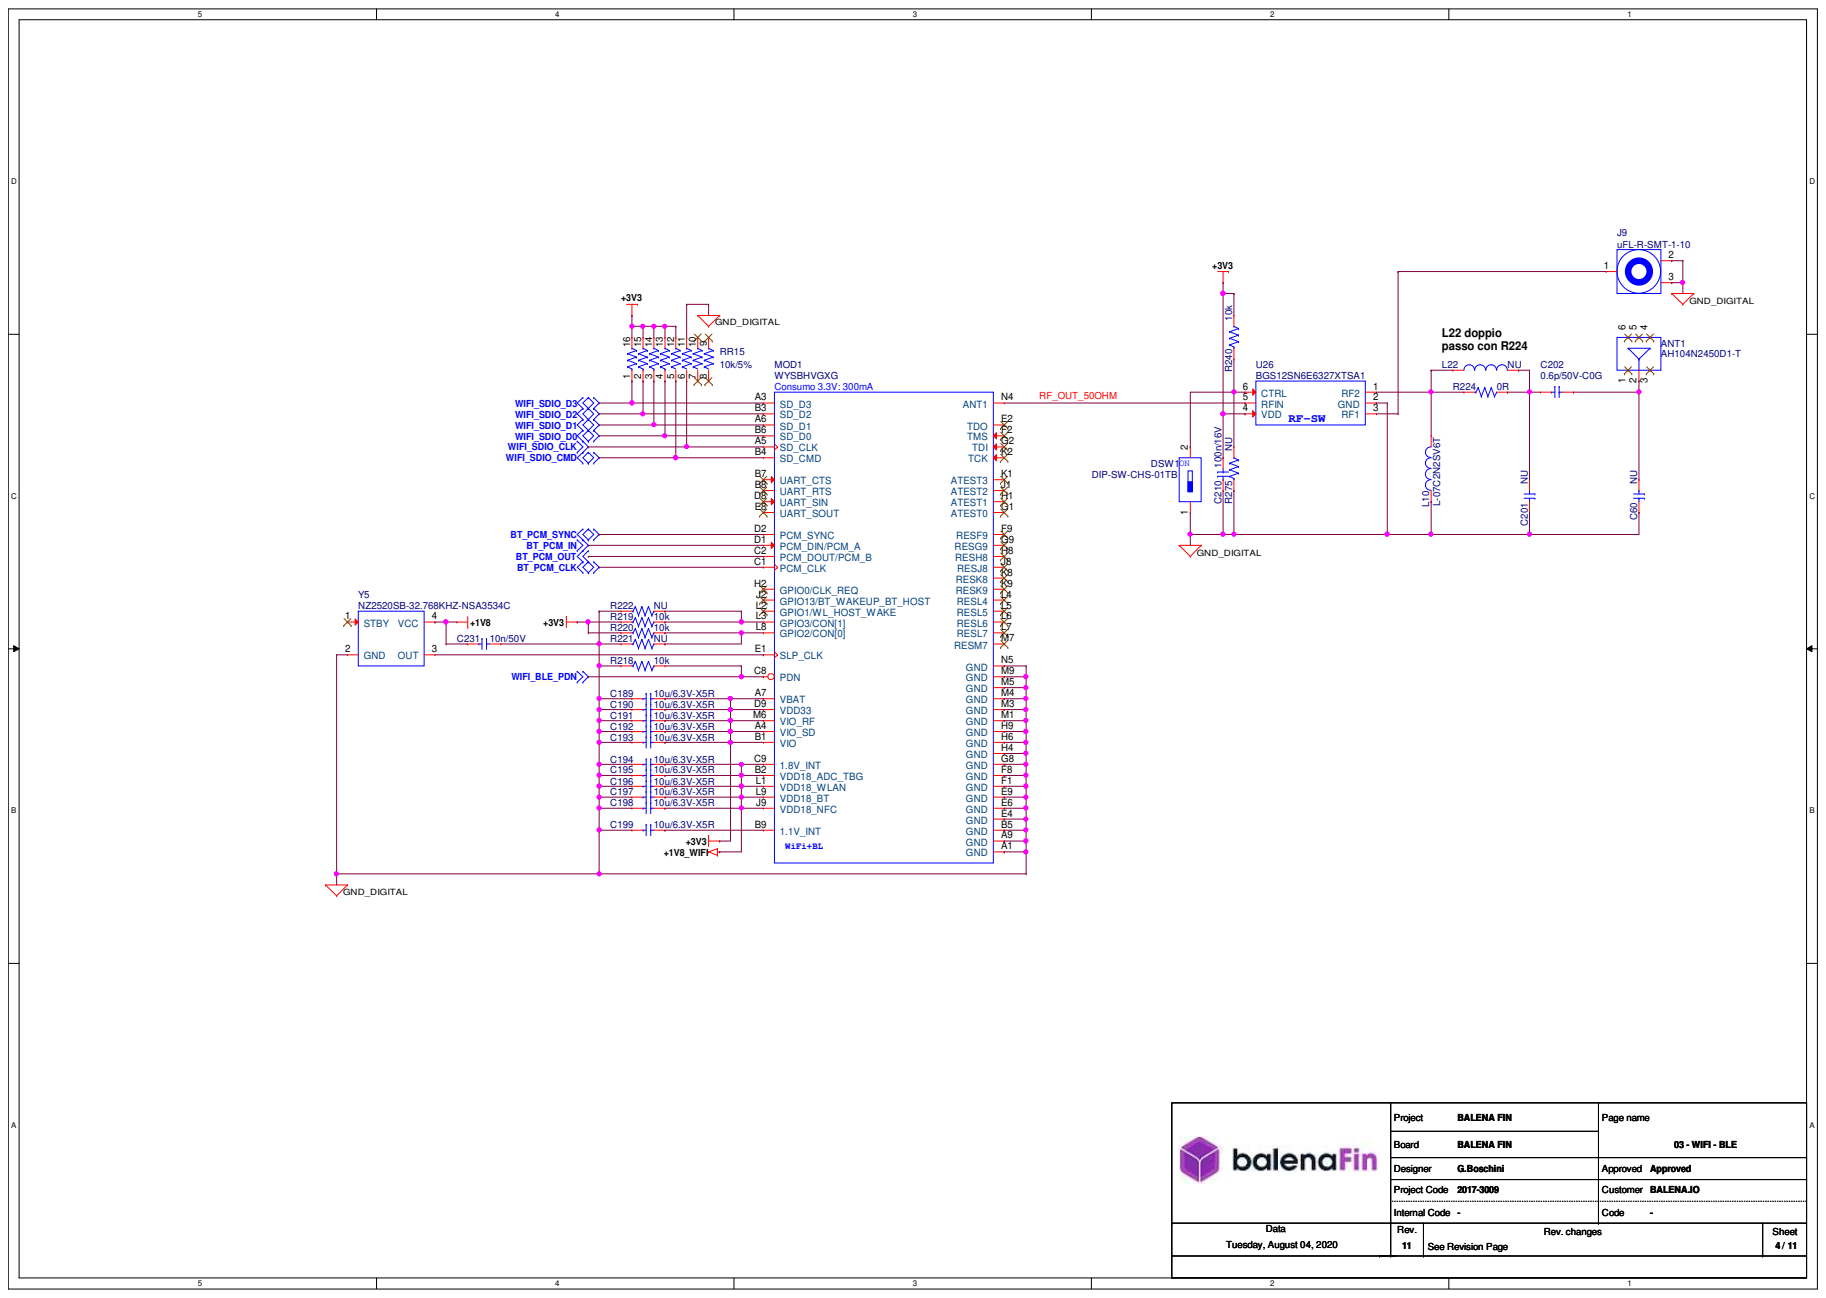
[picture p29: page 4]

Designer Designer Designer G.Boschini G.Boschini G.Boschini | Approved Approved Approved

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

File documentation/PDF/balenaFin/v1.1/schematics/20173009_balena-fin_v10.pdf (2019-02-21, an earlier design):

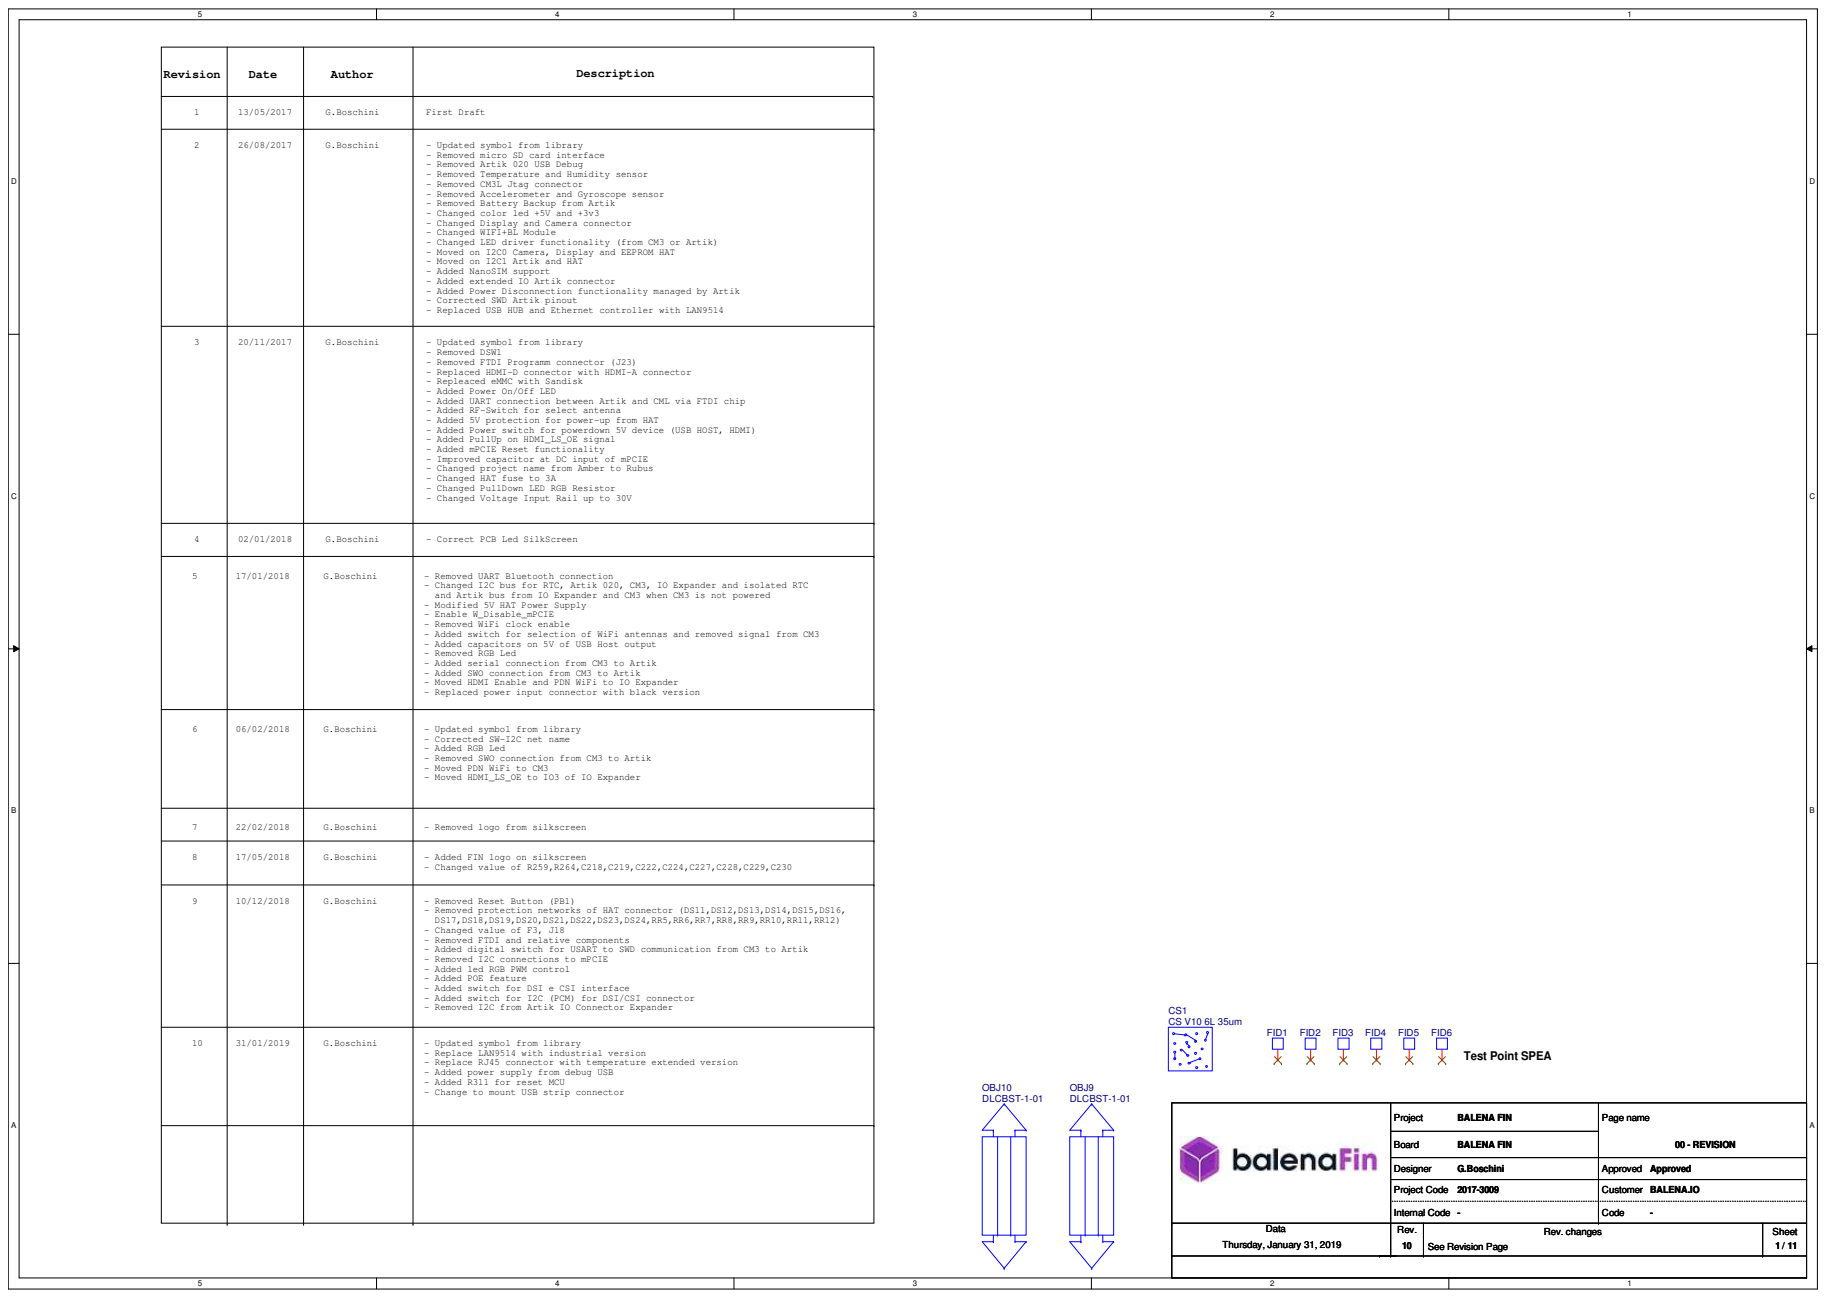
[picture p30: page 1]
Revision; Date; Author; Description; G.Boschini; First Draft; 2 G.Boschini 26/08/2017; - Updated symbol from library G.Boschini; G.Boschini 02/01/2018; - Correct PCB Led SilkScreen; - Removed UART Bluetooth connection G.Boschini; G.Boschini 06/02/2018; - Updated symbol from library; - Removed logo from silkscreen G.Boschini; - Removed Reset Button (PB1); 9 G.Boschini; - Added FIN logo on silkscreen; 8 G.Boschini; Rev.; Rev. changes; Sheet; Board; Project; Code; Page name; Data; Internal Code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

- Updated symbol from library
- Removed micro SD card interface
- Removed Artik 020 USB Debug
- Removed Temperature and Humidity sensor
- Removed CM3L Jtag connector
- Removed Accelerometer and Gyroscope sensor
- Removed Battery Backup from Artik
- Changed color led +5V and +3v3
- Changed Display and Camera connector
- Changed WIFI+BL Module
- Changed LED driver functionality (from CM3 or Artik)
- Moved on I2C0 Camera, Display and EEPROM HAT
- Moved on I2C1 Artik and HAT
- Added NanoSIM support
- Added extended IO Artik connector
- Added Power Disconnection functionality managed by Artik
- Corrected SWD Artik pinout
- Replaced USB HUB and Ethernet controller with LAN9514

- Removed DSW1
- Removed FTDI Programm connector (J23)
- Replaced HDMI-D connector with HDMI-A connector
- Repleaced eMMC with Sandisk
- Added Power On/Off LED
- Added UART connection between Artik and CML via FTDI chip
- Added RF-Switch for select antenna
- Added 5V protection for power-up from HAT
- Added Power switch for powerdown 5V device (USB HOST, HDMI)
- Added PullUp on HDMI_LS_OE signal
- Added mPCIE Reset functionality
- Improved capacitor at DC input of mPCIE
- Changed project name from Amber to Rubus
- Changed HAT fuse to 3A
- Changed PullDown LED RGB Resistor
- Changed Voltage Input Rail up to 30V

- Changed I2C bus for RTC, Artik 020, CM3, IO Expander and isolated RTC
and Artik bus from IO Expander and CM3 when CM3 is not powered
- Modified 5V HAT Power Supply
- Enable W_Disable_mPCIE
- Removed WiFi clock enable
- Added switch for selection of WiFi antennas and removed signal from CM3
- Added capacitors on 5V of USB Host output
- Removed RGB Led
- Added serial connection from CM3 to Artik
- Added SWO connection from CM3 to Artik
- Moved HDMI Enable and PDN WiFi to IO Expander
- Replaced power input connector with black version

- Corrected SW-I2C net name
- Added RGB Led
- Removed SWO connection from CM3 to Artik
- Moved PDN WiFi to CM3
- Moved HDMI_LS_OE to IO3 of IO Expander

- Changed value of R259,R264,C218,C219,C222,C224,C227,C228,C229,C230

- Removed protection networks of HAT connector (DS11,DS12,DS13,DS14,DS15,DS16,
- Changed value of F3, J18
- Removed FTDI and relative components
- Added digital switch for USART to SWD communication from CM3 to Artik
- Removed I2C connections to mPCIE
- Added led RGB PWM control
- Added POE feature
- Added switch for DSI e CSI interface
- Added switch for I2C (PCM) for DSI/CSI connector
- Removed I2C from Artik IO Connector Expander

- Replace LAN9514 with industrial version
- Replace RJ45 connector with temperature extended version
- Added power supply from debug USB
- Added R311 for reset MCU
- Change to mount USB strip connector

Test Point SPEA

Designer Designer Designer G.Boschini G.Boschini G.Boschini | Approved Approved Approved

Project Code Project Code Project Code 2017-3009 2017-3009 2017-3009 | Customer Customer Customer BALENA.IO BALENA.IO BALENA.IO

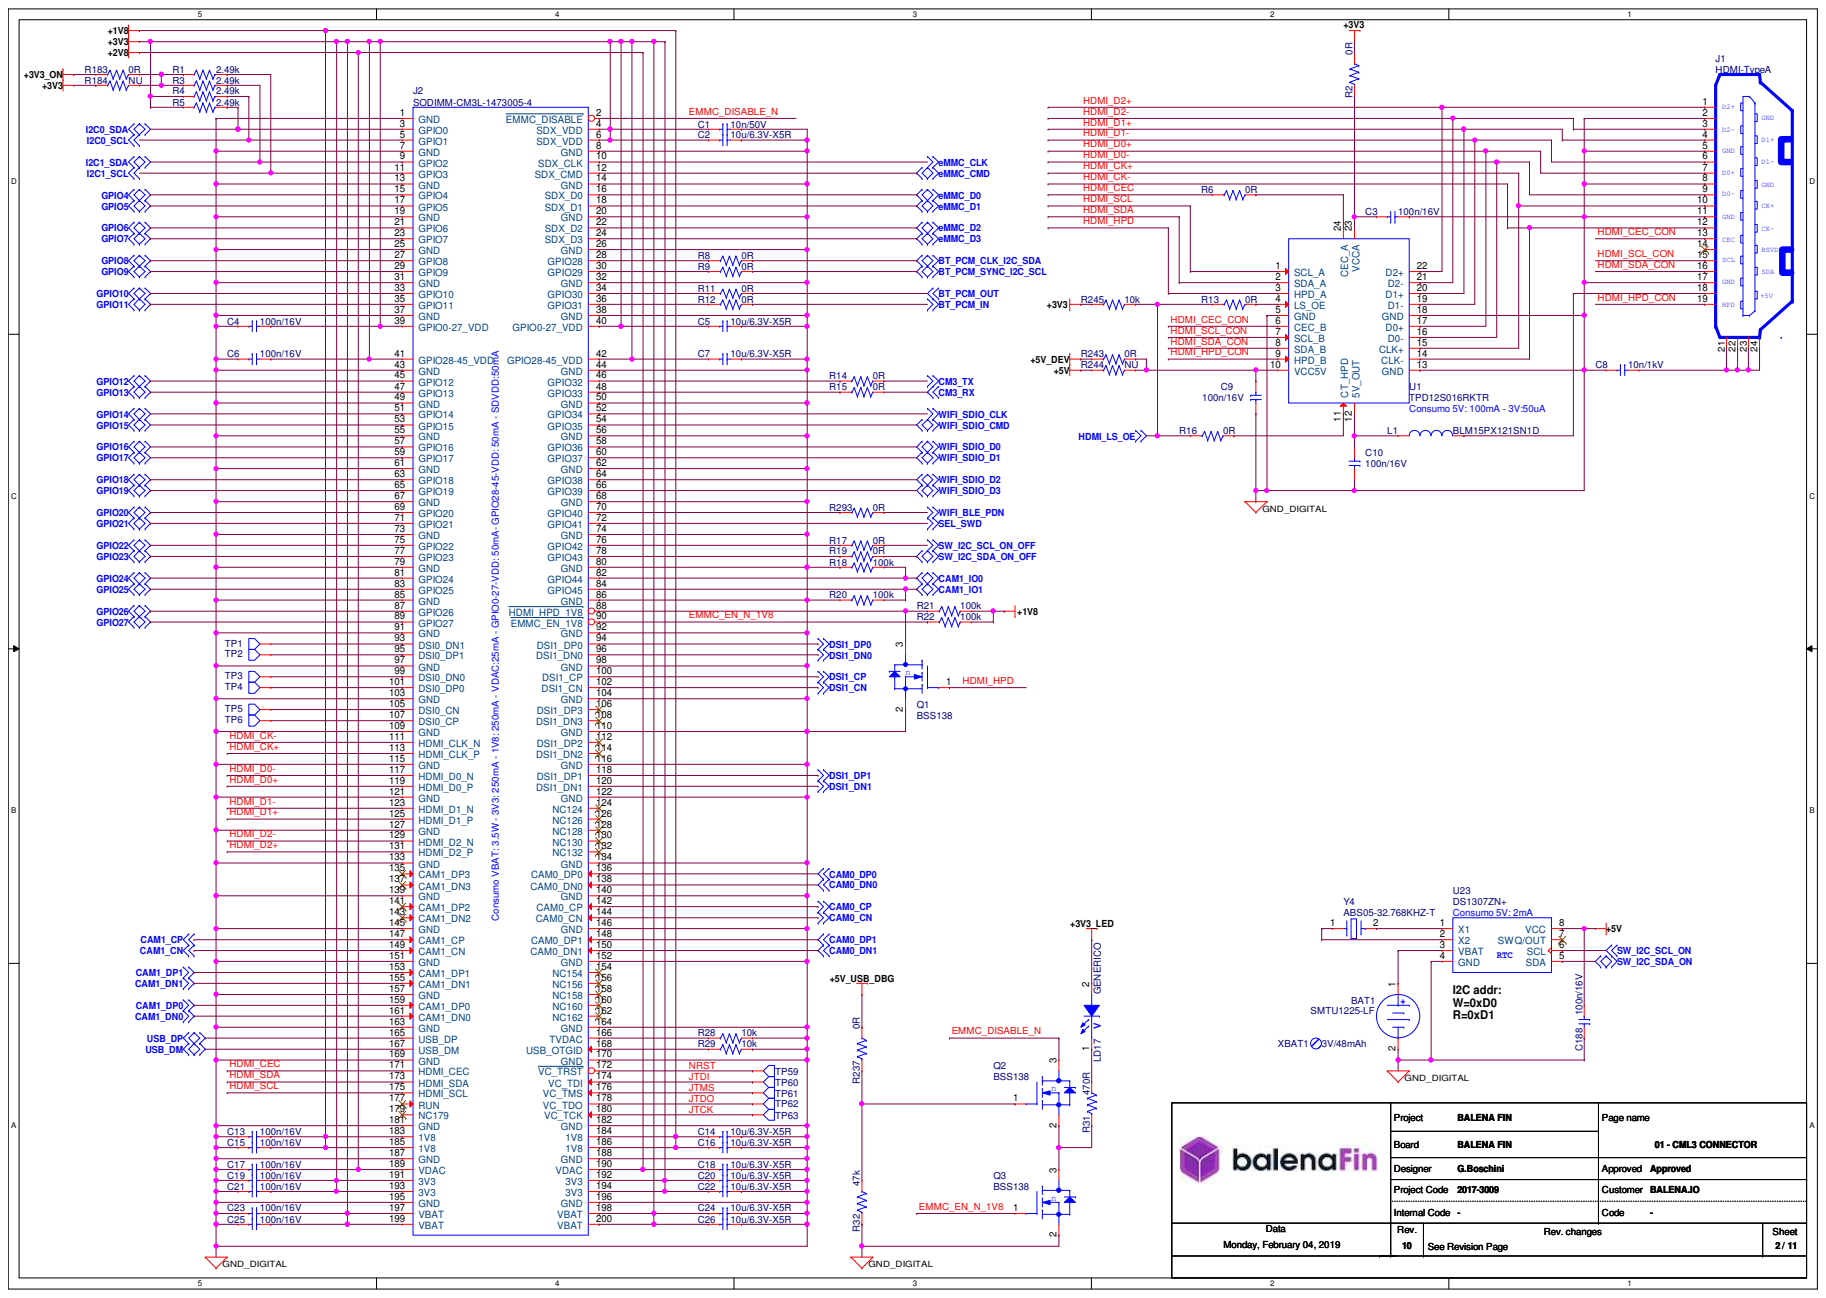
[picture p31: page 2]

11
12

HDMI_CEC_CON 13

Consumo VBAT: 3.5W - 3V3: 250mA - 1V8: 250mA - VDAC:25mA - GPIO0-27-VDD: 50mA- GPIO28-45-VDD: 50mA - SDVDD:50mA

Designer Designer Designer G.Boschini G.Boschini G.Boschini | Approved Approved Approved

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

Internal Code Internal Code Internal Code --- | Code Code Code ---
Rev. Rev. Rev. 10 10 10 | Rev. changes Rev. changes Rev. changes See Revision Page See Revision Page See Revision Page | Sheet Sheet Sheet / / / 112 112 112

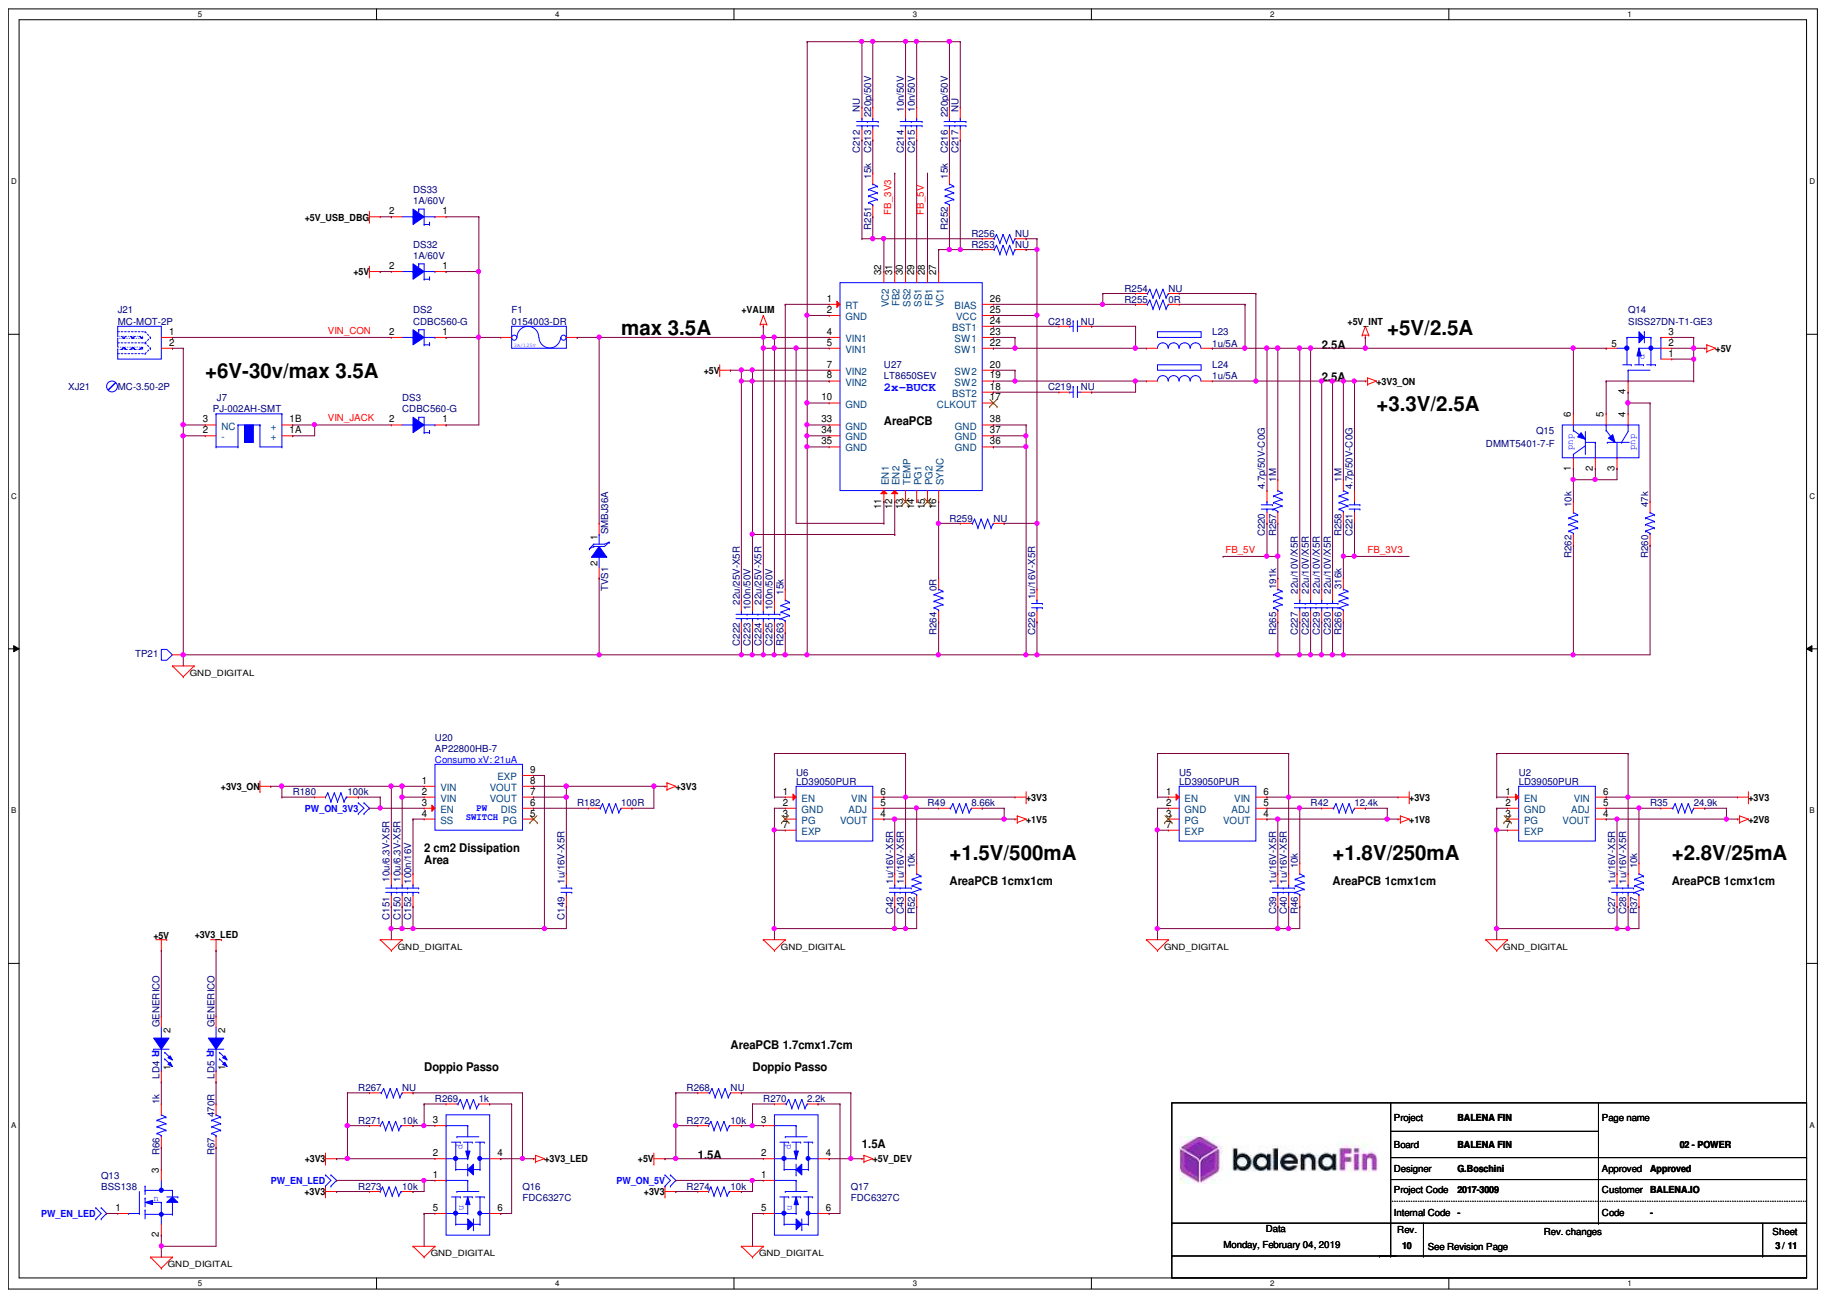
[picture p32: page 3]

GND 10

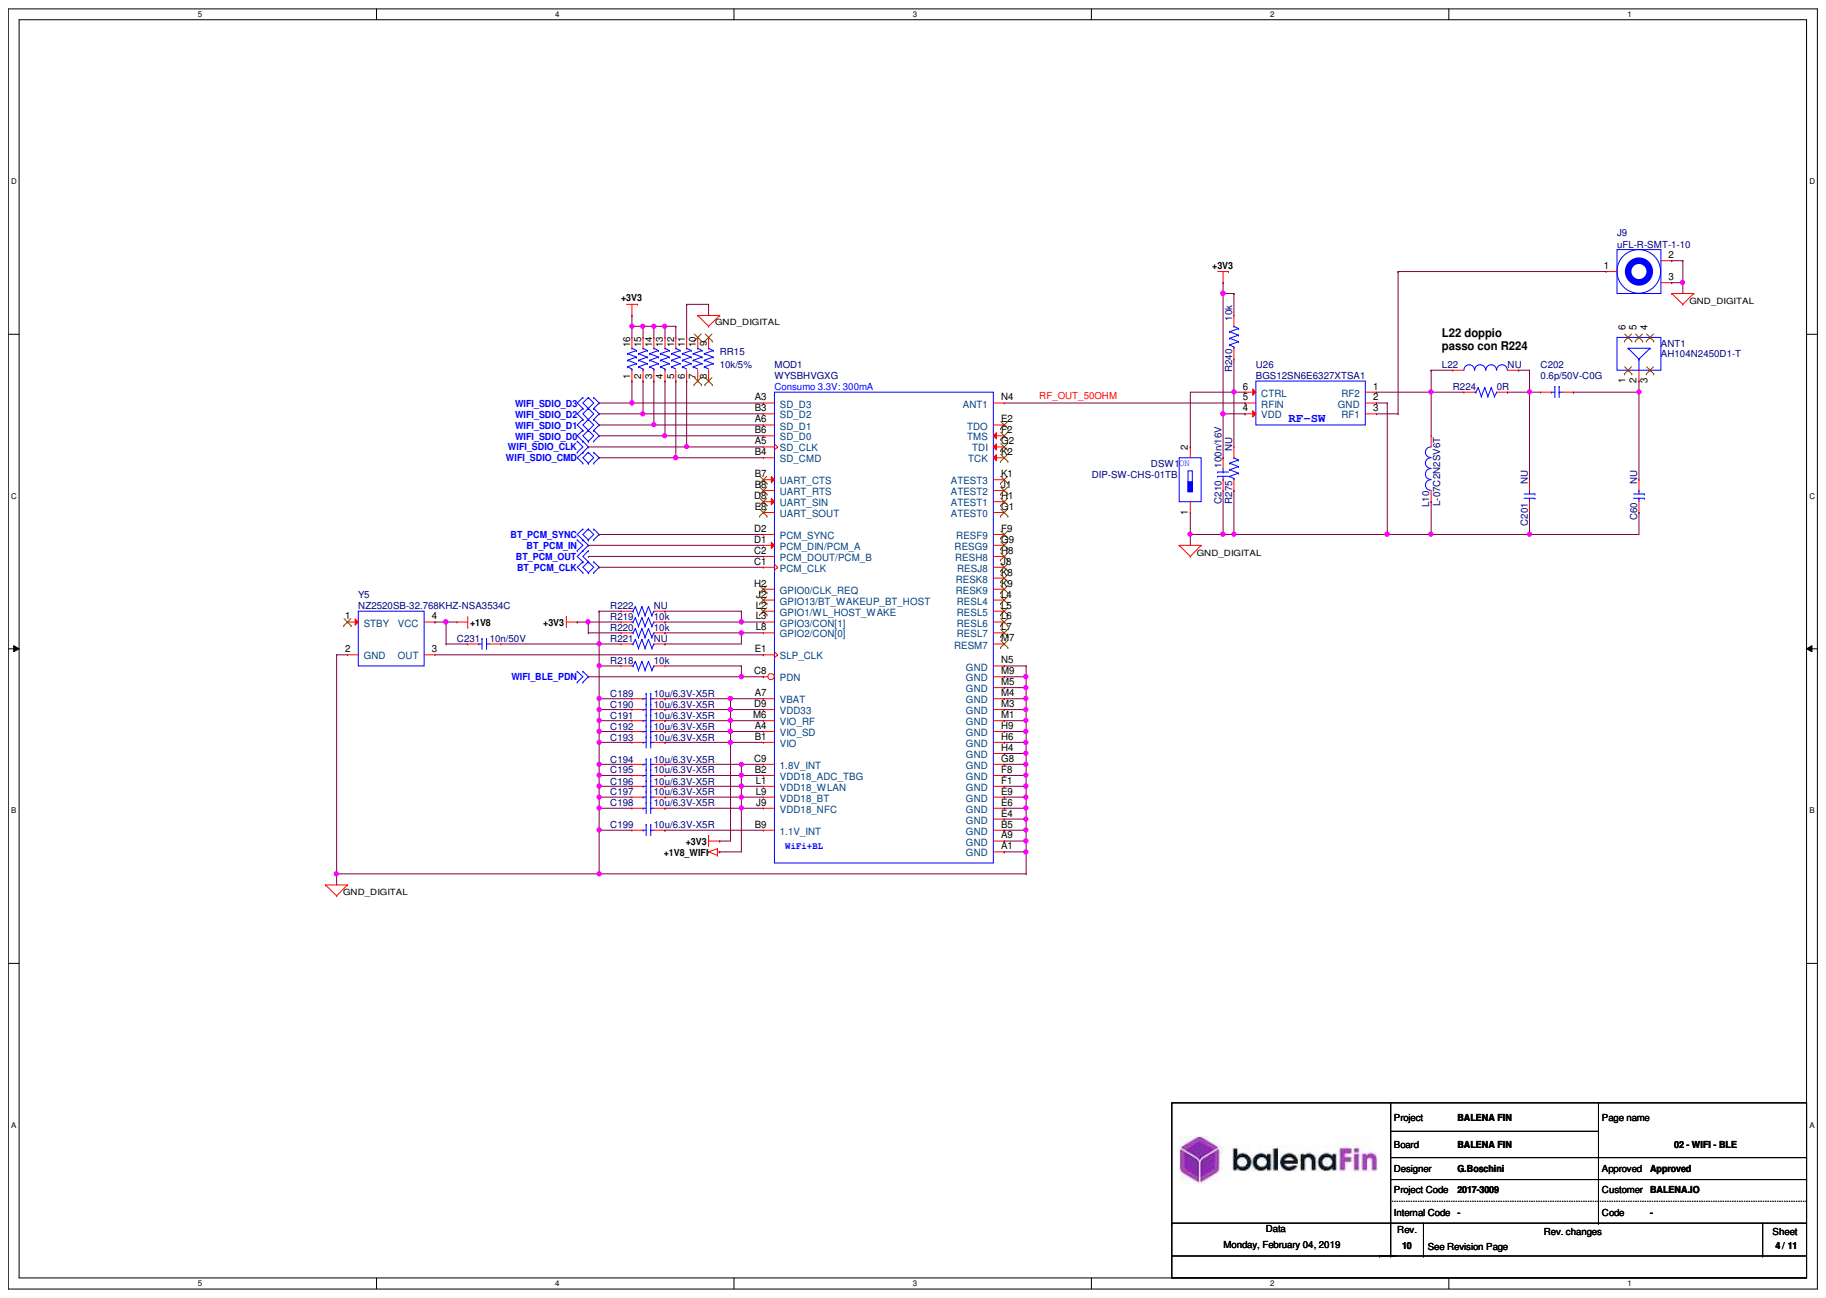
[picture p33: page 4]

Designer Designer Designer G.Boschini G.Boschini G.Boschini | Approved Approved Approved

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

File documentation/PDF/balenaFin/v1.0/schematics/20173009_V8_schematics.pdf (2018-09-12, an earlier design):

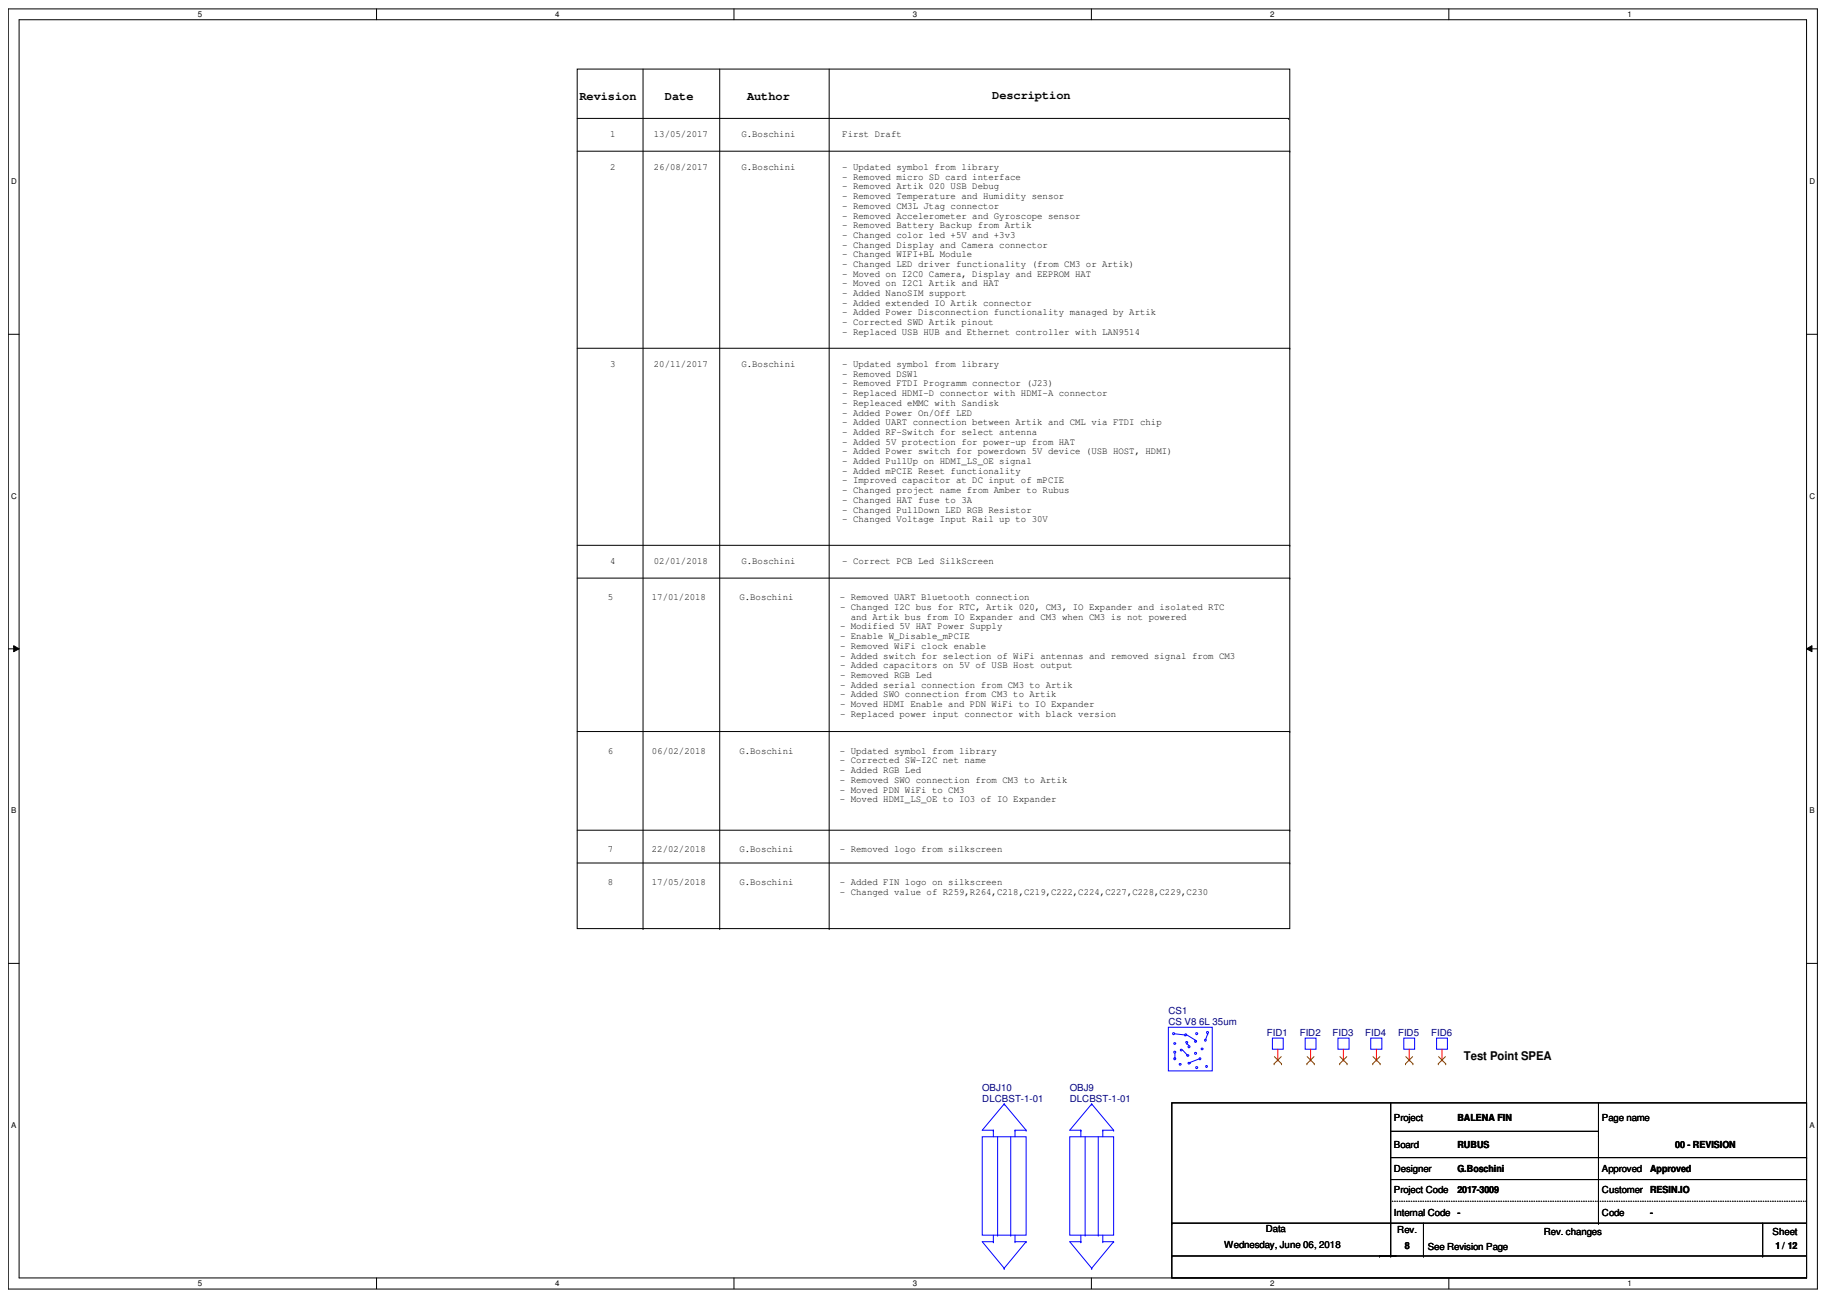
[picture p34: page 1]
Revision; Date; Author; Description; G.Boschini; First Draft; 2 G.Boschini 26/08/2017; - Updated symbol from library G.Boschini; G.Boschini 02/01/2018; - Correct PCB Led SilkScreen; - Removed UART Bluetooth connection G.Boschini; G.Boschini 06/02/2018; - Updated symbol from library; - Removed logo from silkscreen G.Boschini; - Added FIN logo on silkscreen; 8 G.Boschini; Rev.; Rev. changes; Sheet; Board; Project; Code; Page name; Data; Internal Code; Wednesday, June 06, 2018; RUBUS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

- Updated symbol from library
- Removed micro SD card interface
- Removed Artik 020 USB Debug
- Removed Temperature and Humidity sensor
- Removed CM3L Jtag connector
- Removed Accelerometer and Gyroscope sensor
- Removed Battery Backup from Artik
- Changed color led +5V and +3v3
- Changed Display and Camera connector
- Changed WIFI+BL Module
- Changed LED driver functionality (from CM3 or Artik)
- Moved on I2C0 Camera, Display and EEPROM HAT
- Moved on I2C1 Artik and HAT
- Added NanoSIM support
- Added extended IO Artik connector
- Added Power Disconnection functionality managed by Artik
- Corrected SWD Artik pinout
- Replaced USB HUB and Ethernet controller with LAN9514

- Removed DSW1
- Removed FTDI Programm connector (J23)
- Replaced HDMI-D connector with HDMI-A connector
- Repleaced eMMC with Sandisk
- Added Power On/Off LED
- Added UART connection between Artik and CML via FTDI chip
- Added RF-Switch for select antenna
- Added 5V protection for power-up from HAT
- Added Power switch for powerdown 5V device (USB HOST, HDMI)
- Added PullUp on HDMI_LS_OE signal
- Added mPCIE Reset functionality
- Improved capacitor at DC input of mPCIE
- Changed project name from Amber to Rubus
- Changed HAT fuse to 3A
- Changed PullDown LED RGB Resistor
- Changed Voltage Input Rail up to 30V

- Changed I2C bus for RTC, Artik 020, CM3, IO Expander and isolated RTC
and Artik bus from IO Expander and CM3 when CM3 is not powered
- Modified 5V HAT Power Supply
- Enable W_Disable_mPCIE
- Removed WiFi clock enable
- Added switch for selection of WiFi antennas and removed signal from CM3
- Added capacitors on 5V of USB Host output
- Removed RGB Led
- Added serial connection from CM3 to Artik
- Added SWO connection from CM3 to Artik
- Moved HDMI Enable and PDN WiFi to IO Expander
- Replaced power input connector with black version

- Corrected SW-I2C net name
- Added RGB Led
- Removed SWO connection from CM3 to Artik
- Moved PDN WiFi to CM3
- Moved HDMI_LS_OE to IO3 of IO Expander

- Changed value of R259,R264,C218,C219,C222,C224,C227,C228,C229,C230

Test Point SPEA

Designer Designer Designer G.Boschini G.Boschini G.Boschini | Approved Approved Approved

Project Code Project Code Project Code 2017-3009 2017-3009 2017-3009 | Customer Customer Customer RESIN.IO RESIN.IO RESIN.IO

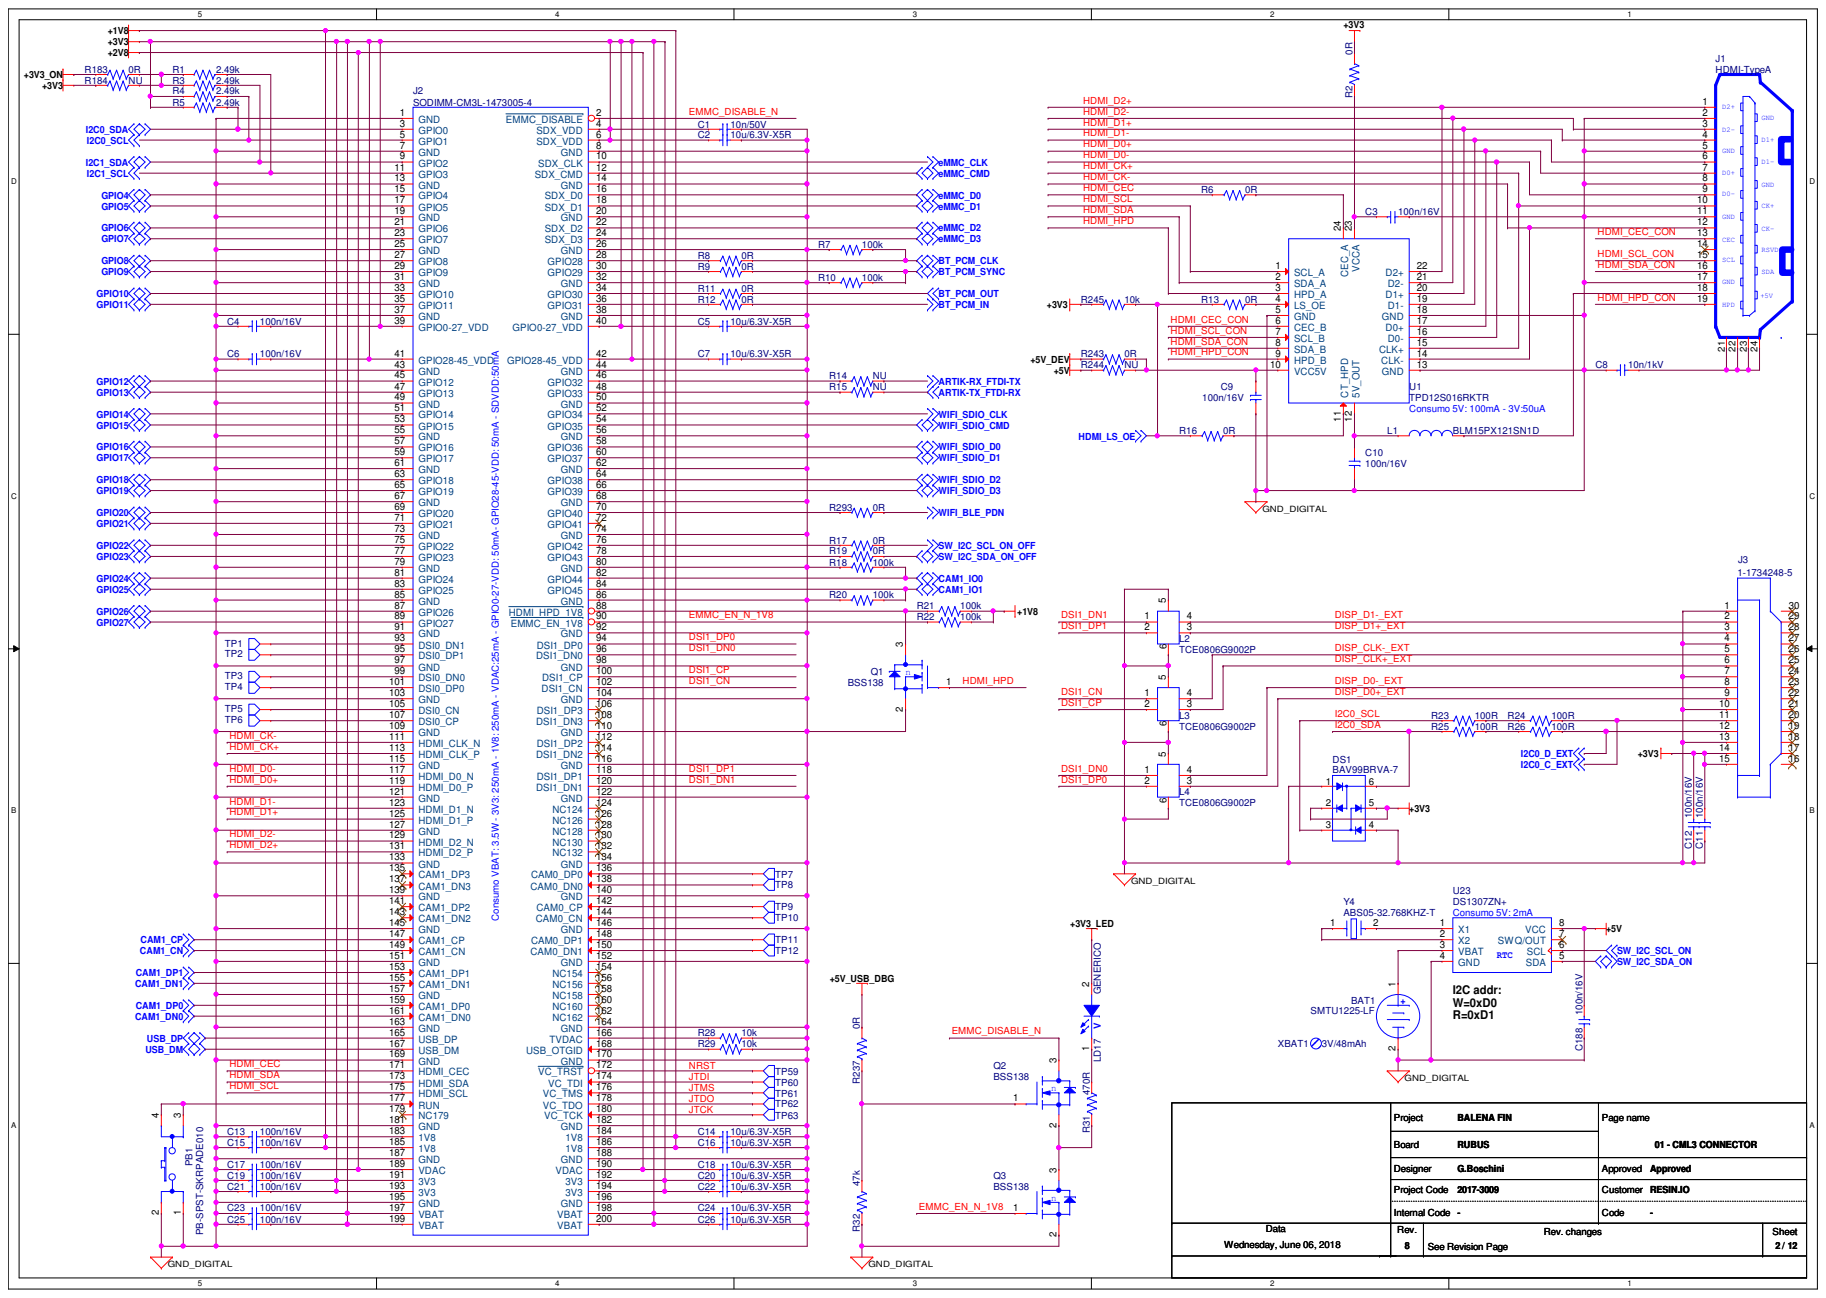
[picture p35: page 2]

11
12

HDMI_CEC_CON 13

Consumo VBAT: 3.5W - 3V3: 250mA - 1V8: 250mA - VDAC:25mA - GPIO0-27-VDD: 50mA- GPIO28-45-VDD: 50mA - SDVDD:50mA

Designer Designer Designer G.Boschini G.Boschini G.Boschini | Approved Approved Approved

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

Internal Code Internal Code Internal Code --- | Code Code Code ---
Rev. Rev. Rev. 8 8 8 | Rev. changes Rev. changes Rev. changes See Revision Page See Revision Page See Revision Page | Sheet Sheet Sheet / / / 122 122 122

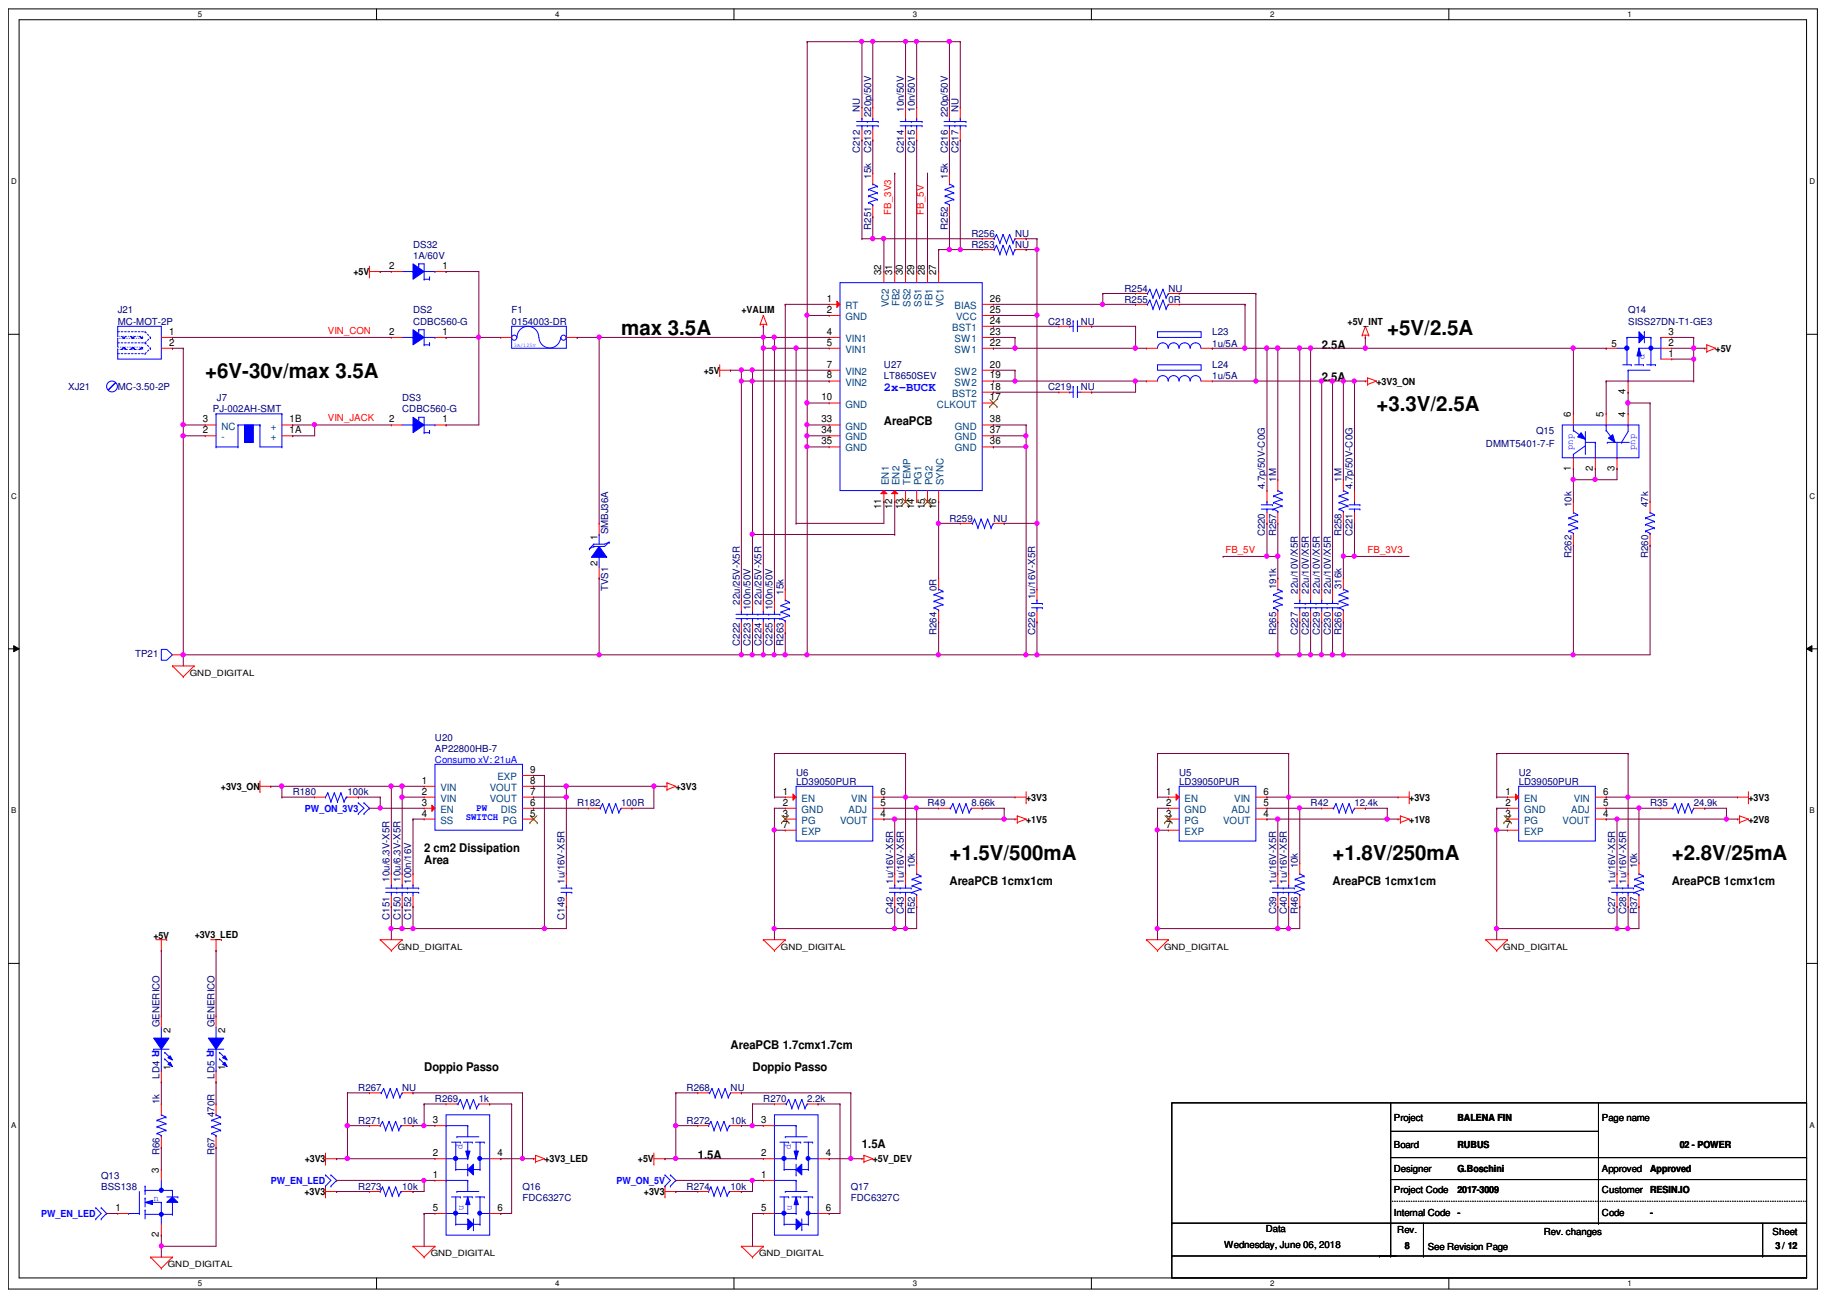
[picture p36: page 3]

GND 10

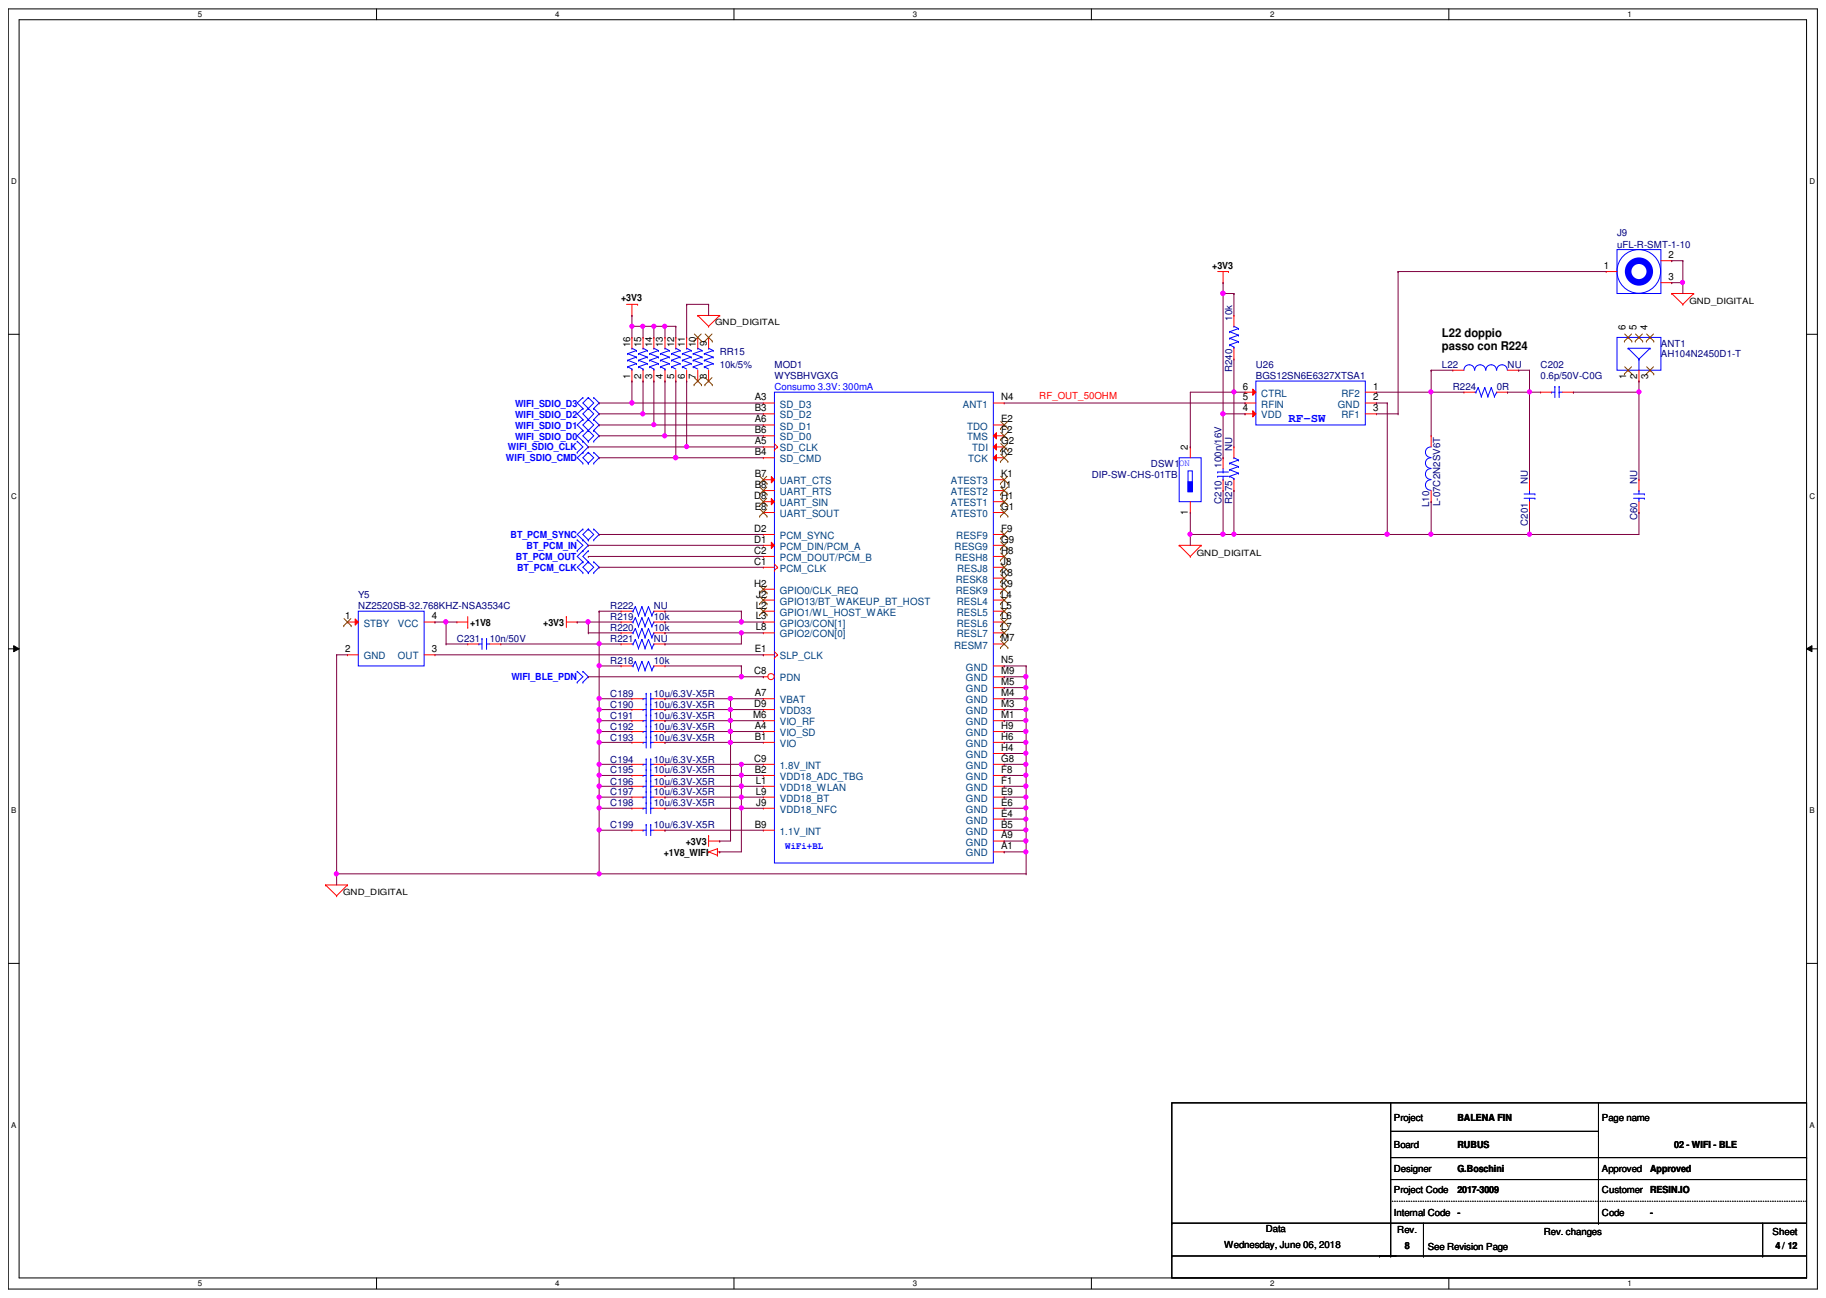
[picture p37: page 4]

Designer Designer Designer G.Boschini G.Boschini G.Boschini | Approved Approved Approved

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


12 | CAM1_IO1_EXT
13 | CAM1_SCL_EXT

Designer Designer Designer G.Boschini G.Boschini G.Boschini | Approved Approved Approved

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

Internal Code Internal Code Internal Code --- | Code Code Code ---


VCC 1

D+_DBG | D+ 3

Designer Designer Designer G.Boschini G.Boschini G.Boschini | Approved Approved Approved

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

Internal Code Internal Code Internal Code --- | Code Code Code ---

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

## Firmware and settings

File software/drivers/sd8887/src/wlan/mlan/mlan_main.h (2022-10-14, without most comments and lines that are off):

#define _MLAN_MAIN_H_
#ifdef DEBUG_LEVEL1
extern t_void (*print_callback) (IN t_void *pmoal_handle,
				 IN t_u32 level, IN char *pformat, IN ...
	);
extern mlan_status (*get_sys_time_callback) (IN t_void *pmoal_handle,
					     OUT t_u32 *psec, OUT t_u32 *pusec);
extern t_u32 mlan_drvdbg;
#ifdef	DEBUG_LEVEL2
#define	PRINTM_MINFO(msg...) do { \
	if ((mlan_drvdbg & MINFO) && (print_callback)) \
		print_callback(MNULL, MINFO, msg); \
	} while (0)
#define	PRINTM_MWARN(msg...)  do { \
	if ((mlan_drvdbg & MWARN) && (print_callback)) \
		print_callback(MNULL, MWARN, msg); \
	} while (0)
#define	PRINTM_MENTRY(msg...) do { \
	if ((mlan_drvdbg & MENTRY) && (print_callback)) \
		print_callback(MNULL, MENTRY, msg); \
} while (0)
#define PRINTM_GET_SYS_TIME(level, psec, pusec)              \
do {                                                         \
	if ((level & mlan_drvdbg) && (get_sys_time_callback))\
	    get_sys_time_callback(MNULL, psec, pusec);       \
} while (0)
#define HEXDUMP(x, y, z)   \
do {                \
	if ((mlan_drvdbg & (MHEX_DUMP | MINFO)) && (print_callback))  \
	    print_callback(MNULL, MHEX_DUMP | MINFO, x, y, z); \
} while (0)
#else
#define	PRINTM_MINFO(msg...)  do {} while (0)
#define	PRINTM_MWARN(msg...)  do {} while (0)
#define	PRINTM_MENTRY(msg...) do {} while (0)
#define PRINTM_GET_SYS_TIME(level, psec, pusec)         \
do {                                                    \
	if ((level & mlan_drvdbg) && (get_sys_time_callback)     \
			&& (level != MINFO) && (level != MWARN))    \
	    get_sys_time_callback(MNULL, psec, pusec);      \
} while (0)
#define HEXDUMP(x, y, z) do {} while (0)
#endif
#define	PRINTM_MFW_D(msg...)  do { \
	if ((mlan_drvdbg & MFW_D) && (print_callback)) \
		print_callback(MNULL, MFW_D, msg); \
	} while (0)
#define	PRINTM_MCMD_D(msg...) do { \
	if ((mlan_drvdbg & MCMD_D) && (print_callback)) \
		print_callback(MNULL, MCMD_D, msg); \
	} while (0)
#define	PRINTM_MDAT_D(msg...) do { \
	if ((mlan_drvdbg & MDAT_D) && (print_callback)) \
		print_callback(MNULL, MDAT_D, msg); \
	} while (0)
#define	PRINTM_MIF_D(msg...) do { \
	if ((mlan_drvdbg & MIF_D) && (print_callback)) \
		print_callback(MNULL, MIF_D, msg); \
	} while (0)
#define	PRINTM_MIOCTL(msg...) do { \
	if ((mlan_drvdbg & MIOCTL) && (print_callback)) \
		print_callback(MNULL, MIOCTL, msg); \
	} while (0)
#define	PRINTM_MINTR(msg...)  do { \
	if ((mlan_drvdbg & MINTR) && (print_callback)) \
		print_callback(MNULL, MINTR, msg); \
	} while (0)
#define	PRINTM_MEVENT(msg...) do { \
	if ((mlan_drvdbg & MEVENT) && (print_callback)) \
		print_callback(MNULL, MEVENT, msg); \
	} while (0)
#define	PRINTM_MCMND(msg...)  do { \
	if ((mlan_drvdbg & MCMND) && (print_callback)) \
		print_callback(MNULL, MCMND, msg); \
	} while (0)
#define	PRINTM_MDATA(msg...)  do { \
	if ((mlan_drvdbg & MDATA) && (print_callback)) \
		print_callback(MNULL, MDATA, msg); \
	} while (0)
#define	PRINTM_MERROR(msg...) do { \
	if ((mlan_drvdbg & MERROR) && (print_callback)) \
		print_callback(MNULL, MERROR, msg); \
	} while (0)
#define	PRINTM_MFATAL(msg...) do { \
	if ((mlan_drvdbg & MFATAL) && (print_callback)) \
		print_callback(MNULL, MFATAL, msg); \
	} while (0)
#define	PRINTM_MMSG(msg...) do { \
	if ((mlan_drvdbg & MMSG) && (print_callback)) \
		print_callback(MNULL, MMSG, msg); \
	} while (0)
#define	PRINTM(level, msg...) PRINTM_##level((char *)msg)
#ifdef __GNUC__
#define PRINTM_NETINTF(level, pmpriv)   \
do {                                    \
	if ((mlan_drvdbg & level) && pmpriv      \
			&& pmpriv->adapter->callbacks.moal_print_netintf) \
	    pmpriv->adapter->callbacks.moal_print_netintf( \
		    pmpriv->adapter->pmoal_handle, \
		    pmpriv->bss_index, level); \
} while (0)
#endif
#define MAX_DATA_DUMP_LEN	64
#define DBG_HEXDUMP(level, x, y, z)   \
do {                \
	if ((mlan_drvdbg & level) && print_callback)  \
		print_callback(MNULL, MHEX_DUMP | level, x, y, z); \
} while (0)
#else
#define	PRINTM(level, msg...) do {} while (0)
#define PRINTM_NETINTF(level, pmpriv) do {} while (0)
#define DBG_HEXDUMP(level, x, y, z) do {} while (0)
#define HEXDUMP(x, y, z) do {} while (0)
#define PRINTM_GET_SYS_TIME(level, psec, pusec) do { } while (0)
#endif
#define DEF_DEAUTH_REASON_CODE (0x3)
#define ENTER()     \
do {                \
	PRINTM(MENTRY, "Enter: %s\n", __func__);   \
} while (0)
#define LEAVE()     \
do {                \
	PRINTM(MENTRY, "Leave: %s\n", __func__);   \
} while (0)
#define MIN(a, b)		((a) < (b) ? (a) : (b))
#define MAX(a, b)		((a) > (b) ? (a) : (b))
#define memset(adapter, s, c, len) \
	(adapter->callbacks.moal_memset(adapter->pmoal_handle, s, c, len))
#define memmove(adapter, dest, src, len) \
	(adapter->callbacks.moal_memmove(adapter->pmoal_handle, dest, src, len))
#define memcpy(adapter, to, from, len) \
	(adapter->callbacks.moal_memcpy(adapter->pmoal_handle, to, from, len))
#define memcmp(adapter, s1, s2, len) \
	(adapter->callbacks.moal_memcmp(adapter->pmoal_handle, s1, s2, len))
#define NELEMENTS(x)    (sizeof(x)/sizeof(x[0]))
#define SWAP_U8(a, b)	{t_u8 t; t = a; a = b; b = t; }
#define SWAP_U16(a, b)	{t_u16 t; t = a; a = b; b = t; }
#define MNULL                           (0)
#define swap_byte_16(x) \
((t_u16)((((t_u16)(x) & 0x00ffU) << 8) | \
		 (((t_u16)(x) & 0xff00U) >> 8)))
#define swap_byte_32(x) \
((t_u32)((((t_u32)(x) & 0x000000ffUL) << 24) | \
	 (((t_u32)(x) & 0x0000ff00UL) <<  8) | \
	 (((t_u32)(x) & 0x00ff0000UL) >>  8) | \
	 (((t_u32)(x) & 0xff000000UL) >> 24)))
#define swap_byte_64(x) \
((t_u64)((t_u64)(((t_u64)(x) & 0x00000000000000ffULL) << 56) | \
	     (t_u64)(((t_u64)(x) & 0x000000000000ff00ULL) << 40) | \
	     (t_u64)(((t_u64)(x) & 0x0000000000ff0000ULL) << 24) | \
	     (t_u64)(((t_u64)(x) & 0x00000000ff000000ULL) <<  8) | \
	     (t_u64)(((t_u64)(x) & 0x000000ff00000000ULL) >>  8) | \
	     (t_u64)(((t_u64)(x) & 0x0000ff0000000000ULL) >> 24) | \
	     (t_u64)(((t_u64)(x) & 0x00ff000000000000ULL) >> 40) | \
	     (t_u64)(((t_u64)(x) & 0xff00000000000000ULL) >> 56)))
#ifdef BIG_ENDIAN_SUPPORT
#define mlan_ntohl(x) x
#define mlan_htonl(x) x
#define mlan_ntohs(x)  x
#define mlan_htons(x)  x
#define wlan_le16_to_cpu(x) swap_byte_16(x)
#define wlan_le32_to_cpu(x) swap_byte_32(x)
#define wlan_le64_to_cpu(x) swap_byte_64(x)
#define wlan_cpu_to_le16(x) swap_byte_16(x)
#define wlan_cpu_to_le32(x) swap_byte_32(x)
#define wlan_cpu_to_le64(x) swap_byte_64(x)
#define endian_convert_TxPD(x)                                          \
	{                                                                   \
	    (x)->tx_pkt_length = wlan_cpu_to_le16((x)->tx_pkt_length);      \
	    (x)->tx_pkt_offset = wlan_cpu_to_le16((x)->tx_pkt_offset);      \
	    (x)->tx_pkt_type   = wlan_cpu_to_le16((x)->tx_pkt_type);        \
	    (x)->tx_control    = wlan_cpu_to_le32((x)->tx_control);         \
        (x)->tx_control_1  = wlan_cpu_to_le32((x)->tx_control_1);         \
	}
#define endian_convert_RxPD(x)                                          \
	{                                                                   \
	    (x)->rx_pkt_length = wlan_le16_to_cpu((x)->rx_pkt_length);      \
	    (x)->rx_pkt_offset = wlan_le16_to_cpu((x)->rx_pkt_offset);      \
	    (x)->rx_pkt_type   = wlan_le16_to_cpu((x)->rx_pkt_type);        \
	    (x)->seq_num       = wlan_le16_to_cpu((x)->seq_num);            \
        (x)->rx_info       = wlan_le32_to_cpu((x)->rx_info);            \
	    (x)->hi_rx_count32 = wlan_le32_to_cpu((x)->hi_rx_count32);      \
	    (x)->lo_rx_count16 = wlan_le16_to_cpu((x)->lo_rx_count16);      \
	}
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

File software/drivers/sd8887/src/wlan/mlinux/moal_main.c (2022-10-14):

/** @file moal_main.c
  *
  * @brief This file contains the major functions in WLAN
  * driver.
  *
  *
  * Copyright 2014-2021 NXP
  *
  * This software file (the File) is distributed by NXP
  * under the terms of the GNU General Public License Version 2, June 1991
  * (the License).  You may use, redistribute and/or modify the File in
  * accordance with the terms and conditions of the License, a copy of which
  * is available by writing to the Free Software Foundation, Inc.,
  * 51 Franklin Street, Fifth Floor, Boston, MA 02110-1301 USA or on the
  * worldwide web at http://www.gnu.org/licenses/old-licenses/gpl-2.0.txt.
  *
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
  */

/********************************************************
Change log:
    10/21/2008: initial version
********************************************************/

#include	"moal_main.h"
#include    "moal_sdio.h"
#ifdef UAP_SUPPORT
#include    "moal_uap.h"
#endif
#if defined(STA_CFG80211) || defined(UAP_CFG80211)
#include    "moal_cfg80211.h"
#include    "moal_cfgvendor.h"
#endif
#ifdef STA_CFG80211
#ifdef STA_SUPPORT
#include    "moal_sta_cfg80211.h"
#endif
#endif
#ifdef UAP_CFG80211
#ifdef UAP_SUPPORT
#include    "moal_uap_cfg80211.h"
#endif
#endif
#include "moal_eth_ioctl.h"

#include <linux/if_ether.h>
#include <linux/in.h>
#include <linux/tcp.h>
#include <net/tcp.h>
#include <net/dsfield.h>

#ifdef CONFIG_OF
#include <linux/of.h>
#endif

/********************************************************
		Local Variables
********************************************************/

#define KERN_VERSION    "4X"

/** Driver version */
char driver_version[] =
	"SD8887-%s-C" KERN_VERSION "15" MLAN_RELEASE_VERSION
	"-GPL" "-(" "FP" FPNUM ")"
#ifdef	DEBUG_LEVEL2
	"-dbg"
#endif
	" ";

/** Firmware name */
char *fw_name;
int req_fw_nowait;
int fw_reload;

/** MAC address */
char *mac_addr;

#ifdef MFG_CMD_SUPPORT
/** Mfg mode */
int mfg_mode;
#endif

/** SDIO interrupt mode (0: INT_MODE_SDIO, 1: INT_MODE_GPIO) */
int intmode = INT_MODE_SDIO;
/** GPIO interrupt pin number */
int gpiopin;

#ifdef CONFIG_OF
#if defined(STA_CFG80211) || defined(UAP_CFG80211)
extern int disable_regd_by_driver;
/** Region alpha2 string */
extern char *reg_alpha2;
#if CFG80211_VERSION_CODE >= KERNEL_VERSION(3, 14, 0)
extern int country_ie_ignore;
extern int beacon_hints;
#endif
#endif
extern int cfg80211_drcs;
#endif
#if defined(STA_CFG80211) || defined(UAP_CFG80211)
#if CFG80211_VERSION_CODE >= KERNEL_VERSION(3, 8, 0)
extern int host_mlme;
#endif
#endif

int drcs_chantime_mode = 0;

/** Auto deep sleep */
int auto_ds;

/** IEEE PS mode */
int ps_mode;

/** Max Tx buffer size */
int max_tx_buf;

#ifdef STA_SUPPORT
/** Max STA interfaces */
int max_sta_bss = DEF_STA_BSS;
/** STA interface name */
char *sta_name;
#endif

#ifdef UAP_SUPPORT
/** Max uAP interfaces */
int max_uap_bss = DEF_UAP_BSS;
/** uAP interface name */
char *uap_name;
/** Max uAP station number */
int uap_max_sta = 0;
/** WACP mode */
int wacp_mode = 0;
#endif

#if defined(WIFI_DIRECT_SUPPORT)
/** Max WIFIDIRECT interfaces */
int max_wfd_bss = DEF_WIFIDIRECT_BSS;
/** WIFIDIRECT interface name */
char *wfd_name;
#if defined(STA_CFG80211) && defined(UAP_CFG80211)
/** max VIRTUAL bss */
int max_vir_bss = DEF_VIRTUAL_BSS;
#endif
#endif

/** Max NAN interfaces */
int max_nan_bss = DEF_NAN_BSS;
/** NAN interface name */
char *nan_name;

/** PM keep power */
int pm_keep_power = 1;

#ifdef SDIO_SUSPEND_RESUME
/** HS when shutdown */
int shutdown_hs;
#endif

/** SDIO slew rate */
int slew_rate = 3;

#if defined(STA_SUPPORT)
/** 802.11d configuration */
int cfg_11d;
#endif

/** fw serial download check */
int fw_serial = 1;

/** napi support*/
int napi;

/** DPD data config file */
char *dpd_data_cfg;

/** CAL data config file */
char *cal_data_cfg;
/** Init config file (MAC address, register etc.) */
char *init_cfg;

/** Set configuration data of Tx power limitation */
char *txpwrlimit_cfg;
/** Allow setting tx power table of country */
int cntry_txpwr = 0;

/** Init hostcmd file */
char *init_hostcmd_cfg;

#if defined(STA_WEXT) || defined(UAP_WEXT)
/** CFG80211 and WEXT mode */
int cfg80211_wext = STA_WEXT_MASK | UAP_WEXT_MASK;
#else
/** CFG80211 mode */
int cfg80211_wext = STA_CFG80211_MASK | UAP_CFG80211_MASK;
#endif

/** Work queue priority */
int wq_sched_prio;
/** Work queue scheduling policy */
int wq_sched_policy = SCHED_NORMAL;
/** rx_work flag */
int rx_work;

int low_power_mode_enable;

int hw_test;

#ifdef CONFIG_OF
int dts_enable = 1;
#endif

#if defined(WIFI_DIRECT_SUPPORT)
#if defined(STA_CFG80211) && defined(UAP_CFG80211)
#if CFG80211_VERSION_CODE >= WIFI_DIRECT_KERNEL_VERSION
int p2p_enh;
#endif
#endif
#endif

#if CFG80211_VERSION_CODE >= KERNEL_VERSION(3, 14, 0)
int dfs_offload = 0;
#endif

#ifdef ANDROID_KERNEL
int wakelock_timeout = WAKE_LOCK_TIMEOUT;
#endif

/** woal_callbacks */
static mlan_callbacks woal_callbacks = {
	.moal_get_fw_data = moal_get_fw_data,
	.moal_get_hw_spec_complete = moal_get_hw_spec_complete,
	.moal_init_fw_complete = moal_init_fw_complete,
	.moal_shutdown_fw_complete = moal_shutdown_fw_complete,
	.moal_send_packet_complete = moal_send_packet_complete,
	.moal_recv_packet = moal_recv_packet,
	.moal_recv_event = moal_recv_event,
	.moal_ioctl_complete = moal_ioctl_complete,
	.moal_alloc_mlan_buffer = moal_alloc_mlan_buffer,
	.moal_free_mlan_buffer = moal_free_mlan_buffer,

	.moal_write_reg = moal_write_reg,
	.moal_read_reg = moal_read_reg,
	.moal_write_data_sync = moal_write_data_sync,
	.moal_read_data_sync = moal_read_data_sync,
	.moal_malloc = moal_malloc,
	.moal_mfree = moal_mfree,
	.moal_vmalloc = moal_vmalloc,
	.moal_vfree = moal_vfree,
	.moal_memset = moal_memset,
	.moal_memcpy = moal_memcpy,
	.moal_memmove = moal_memmove,
	.moal_memcmp = moal_memcmp,
	.moal_udelay = moal_udelay,
	.moal_get_system_time = moal_get_system_time,
	.moal_get_boot_ktime = moal_get_boot_ktime,
	.moal_usleep = moal_usleep,
	.moal_init_timer = moal_init_timer,
	.moal_free_timer = moal_free_timer,
	.moal_start_timer = moal_start_timer,
	.moal_stop_timer = moal_stop_timer,
	.moal_init_lock = moal_init_lock,
	.moal_free_lock = moal_free_lock,
	.moal_spin_lock = moal_spin_lock,
	.moal_spin_unlock = moal_spin_unlock,
	.moal_print = moal_print,
	.moal_print_netintf = moal_print_netintf,
	.moal_assert = moal_assert,
	.moal_hist_data_add = moal_hist_data_add,
	.moal_updata_peer_signal = moal_updata_peer_signal,
	.moal_do_div = moal_do_div,
};

#if defined(STA_SUPPORT) && defined(UAP_SUPPORT)
#if defined(WIFI_DIRECT_SUPPORT)
int drv_mode = (DRV_MODE_STA | DRV_MODE_UAP | DRV_MODE_WIFIDIRECT);
#else
int drv_mode = (DRV_MODE_STA | DRV_MODE_UAP);
#endif
#else
#ifdef STA_SUPPORT
int drv_mode = DRV_MODE_STA;
#else
int drv_mode = DRV_MODE_UAP;
#endif /* STA_SUPPORT */
#endif /* STA_SUPPORT & UAP_SUPPORT */

int gtk_rekey_offload = GTK_REKEY_OFFLOAD_DISABLE;

int antcfg = 0;

t_u32 uap_oper_ctrl = 0;

int hs_wake_interval = 400;
int indication_gpio = 0xff;

/** all the feature are enabled */
#define DEFAULT_DEV_CAP_MASK 0xffffffff
t_u32 dev_cap_mask = DEFAULT_DEV_CAP_MASK;
int sdio_rx_aggr = MTRUE;
/********************************************************
		Global Variables
********************************************************/

/** Semaphore for add/remove card */
struct semaphore AddRemoveCardSem;
/**
 * The global variable of a pointer to moal_handle
 * structure variable
 **/
moal_handle *m_handle[MAX_MLAN_ADAPTER];

/** The global variable of scan beacon buffer **/
int fixed_beacon_buffer = 0;
/** the pointer of new fwdump fname for each dump**/
char *fwdump_fname = NULL;

#ifdef WIFI_DIRECT_SUPPORT
int GoAgeoutTime = 0;
#endif

t_u16 multi_dtim = 0;

t_u16 inact_tmo = 0;

#ifdef DEBUG_LEVEL1
#ifdef DEBUG_LEVEL2
#define	DEFAULT_DEBUG_MASK	(0xffffffff)
#else
#define DEFAULT_DEBUG_MASK	(MMSG | MFATAL | MERROR)
#endif /* DEBUG_LEVEL2 */
t_u32 drvdbg = DEFAULT_DEBUG_MASK;

#endif /* DEBUG_LEVEL1 */

int woal_open(struct net_device *dev);
int woal_close(struct net_device *dev);
int woal_set_mac_address(struct net_device *dev, void *addr);
void woal_tx_timeout(struct net_device *dev
#if LINUX_VERSION_CODE >= KERNEL_VERSION(5, 6, 0)
		     , unsigned int txqueue
#endif
	);
struct net_device_stats *woal_get_stats(struct net_device *dev);
#if LINUX_VERSION_CODE > KERNEL_VERSION(2, 6, 29)
#if LINUX_VERSION_CODE >= KERNEL_VERSION(3, 13, 0)
#if LINUX_VERSION_CODE >= KERNEL_VERSION(3, 14, 0)
#if LINUX_VERSION_CODE >= KERNEL_VERSION(4, 19, 0)
#if LINUX_VERSION_CODE >= KERNEL_VERSION(5, 2, 0)
u16 woal_select_queue(struct net_device *dev, struct sk_buff *skb,
		      struct net_device *sb_dev);
#else
u16 woal_select_queue(struct net_device *dev, struct sk_buff *skb,
		      struct net_device *sb_dev,
		      select_queue_fallback_t fallback);
#endif
#else
u16 woal_select_queue(struct net_device *dev, struct sk_buff *skb,
		      void *accel_priv, select_queue_fallback_t fallback);
#endif
#else
u16 woal_select_queue(struct net_device *dev, struct sk_buff *skb,
		      void *accel_priv);
#endif
#else
u16 woal_select_queue(struct net_device *dev, struct sk_buff *skb);
#endif
#endif

void woal_sdio_reg_dbg(moal_handle *phandle);

mlan_debug_info info;

static moal_handle *reset_handle;
/** Hang workqueue */
static struct workqueue_struct *hang_workqueue;
/** Hang work */
static struct work_struct hang_work;

/**
 *  @brief This function process FW hang
 *
 *  @param handle       Pointer to structure moal_handle
 *
 *  @return        N/A
 */
static void
woal_hang_work_queue(struct work_struct *work)
{
	int i;
	ENTER();
	if (!reset_handle) {
		LEAVE();
		return;
	}
	for (i = 0; i < reset_handle->priv_num; i++) {
		if (reset_handle->priv[i] && reset_handle->priv[i]->netdev) {
			PRINTM(MMSG, "Close netdev %s\n",
			       reset_handle->priv[i]->netdev->name);
			rtnl_lock();
			dev_close(reset_handle->priv[i]->netdev);
			rtnl_unlock();
			break;
		}
	}
	reset_handle = NULL;
	LEAVE();
}

/**
 *  @brief This function process FW hang
 *
 *  @param handle       Pointer to structure moal_handle
 *
 *  @return        N/A
 */
void
woal_process_hang(moal_handle *handle)
{
	ENTER();
	if (reset_handle == NULL) {
		PRINTM(MMSG, "Start to process hanging\n");
		reset_handle = handle;
		mlan_ioctl(handle->pmlan_adapter, NULL);
		queue_work(hang_workqueue, &hang_work);
#ifdef ANDROID_KERNEL
#define WAKE_LOCK_HANG 5000
#if LINUX_VERSION_CODE >= KERNEL_VERSION(4, 5, 0)
		__pm_wakeup_event(&reset_handle->ws, WAKE_LOCK_HANG);
#else
		wake_lock_timeout(&reset_handle->wake_lock,
				  msecs_to_jiffies(WAKE_LOCK_HANG));
#endif
#endif
	}
	LEAVE();
}

/**
 *  @brief Check if any interface is active
 *
 *  @param handle        A pointer to moal_handle
 *
 *
 *  @return              MTRUE/MFALSE;
 */
t_u8
woal_is_any_interface_active(moal_handle *handle)
{
	int i;
	for (i = 0; i < handle->priv_num; i++) {
		if (!handle->priv[i])
			continue;
#ifdef STA_SUPPORT
		if (GET_BSS_ROLE(handle->priv[i]) == MLAN_BSS_ROLE_STA) {
			if (handle->priv[i]->media_connected == MTRUE)
				return MTRUE;
		}
#endif
#ifdef UAP_SUPPORT
		if (GET_BSS_ROLE(handle->priv[i]) == MLAN_BSS_ROLE_UAP) {
			if (handle->priv[i]->bss_started == MTRUE)
				return MTRUE;
		}
#endif
	}
	return MFALSE;
}

/**
 *  @brief This function handle the net interface ipaddr change event
 *
 *  @param nb      pointer to the notifier_block
 *  @param event   event type
 *  @param ptr     pointer to event struct
 *
 *  @return        NOTIFY_DONE or NOTIFY_OK
 */
static int
woal_netdevice_event(struct notifier_block *nb, unsigned long event, void *ptr)
{
	struct in_ifaddr *ifa = (struct in_ifaddr *)ptr;
	struct net_device *ndev;
	moal_private *priv;

	int ret = NOTIFY_OK;
#ifdef STA_CFG80211
	char rssi_low[11];
#endif
	ENTER();

	ndev = ifa->ifa_dev->dev;
#if LINUX_VERSION_CODE > KERNEL_VERSION(2, 6, 29)
	if (!ndev || ndev->netdev_ops->ndo_open != woal_open)
#else
	if (!ndev || ndev->open != woal_open)
#endif
	{
		PRINTM(MIOCTL, "IP changes not for us, ignore. ndev[%p]\n",
		       ndev);
		if (ndev)
			PRINTM(MIOCTL, "changes on %s\n", ndev->name);
		ret = NOTIFY_DONE;
		goto done;
	}
	priv = (moal_private *)netdev_priv(ndev);
	if (priv->bss_type != MLAN_BSS_TYPE_STA
#if defined(WIFI_DIRECT_SUPPORT)
	    && priv->bss_type != MLAN_BSS_TYPE_WIFIDIRECT
#endif
	    && priv->bss_type != MLAN_BSS_TYPE_NAN) {
		PRINTM(MIOCTL, "Bss type [%d] is not STA/P2P, ignore\n",
		       (int)priv->bss_type);
		ret = NOTIFY_DONE;
		goto done;
	}

	switch (event) {
	case NETDEV_UP:
		PRINTM(MIOCTL, "[%s]: New ip addr: 0x%08x\n", ndev->name,
		       ifa->ifa_address);
		/* Save the IP addr now */
		memcpy(priv->ip_addr, &ifa->ifa_address,
		       sizeof(ifa->ifa_address));
		priv->ip_addr_type = IPADDR_TYPE_IPV4;
#ifdef STA_CFG80211
		if (!hw_test && priv->roaming_enabled) {
			snprintf(rssi_low, sizeof(rssi_low), "%d",
				 priv->rssi_low);
			woal_set_rssi_low_threshold(priv, rssi_low,
						    MOAL_IOCTL_WAIT);
		}
#endif
		break;
	case NETDEV_DOWN:
		PRINTM(MIOCTL, "[%s]: Ip addr removed.\n", ndev->name);
		priv->ip_addr_type = IPADDR_TYPE_NONE;
		memset(priv->ip_addr, 0, sizeof(priv->ip_addr));
		break;
	default:
		PRINTM(MIOCTL, "[%s]: Ignore event: %u\n", ndev->name,
		       (unsigned int)event);
		ret = NOTIFY_DONE;
		goto done;
	}

done:
	LEAVE();
	return ret;
}

/**
 *  @brief This function validates a SSID as being able to be printed
 *
 *  @param pssid   SSID structure to validate
 *
 *  @return        MTRUE or MFALSE
 */
BOOLEAN
woal_ssid_valid(mlan_802_11_ssid *pssid)
{
#ifdef ASCII_SSID_CHECK
	unsigned int ssid_idx;

	ENTER();

	for (ssid_idx = 0; ssid_idx < pssid->ssid_len; ssid_idx++) {
		if ((pssid->ssid[ssid_idx] < 0x20) ||
		    (pssid->ssid[ssid_idx] > 0x7e)) {
			LEAVE();
			return MFALSE;
		}
	}
	LEAVE();
#endif
	return MTRUE;
}

#if defined(STA_CFG80211) || defined(UAP_CFG80211)
#if CFG80211_VERSION_CODE >= KERNEL_VERSION(2, 6, 39)
/**
 *  @brief Remain on Channel timeout function
 *
 *  @param context  A pointer to context
 *  @return         N/A
 */
void
woal_remain_timer_func(void *context)
{
	moal_handle *handle = (moal_handle *)context;
	moal_private *priv = handle->priv[handle->remain_bss_index];

	ENTER();

	PRINTM(MEVENT, "remain_timer fired.\n");
	if (handle->cookie) {
		cfg80211_remain_on_channel_expired(
#if CFG80211_VERSION_CODE < KERNEL_VERSION(3, 6, 0)
							  priv->netdev,
#else
							  priv->wdev,
#endif
							  handle->cookie,
							  &handle->chan,
#if CFG80211_VERSION_CODE < KERNEL_VERSION(3, 8, 0)
							  handle->channel_type,
#endif
							  GFP_ATOMIC);
		handle->cookie = 0;
	}
	handle->is_remain_timer_set = MFALSE;

	LEAVE();
	return;
}
#endif
#endif

#if defined(WIFI_DIRECT_SUPPORT)
#if defined(STA_CFG80211) && defined(UAP_CFG80211)
/**
 *  @brief GO timeout function
 *
 *  @param context  A pointer to context
 *  @return         N/A
 */
void
woal_go_timer_func(void *context)
{
	moal_handle *handle = (moal_handle *)context;

	ENTER();

	PRINTM(MEVENT, "go_timer fired.\n");
	handle->is_go_timer_set = MFALSE;

	LEAVE();
	return;
}
#endif
#endif

/**
 *  @brief check if we already connect to the AP.
 *  @param priv         A pointer to moal_private structure
 *  @param ssid_bssid   A pointer to mlan_ssid_bssid structure
 *
 *  @return             MTRUE/MFALSE;
 */
int
woal_is_connected(moal_private *priv, mlan_ssid_bssid *ssid_bssid)
{
	mlan_bss_info bss_info;
	int ret = MFALSE;
	t_u8 zero_mac[] = { 0, 0, 0, 0, 0, 0 };
	ENTER();
	memset(&bss_info, 0, sizeof(bss_info));
	if (MLAN_STATUS_SUCCESS !=
	    woal_get_bss_info(priv, MOAL_IOCTL_WAIT, &bss_info))
		goto done;
	if (bss_info.media_connected) {
		if (memcmp(ssid_bssid->bssid, zero_mac, sizeof(zero_mac))) {
			if (ssid_bssid->ssid.ssid_len) {	/* compare ssid and bssid */
				if ((ssid_bssid->ssid.ssid_len ==
				     bss_info.ssid.ssid_len) &&
				    !memcmp(ssid_bssid->ssid.ssid,
					    bss_info.ssid.ssid,
					    bss_info.ssid.ssid_len) &&
				    !memcmp(ssid_bssid->bssid, bss_info.bssid,
					    MLAN_MAC_ADDR_LENGTH))
					ret = MTRUE;
			} else {	/* compare bssid */
				if (!memcmp
				    (ssid_bssid->bssid, bss_info.bssid,
				     MLAN_MAC_ADDR_LENGTH)) {
					memcpy(&ssid_bssid->ssid,
					       &bss_info.ssid,
					       sizeof(bss_info.ssid));
					ret = MTRUE;
				}
			}
		} else {	/* compare ssid */
			if (ssid_bssid->ssid.ssid_len &&
			    (ssid_bssid->ssid.ssid_len ==
			     bss_info.ssid.ssid_len) &&
			    !memcmp(ssid_bssid->ssid.ssid, bss_info.ssid.ssid,
				    bss_info.ssid.ssid_len)) {
				memcpy(&ssid_bssid->bssid, &bss_info.bssid,
				       MLAN_MAC_ADDR_LENGTH);
				ret = MTRUE;
			}
		}
	}
done:
	LEAVE();
	return ret;
}

/**
 * @brief Look up specific IE in a buf
 *
 * @param ie              Pointer to IEs
 * @param len             Total length of ie
 * @param id              Element id to lookup
 *
 * @return                Pointer of the specific IE -- success, NULL -- fail
 */
const t_u8 *
woal_parse_ie_tlv(const t_u8 *ie, int len, t_u8 id)
{
	int left_len = len;
	const t_u8 *pos = ie;
	int length;

	/* IE format:
	 * |   u8  |   id   |
	 * |   u8  |   len  |
	 * |   var |   data |
	 */
	while (left_len >= 2) {
		length = *(pos + 1);
		if ((*pos == id) && (length + 2) <= left_len)
			return pos;
		pos += (length + 2);
		left_len -= (length + 2);
	}

	return NULL;
}

/**
 *  @brief Get mode
 *
 *  @param priv          A pointer to moal_private structure
 *  @param wait_option   Wait option (MOAL_IOCTL_WAIT or MOAL_NO_WAIT)
 *
 *  @return              Wireless mode
 */
t_u32
woal_get_mode(moal_private *priv, t_u8 wait_option)
{
	int ret = 0;
	mlan_ds_bss *bss = NULL;
	mlan_ioctl_req *req = NULL;
	mlan_status status = MLAN_STATUS_SUCCESS;
	t_u32 mode = 0;

	ENTER();

#if defined(STA_WEXT) || defined(UAP_WEXT)
	mode = priv->w_stats.status;
#endif
	/* Allocate an IOCTL request buffer */
	req = woal_alloc_mlan_ioctl_req(sizeof(mlan_ds_bss));
	if (req == NULL) {
		ret = -ENOMEM;
		goto done;
	}

	/* Fill request buffer */
	bss = (mlan_ds_bss *)req->pbuf;
	bss->sub_command = MLAN_OID_BSS_MODE;
	req->req_id = MLAN_IOCTL_BSS;
	req->action = MLAN_ACT_GET;

	/* Send IOCTL request to MLAN */
	status = woal_request_ioctl(priv, req, wait_option);
	if (status == MLAN_STATUS_SUCCESS) {
		switch (bss->param.bss_mode) {
		case MLAN_BSS_MODE_INFRA:
			mode = MW_MODE_INFRA;
			break;
		case MLAN_BSS_MODE_IBSS:
			mode = MW_MODE_ADHOC;
			break;
		default:
			mode = MW_MODE_AUTO;
			break;
		}
	}
done:
	if (status != MLAN_STATUS_PENDING)
		kfree(req);
	LEAVE();
	return mode;
}

/********************************************************
		Local Functions
********************************************************/
/**
 *  @brief This function update the default firmware name
 *
 *  @param handle           A pointer to moal_handle structure
 *
 *  @return        N/A
 */
static void
woal_update_firmware_name(moal_handle *handle)
{
	if (fw_name) {
		handle->drv_mode.fw_name = fw_name;
	} else {
		if (!fw_serial || handle->fw_reload || fw_reload)
			handle->drv_mode.fw_name = DEFAULT_WLAN_FW_NAME;
		else
#if defined(UAP_SUPPORT) && defined(STA_SUPPORT)
			handle->drv_mode.fw_name = DEFAULT_AP_STA_FW_NAME;
#else
#ifdef UAP_SUPPORT
			handle->drv_mode.fw_name = DEFAULT_AP_FW_NAME;
#else
			handle->drv_mode.fw_name = DEFAULT_FW_NAME;
#endif /* UAP_SUPPORT */
#endif /* UAP_SUPPORT && STA_SUPPORT */
	}
}

/**
 *  @brief This function dynamically populates the driver mode table
 *
 *  @param handle           A pointer to moal_handle structure
 *  @param drv_mode_local   Driver mode
 *
 *  @return        MLAN_STATUS_SUCCESS or MLAN_STATUS_FAILURE
 */
mlan_status
woal_update_drv_tbl(moal_handle *handle, int drv_mode_local)
{
	mlan_status ret = MLAN_STATUS_SUCCESS;
	unsigned int intf_num = 0;
	int i = 0, j = 0;
	mlan_bss_attr *bss_tbl = NULL;
#if defined(WIFI_DIRECT_SUPPORT)
#if defined(STA_CFG80211) && defined(UAP_CFG80211)
	int last_wfd_index = 0;
#endif
#endif

	ENTER();

	/* Calculate number of interfaces */
#ifdef STA_SUPPORT
	if (drv_mode_local & DRV_MODE_STA) {
		if ((max_sta_bss < 1) || (max_sta_bss > MAX_STA_BSS)) {
			PRINTM(MWARN,
			       "Unsupported max_sta_bss (%d), setting to default\n",
			       max_sta_bss);
			max_sta_bss = DEF_STA_BSS;
		}
		intf_num += max_sta_bss;
	}
#endif /* STA_SUPPORT */

#ifdef UAP_SUPPORT
	if (drv_mode_local & DRV_MODE_UAP) {
		if ((max_uap_bss < 1) || (max_uap_bss > MAX_UAP_BSS)) {
			PRINTM(MWARN,
			       "Unsupported max_uap_bss (%d), setting to default\n",
			       max_uap_bss);
			max_uap_bss = DEF_UAP_BSS;
		}
		intf_num += max_uap_bss;
	}
#endif /* UAP_SUPPORT */

#if defined(WIFI_DIRECT_SUPPORT)
	if (drv_mode_local & DRV_MODE_WIFIDIRECT) {
		if ((max_wfd_bss < 1) || (max_wfd_bss > MAX_WIFIDIRECT_BSS)) {
			PRINTM(MWARN,
			       "Unsupported max_wfd_bss (%d), setting to default\n",
			       max_wfd_bss);
			max_wfd_bss = DEF_WIFIDIRECT_BSS;
		}
		intf_num += max_wfd_bss;
#if defined(STA_CFG80211) && defined(UAP_CFG80211)
		intf_num += max_vir_bss;
#endif
	}
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

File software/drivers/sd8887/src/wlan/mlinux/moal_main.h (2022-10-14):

/** @file moal_main.h
  *
  * @brief This file contains wlan driver specific defines etc.
  *
  *
  * Copyright 2014-2021 NXP
  *
  * This software file (the File) is distributed by NXP
  * under the terms of the GNU General Public License Version 2, June 1991
  * (the License).  You may use, redistribute and/or modify the File in
  * accordance with the terms and conditions of the License, a copy of which
  * is available by writing to the Free Software Foundation, Inc.,
  * 51 Franklin Street, Fifth Floor, Boston, MA 02110-1301 USA or on the
  * worldwide web at http://www.gnu.org/licenses/old-licenses/gpl-2.0.txt.
  *
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
  */

/********************************************************
Change log:
    10/21/2008: initial version
********************************************************/

#ifndef _MOAL_MAIN_H
#define _MOAL_MAIN_H

/* warnfix for FS redefination if any? */
#ifdef FS
#undef FS
#endif

/* Linux header files */
#include        <linux/kernel.h>
#include        <linux/module.h>
#include        <linux/init.h>
#include        <linux/version.h>
#include        <linux/param.h>
#include        <linux/delay.h>
#include        <linux/slab.h>
#include        <linux/mm.h>
#include        <linux/types.h>
#include        <linux/sched.h>
#include        <linux/timer.h>
#include        <linux/ioport.h>
#include        <linux/pci.h>
#include        <linux/ctype.h>
#include        <linux/proc_fs.h>
#include        <linux/vmalloc.h>
#include        <linux/ptrace.h>
#include        <linux/string.h>
#include        <linux/irqreturn.h>
#if LINUX_VERSION_CODE >= KERNEL_VERSION(3, 1, 0)
#include        <linux/namei.h>
#include        <linux/fs.h>
#endif

#if LINUX_VERSION_CODE < KERNEL_VERSION(2, 6, 18)
#include       <linux/config.h>
#endif

/* ASM files */
#if LINUX_VERSION_CODE >= KERNEL_VERSION(2, 6, 27)
#include        <linux/semaphore.h>
#else
#include        <asm/semaphore.h>
#endif
#include        <asm/byteorder.h>
#include        <asm/irq.h>
#include        <asm/uaccess.h>
#include        <asm/io.h>
#if LINUX_VERSION_CODE >= KERNEL_VERSION(3, 4, 0)
#include        <asm/switch_to.h>
#else
#include        <asm/system.h>
#endif

#include        <linux/spinlock.h>

/* Net header files */
#include        <linux/netdevice.h>
#include        <linux/net.h>
#include        <linux/inet.h>
#include        <linux/ip.h>
#include        <linux/skbuff.h>
#include        <linux/if_arp.h>
#include        <linux/if_ether.h>
#include        <linux/etherdevice.h>
#include        <net/sock.h>
#include        <net/arp.h>
#include        <linux/rtnetlink.h>
#include        <linux/inetdevice.h>

#include	<linux/firmware.h>

#ifdef ANDROID_KERNEL
#if LINUX_VERSION_CODE >= KERNEL_VERSION(4, 5, 0)
#include <linux/pm_wakeup.h>
#include <linux/device.h>
#else
#include <linux/wakelock.h>
#endif
#endif

#include        "mlan.h"
#include        "moal_shim.h"
/* Wireless header */
#if defined(STA_CFG80211) || defined(UAP_CFG80211)
#include        <net/lib80211.h>
#include        <net/cfg80211.h>
#include        <net/ieee80211_radiotap.h>
#endif
#if defined(STA_WEXT) || defined(UAP_WEXT)
#include        <linux/wireless.h>
#include        <net/iw_handler.h>
#include        "moal_wext.h"
#endif
#ifdef STA_WEXT
#include        "moal_priv.h"
#endif

#ifndef MIN
/** Find minimum */
#define MIN(a, b)		((a) < (b) ? (a) : (b))
#endif

/** Find maximum */
#ifndef MAX
#define MAX(a, b)                ((a) > (b) ? (a) : (b))
#endif
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

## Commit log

2018-09-12 schematics init
2018-12-10 Added additional information regarding silkscreen symbols and Phoenix.
2019-01-08 support both cam/disp and double camera setup for Fin 1.1.0
2019-01-10 prefix: Added temperature range errata
    Change-type: patch
2019-01-16 Add case datasheet
    Change-type: minor
2019-01-16 Add Fin CAD to docs
    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
2019-01-16 Remove unnecesary power legend
    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
2019-01-16 Add datasheet for modular case
    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
2019-01-16 Add revision history for case datasheet
    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
2019-01-16 Rename case datasheet for maintaining consistency
    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
2019-01-16 Add case CAD
    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
2019-01-16 Improve readability of case datasheet
    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
2019-01-31 Create user guide document for DIN case
2019-02-09 Add phoenix HAT and IDC cable to datasheet
    Improved visuals of the rest of the case datasheet images
    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
2019-02-21 update PCB mapping and definitions
    update bottom PCB mapping and definitions
    update top PCB mapping and definitions
    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
2019-02-21 Add reference to the Fuses we have on the HAT and PWR IN
    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
2019-02-21 fix fuses ordering
    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
2019-02-21 Add missing pointer to device mapping ID for RF switch when mentioned
    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
2019-02-21 compress device mapping images
    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
2019-02-21 Add V1.1 schematics
    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
2019-02-22 fix temperature range min value
    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
2019-02-22 add v1.1 CAD file
    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
2019-02-22 update index for v1.1 CAD file
    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
2019-07-11 Fix HAT pinout on phoenix case
    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
2020-11-23 Added blind-ring stl and step files
    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
2020-12-03 balena-fin-overlay: Update for kernel 5.4
    The base for these overlays file is the upstream linux-raspberrypi
    kernel overlay at tag `raspberrypi-kernel_1.20201022-1`:
    https://github.com/raspberrypi/linux/blob/raspberrypi-kernel_1.20201022-1/arch/arm/boot/dts/overlays/balena-fin-overlay.dts
    It then includes the following modifications:
    * Use pwrseq-simple to power on the SD8787 WiFi.
    In meta-balena we use a modified built-in pwrseq-sd8777 driver. The
    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
2020-12-07 Added dxf files, created a folder for the 3D files
    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
    [TOPOBOTTOM.dxf, TOPOTOP.DXF]
2021-04-27 Added source and instruction for building sd8887 driver
    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
2021-04-29 Added the PDF schematic for the v1.1.1
2021-06-03 Y2K38 timestamp tweaks
    Required to support Linux kernel 5.6 and later.
    Changes were borrowed from the following branch from the forked mxm_wifiex driver
    maintained by NXP:
    https://source.codeaurora.org/external/nxpwifi/mwifiex/log/?h=caf/lf-5.10.y_1.0.0
    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
2021-06-03 Port woal_cfg80211_mgmt_frame_register
    Required to support Linux kernel 5.8 and later.
    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
2021-06-03 Port file_operations to proc_ops
    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
2021-06-03 Y2K38 tweaks for the bluetooth driver
    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
2021-06-03 Port file_operations to proc_ops for the bluetooth driver
    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
2021-12-15 updated case files
    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
    [Bling ring.stl, Fin ring.stl, Phoenix ring.stl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]
2022-01-11 Fixes balenaFin v1.1 voltage range in docs
    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
2022-02-24 Updated case dimensions on the datasheet images
    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
2022-02-25 updated version of the case datasheet md
    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
2022-02-25 Added updated case pdf
    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
2022-04-01 corrected battery type
    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
2022-11-16 Switch from balenaCI to flowzone
    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
2022-11-16 Add simple npm test to satisfy Flowzone
    Technically this is an npm repo (it builds the PDFs) and Flowzone
    noticed. When it tried to run the npm tests, later versions of npm fail
    if there's no test specified. This is an attempt to satisfy the
    requirement for a test, using the simplest, representative test possible
    - just run the program. If it runs successfully, the test passes.
    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
2022-11-16 Remove protect-branch safety
    Let Flowzone take effect.
    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
